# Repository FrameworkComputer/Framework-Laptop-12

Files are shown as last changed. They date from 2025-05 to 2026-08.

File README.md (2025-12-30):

# Framework Laptop 12
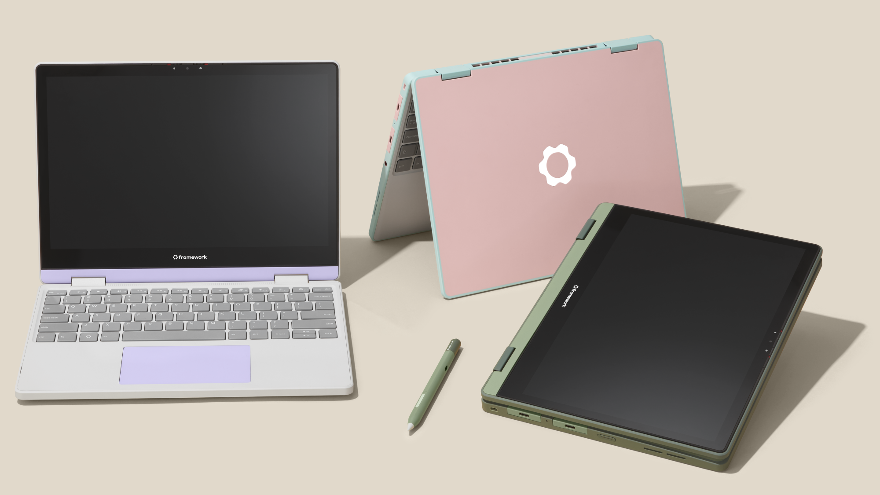
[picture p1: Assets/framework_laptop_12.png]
FrameworkLaptop12


Documentation around the Mainboard and other key parts of Framework Laptop 12 
(available at https://frame.work/marketplace/mainboards).

We designed Framework Laptop 12 to enable re-use of key modules like the Mainboard.
The Mainboard is operable as a standalone single board computer outside of the laptop,
with a smaller form factor relative to Framework Laptop 13.

## License

Framework Laptop 12 © 2024 by Framework Computer Inc is licensed under CC BY 4.0.
To view a copy of this license, visit http://creativecommons.org/licenses/by/4.0/

## 3D CAD (in the base directory)

External 3D CAD of the system and main modules to enable development of 3D-printed replacement parts,
skins, cases, and other accessories.  We're excited to see what you do with it!

## Mainboard
This folder contains interface and CAD documentation to enable Mainboard re-use.

## Input Cover

This folder contains interface documentation to enable Input Cover re-use.

## Display

Mechanical design files and pinout of the display.

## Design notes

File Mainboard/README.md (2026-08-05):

# Mainboard

## License

Framework Laptop 12 © 2024 by Framework Computer Inc is licensed under CC BY 4.0.
To view a copy of this license, visit http://creativecommons.org/licenses/by/4.0/

## Pinouts

### Webcam Interface

This is the interface to the webcam module.
This module has not only the webcam but also an accelerometer and a dual-output Hall Sensor.

| Pin | Signal | Notes |
|-----|--- |---|
| 1 | 3VL_EC | |
| 2 | TABLET_MODE# | Hall sensor tablet mode |
| 3 | LID_SW# | Hall sensor lid closed  |
| 4 | ACC_INT | G-Sensor interrupt |
| 5 | GND | |
| 6 | USB_DM | Camera USB |
| 7 | USB_DP | Camera USB |
| 8 | 3VS_CAM | Camera IC Power |
| 9 | CAM_SW | Camera privacy switch |
| 10  | DMIC_CLK | Digital Microphone |
| 11  | DMIC_DATA | Digital Microphone |
| 12  | MIC_SW | Mic privacy switch |
| 13  | ALS_INT# | Reserved |
| 14  | I2C_SCL | Accelerometer I2C |
| 15  | I2C_SDA | Accelerometer I2C |
| 16  | OS_DET_CAM | Reserved, pullup |
| 17  | GND | |
| 18  | NC | |
| 19  | NC | |
| 20  | NC | |

## Display Interface

IPEX 20879-030E connector used to interface to an eDP display.  Note that there are signals
defined for the I2C touchscreen. Note that pin 1 is on the left when looking at the receptacle on the Mainboard.

| Pin | Signal | Notes |
|-----|--- |---|
| 1 | PWR | Backlight power |
| 2 | PWR | |
| 3 | PWR | |
| 4 | NC | |
| 5 | GND | |
| 6 | GND | |
| 7 | EDP_AUXN | |
| 8 | EDP_AUXP | |
| 9 | GND | |
| 10  | EDP_TXP0 | |
| 11  | EDP_TXN0 | |
| 12  | GND | |
| 13  | EDP_TXN1 | |
| 14  | EDP_TXP1 | |
| 15  | GND | |
| 16  | EDP_HPD | Hotplug |
| 17  | BLK_PWM_LCD  | Backlight PWM |
| 18  | BKOFF# | Backlight enable |
| 19  | 3VS_EDP | |
| 20  | 3VS_EDP | |
| 21  | 3VS_EDP | |
| 22  | 3VS_TS | |
| 23  | 3VS_TS | |
| 24  | TS_EN | |
| 25  | TS_RST | |
| 26  | TS_INT# | |
| 27  | I2C_SDA | Touch I2C |
| 28  | I2C_SCL | Touch I2C |
| 29  | OS_DET_TS | Reserved, pullup |
| 30  | GND | |

## Audio Daughterboard Interface

Pin 1 is top left, counting zigzag left, right, left, right downwards.

| Pin | Signal |
|-----|---|
| 1 | SLEEVE |
| 2 | HPOUT_R |
| 3 | RING |
| 4 | A_GND |
| 5 | GND |
| 6 | HPOUT_L |
| 7 | JACK_PLUG |
| 8 | BOARD_ID  |
| 9 | SPK_L- |
| 10  | SPK_R- |
| 11  | SPK_L+ |
| 12  | SPK_R+ |

## Power Button Daughterboard Interface

Pin 1 is top left, counting zigzag left, right, left, right downwards.

| Pin | Signal | Notes |
|-----|---|---|
| 1 | USB_DP | USB2.0 Reserved |
| 2 | BOARD_ID | |
| 3 | USB_DM | USB2.0 Reserved |
| 4 | GND | |
| 5 | 3V_MCU | 3V Reserved |
| 6 | ON_OFF_BTN# | System Power Button |
| 7 | LED_PWM | Power Button LED |
| 8 | 5V_LED | Power Button LED |

## Battery 

Pin 1 is the left-most.

| Pin | Signal | Notes  |
|-----|---|---|
| 1 | BAT+ | 13.5V  |
| 2 | BAT+ | 13.5V  |
| 3 | VRTC | |
| 4 | DAT_SMB  | SMBus  |
| 5 | CLK_SMB  | SMBus  |
| 6 | SYS_PRES | |
| 7 | GND | |
| 8 | GND | |

The battery provides VRTC voltage to serve as RTC batteyr.

## Input Cover Interface

Connection is made through two sets of 10 pogo pins.
Pin count from left to right.

| Conn | Pin | Signal | Notes |
|---|-----|---|---|
| JTP1 | 1 | 5VS_TP | |
| JTP1 | 2 | KBL_P | |
| JTP1 | 3 | 3VS_TP | |
| JTP1 | 4 | TP_I2C_CLK | Touchpad I2C |
| JTP1 | 5 | TP_I2C_SDA | Touchpad I2C |
| JTP1 | 6 | TP_INT# | |
| JTP1 | 7 | BOARD_ID | |
| JTP1 | 8 | KB_I2C_SCL | Keyboard I2C |
| JTP1 | 9 | KB_I2C_SDA | Keyboard I2C |
| JTP1 | 10  | KB_INT | Keyboard I2C |
| JTP2 | 1 | KSI_03_IN  | Shorted to pin 2 |
| JTP2 | 2 | KSI_03_OUT | Shorted to pin 1 |
| JTP2 | 3 | KSI_02_IN  | Shorted to pin 4 |
| JTP2 | 4 | KSI_02_OUT | Shorted to pin 3 |
| JTP2 | 5 | KSI_00_IN  | Shorted to pin 6 |
| JTP2 | 6 | KSI_00_OUT | Shorted to pin 5 |
| JTP2 | 7 | GND | |
| JTP2 | 8 | GND | |
| JTP2 | 9 | GND | |
| JTP2 | 10  | GND | |

Keyboard scan and capslock LED control is going through the I2C keyboard controller.

## Fan Interface

Hefeng AWA02-S04FIA-HF connector for the Fan.  Note that there are many other footprint
compatible 4-pin connectors that are likely compatible. This kind of connector is also known
as "JST SH", and has a 1.0 mm pitch. The same connector is used for the Speakers.

Pin 1 is further away from the speaker assembly.

| Pin | Signal |
|-----|---|
| 1 | 5V |
| 2 | FAN_SPEED |
| 3 | FAN_PWM |
| 4 | GND |

## RTC Battery Interface

NOTE: The mainboard will charge this battery, so a rechargable ML1220 battery must be used.
CR2032 is not okay because it cannot be charged.

Settings are kept alive by the normal system battery. The only case where an
RTC battery is needed, is when the system is used in standalone mode (without a battery).

Cvilux CVILU_CI4402M1HRC-NH connector for the RTC Battery.

| Pin | Signal | Location |
|-----|---|---|
| 1 | +RTCBATT  | Left |
| 2 | GND | Right |

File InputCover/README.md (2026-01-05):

# Input Cover

## License

Framework Laptop 12 © 2025 by Framework Computer Inc is licensed under CC BY 4.0.
To view a copy of this license, visit http://creativecommons.org/licenses/by/4.0/

## Layout

The input cover includes the touchpad and keyboard.
There is one main PCB, which we will call the touchpad PCB.
It includes the Pixart PCT2642QC (PLP239 Family) touchpad IC and IT8801 keyboard controler.

The keyboard matrix connects to the touchpad PCB through an FPC connector.

## Touchpad Module Details

For details about the touchpad module, including silkscreen and firmware,
please refer to [Touchpad.md].

## Pinouts

### Touchpad PCB to Mainboard

Connection is made through an FPC daughterboard that has pads for two sets of 10 pogo pins.
See the pinout for that on the mainboard README.md

Pinout for FPC connector on the touchpad PCB to the pogo pin daughterboard.
The `5VS_TP` and `KBL_P` pins are duplicated on this FPC connector, but not on the pogo pins.

KSI0, KSI3, and KSO2 are routed to the mainboard and back out for the possibility of letting a future mainboard scan the F1 and F2 keys directly, bypasing the keyboard controller IC.
On current hardware IN OUT pins are just shorted together on the mainboard.

| Pin | Signal | Notes |
|-----|---|---|
| 1 | 5VS_TP | |
| 2 | 5VS_TP | |
| 3 | KBL_P | |
| 4 | KBL_P | |
| 5 | 3VS_TP | |
| 6 | TP_I2C_CLK | Touchpad I2C |
| 7 | TP_I2C_SDA | Touchpad I2C |
| 8 | TP_INT# | |
| 9 | BOARD_ID | |
| 10  | KB_I2C_SCL | Keyboard I2C |
| 11  | KB_I2C_SDA | Keyboard I2C |
| 12  | KB_INT | Keyboard I2C |
| 13  | KSI_03_IN  | |
| 14  | KSI_03_OUT | |
| 15  | KSI_02_IN  | |
| 16  | KSI_02_OUT | |
| 17  | KSI_00_IN  | |
| 18  | KSI_00_OUT | |
| 19  | GND | |
| 20  | GND | |
| 21  | GND | |
| 22  | GND | |

### Touchpad to Keyboard

| Pin | Signal |
|-----|---|
| 1 | KSI_00_IN  |
| 2 | KSI1 |
| 3 | KSI2 |
| 4 | KSI_03_IN  |
| 5 | KSI4 |
| 6 | KSI5 |
| 7 | KSI6 |
| 8 | KSI7 |
| 9 | KSO0 |
| 10  | KSO1 |
| 11  | KSO_02_IN  |
| 12  | KSO3 |
| 13  | KSO4 |
| 14  | KSO5 |
| 15  | KSO6 |
| 16  | KSO7 |
| 17  | KSO8 |
| 18  | KSO9 |
| 19  | KSO10 |
| 20  | KSO11 |
| 21  | KSO12 |
| 22  | KSO13 |
| 23  | KSO14 |
| 24  | KSO15 |
| 25  | KSO16 |
| 26  | KSO17 |
| 27  | CAPS_P |
| 28  | CAPS_N |

## Keyboard

### Keyboard Matrix

ANSI layout:

```
┌─────┬───┬───┬───┬───┬───┬───┬───┬───┬───┬───┬───┬───┬────┐
│ Esc │F1 │F2 │F3 │F4 │F5 │F6 │F7 │F8 │F9 │F10│F11│F12│ Del│
├───┬─┴─┬─┴─┬─┴─┬─┴─┬─┴─┬─┴─┬─┴─┬─┴─┬─┴─┬─┴─┬─┴─┬─┴─┬─┴────┤
│ ` │ 1 │ 2 │ 3 │ 4 │ 5 │ 6 │ 7 │ 8 │ 9 │ 0 │ - │ = │Backsp│
├───┴─┬─┴─┬─┴─┬─┴─┬─┴─┬─┴─┬─┴─┬─┴─┬─┴─┬─┴─┬─┴─┬─┴─┬─┴─┬────┤
│ Tab │ Q │ W │ E │ R │ T │ Y │ U │ I │ O │ P │ [ │ ] │ \  │
├─────┴┬──┴┬──┴┬──┴┬──┴┬──┴┬──┴┬──┴┬──┴┬──┴┬──┴┬──┴┬──┴────┤
│ Caps │ A │ S │ D │ F │ G │ H │ J │ K │ L │ ; │ ' │ Enter │
├──────┴─┬─┴─┬─┴─┬─┴─┬─┴─┬─┴─┬─┴─┬─┴─┬─┴─┬─┴─┬─┴─┬─┴───────┤
│ Shift  │ Z │ X │ C │ V │ B │ N │ M │ , │ . │ / │  Shift  │
├────┬───┼───┼───┼───┴───┴───┴───┴───┼───┼───┼───┴┬───┬────┤
│    │   │   │   │                   │   │   │    │ ↑ │    │
│Ctrl│FN │WIN│Alt│                   │Alt│Ctl│ ←  ├───┤  → │
│    │   │   │   │                   │   │   │    │ ↓ │    │
└────┴───┴───┴───┴───────────────────┴───┴───┴────┴───┴────┘
|     |Col 0|Col 1|Col 2|Col 3|Col 4|Col 5|Col 6|Col 7|Col 8|Col 9|Col10|Col11|Col12|Col13|Col14|Col15|Col16|Col17|
|Row 0|     | F11 | F1  | B   | F10 | N   |     |     | =   |     |RAlt |     |     |     |     |     | FN  |     |
|Row 1|     | ESC | F4  | G   | F7  | F12 | H   |     | '   | F9  |     | Bsp |     |     |LCtrl|     |     |     |
|Row 2|     | TAB | F3  | T   | F6  | ]   | Y   |     | [   | Del |     | F8  |     |     |     |     |     |     |
|Row 3| WIN | `   | F2  | 5   | S   |     | -   |     | 6   |     |     | \   |     |     |RCtrl|     |     |     |
|Row 4|     | A   | D   | F   | F5  | K   | J   |     | ;   | L   |     |Enter|     |     |     |     |     |     |
|Row 5|     | 1   | ,   | >   | /   | C   |Space|LShft| X   | V   |     | M   |     |     |     |     |     |     |
|Row 6|     | Z   | 3   | 4   | 2   | 8   | 0   |     | 7   | 9   |     | Down|Left |LAlt |     |CapsL|     |     |
|Row 7|     | U   | I   | O   | P   | Q   | W   |RShft| E   | R   |     | Up  |Right|     |     |     |     |     |
```

ISO Layout:

```
┌─────┬───┬───┬───┬───┬───┬───┬───┬───┬───┬───┬───┬───┬────┐
│ Esc │F1 │F2 │F3 │F4 │F5 │F6 │F7 │F8 │F9 │F10│F11│F12│ Del│
├───┬─┴─┬─┴─┬─┴─┬─┴─┬─┴─┬─┴─┬─┴─┬─┴─┬─┴─┬─┴─┬─┴─┬─┴─┬─┴────┤
│ ` │ 1 │ 2 │ 3 │ 4 │ 5 │ 6 │ 7 │ 8 │ 9 │ 0 │ - │ = │Backsp│
├───┴─┬─┴─┬─┴─┬─┴─┬─┴─┬─┴─┬─┴─┬─┴─┬─┴─┬─┴─┬─┴─┬─┴─┬─┴─┬────┤
│ Tab │ Q │ W │ E │ R │ T │ Y │ U │ I │ O │ P │ [ │ ] │Entr│
├─────┴┬──┴┬──┴┬──┴┬──┴┬──┴┬──┴┬──┴┬──┴┬──┴┬──┴┬──┴┬──┴┐   │
│ Caps │ A │ S │ D │ F │ G │ H │ J │ K │ L │ ; │ ' │ # │   │
├────┬─┴─┬─┴─┬─┴─┬─┴─┬─┴─┬─┴─┬─┴─┬─┴─┬─┴─┬─┴─┬─┴─┬─┴───┴───┤
│Shft│ \ │ Z │ X │ C │ V │ B │ N │ M │ , │ . │ / │  Shift  │
├────┼───┼───┼───┼───┴───┴───┴───┴───┼───┼───┼───┴┬───┬────┤
│    │   │   │   │                   │   │   │    │ ↑ │    │
│Ctrl│FN │WIN│Alt│                   │Alt│Ctl│ ←  ├───┤  → │
│    │   │   │   │                   │   │   │    │ ↓ │    │
└────┴───┴───┴───┴───────────────────┴───┴───┴────┴───┴────┘
|     |Col 0|Col 1|Col 2|Col 3|Col 4|Col 5|Col 6|Col 7|Col 8|Col 9|Col10|Col11|Col12|Col13|Col14|Col15|Col16|Col17|
|Row 0|     | F11 | F1  | B   | F10 | N   |     |     | =   |     |RAlt |     |     |     |     |     | FN  |     |
|Row 1|     | ESC | F4  | G   | F7  | F12 | H   |     | '   | F9  |     | Bsp |     |     |LCtrl|     |     |     |
|Row 2|     | TAB | F3  | T   | F6  | ]   | Y   |     | [   | Del |     | F8  |     |     |     |     |     |     |
|Row 3| WIN | `   | F2  | 5   | S   |     | -   |     | 6   |     |     |     |     |     |RCtrl|     |     |     |
|Row 4|     | A   | D   | F   | F5  | K   | J   |     | ;   | L   |     |Enter|     |     |     |     |     |     |
|Row 5|     | 1   | ,   | >   | /   | C   |Space|LShft| X   | V   |     | M   |     |     |     |     |     |     |
|Row 6|     | Z   | 3   | 4   | 2   | 8   | 0   |     | 7   | 9   |     | Down|Left |LAlt |     |CapsL|     | #   |
|Row 7|     | U   | I   | O   | P   | Q   | W   |RShft| E   | R   |     | Up  |Right|     |     |     |     | \   |
```

### Rollover

Like most laptop keyboards, the Framework Laptop 12 and Laptop 13 do not support full n-key rollover.
That means the system recognizes only a limited number of keys pressed at the same time.

The limitation is in hardware - the key switches would have to have diodes or other mechanisms to avoid ghosting.
See: https://en.wikipedia.org/wiki/Key_rollover#Key_jamming_and_ghosting

Framework Laptop 16 was with gaming in mind, where you need to press many keys at the same time.
It has resistors on each key and uses analog scanning to detect which keys are
pressed and achieves almost full n-key rollover.

Framework Laptop 12 and 13 do not have any special mechanism.
They do have a matrix that is optimized to avoid issues with the most common
key combinations when typing and using shortcuts.
So while at minimum two, in most cases many more keys, up to 12 keys can be registered at the same time.
Keys that are commonly used with others are not placed in the same row or column as each other.

See that the control, shift, alt keys, as well as fn, left/right, windows are
placed in their own column each and not in the same rows.

However, since n-key rollover is not supported and the matrix is a limited size, some combinations are not possible.
As explained in the linked Wikipedia article, this happens if three keys share the same two rows and same two columns.
The firmware is not able to determine if three or four keys are pressed - to avoid "ghost keys", it ignores both.

One example of those combinations is: Left/Right Shift + W + Space

```
|       |Col 6|Col 7|
| Row 5 |Space|LShft|
| Row 7 | W   |RShft|
```

Why we chose this matrix. The Framework Laptop 13 has a custom matrix. When we
made the Framework Laptop 13 ChromeOS Edition, we had to make a separate
version of the keyboard and input deck to meet the ChromeOS requirements.
ChromeOS didn't have a Windows/Linux compatible matrix at that time - now they
do, so with compatibility in mind, we picked their new standard
["Straus" Keyboard](https://chromium.googlesource.com/chromiumos/platform/ec/+/HEAD/common/keyboard_strauss.c).

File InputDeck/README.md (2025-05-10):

# Input Deck

## License

Framework Laptop 12 © 2025 by Framework Computer Inc is licensed under CC BY 4.0.
To view a copy of this license, visit http://creativecommons.org/licenses/by/4.0/

## Layout

The input deck includes the touchpad and keyboard.
There is one main PCB, which we will call the touchpad PCB.
It includes the Pixart 239 touchpad IC and IT8801 keyboard controler.

The keyboard matrix connects to the touchpad PCB through an FPC connector.

## Pinouts

### Touchpad PCB to Mainboard

Connection is made through an FPC daughterboard that has pads for two sets of 10 pogo pins.
See the pinout for that on the mainboard README.md

Pinout for touchpad PCB to the daughterboard:

| Pin | Signal | Notes |
|-----|---|---|
| 1 | 5VS_TP | |
| 2 | 5VS_TP | |
| 3 | KBL_P | |
| 4 | KBL_P | |
| 5 | 3VS_TP | |
| 6 | TP_I2C_CLK | Touchpad I2C |
| 7 | TP_I2C_SDA | Touchpad I2C |
| 8 | TP_INT# | |
| 9 | BOARD_ID | |
| 10  | KB_I2C_SCL | Keyboard I2C |
| 11  | KB_I2C_SDA | Keyboard I2C |
| 12  | KB_INT | Keyboard I2C |
| 13  | KSI_03_IN  | Shorted to pin 2 |
| 14  | KSI_03_OUT | Shorted to pin 1 |
| 15  | KSI_02_IN  | Shorted to pin 4 |
| 16  | KSI_02_OUT | Shorted to pin 3 |
| 17  | KSI_00_IN  | Shorted to pin 6 |
| 18  | KSI_00_OUT | Shorted to pin 5 |
| 19  | GND | |
| 20  | GND | |
| 21  | GND | |
| 22  | GND | |

### Touchpad to Keyboard

| Pin | Signal |
|-----|---|
| 1 | KSI_00_IN  |
| 2 | KSI1 |
| 3 | KSI2 |
| 4 | KSI_03_IN  |
| 5 | KSI4 |
| 6 | KSI5 |
| 7 | KSI6 |
| 8 | KSI7 |
| 9 | KSO0 |
| 10  | KSO1 |
| 11  | KSO_02_IN  |
| 12  | KSO3 |
| 13  | KSO4 |
| 14  | KSO5 |
| 15  | KSO6 |
| 16  | KSO7 |
| 17  | KSO8 |
| 18  | KSO9 |
| 19  | KSO10 |
| 20  | KSO11 |
| 21  | KSO12 |
| 22  | KSO13 |
| 23  | KSO14 |
| 24  | KSO15 |
| 25  | KSO16 |
| 26  | KSO17 |
| 27  | CAPS_P |
| 28  | CAPS_N |

## Keyboard

### Keyboard Matrix

ANSI layout:

```
|     |Col 0|Col 1|Col 2|Col 3|Col 4|Col 5|Col 6|Col 7|Col 8|Col 9|Col10|Col11|Col12|Col13|Col14|Col15|Col16|Col17|
|Row 0|     | F11 | F1  | B   | F10 | N   |     |     | =   |     |RAlt |     |     |     |     |     | FN  |     |
|Row 1|     | ESC | F4  | G   | F7  | F12 | H   |     | '   | F9  |     | Bsp |     |     |LCtrl|     |     |     |
|Row 2|     | TAB | F3  | T   | F6  | ]   | Y   |     | [   | Del |     | F8  |     |     |     |     |     |     |
|Row 3| WIN | `   | F2  | 5   | S   |     | -   |     | 6   |     |     | |   |     |     |RCtrl|     |     |     |
|Row 4|     | A   | D   | F   | F5  | K   | J   |     | ;   | L   |     |Enter|     |     |     |     |     |     |
|Row 5|     | 1   | ,   | >   | /   | C   |Space|LShft| X   | V   |     | M   |     |     |     |     |     |     |
|Row 6|     | Z   | 3   | 4   | 2   | 8   | 0   |     | 7   | 9   |     | Down|Left |LAlt |     |CapsL|     |     |
|Row 7|     | U   | I   | O   | P   | Q   | W   |RShft| E   | R   |     | Up  |Right|     |     |     |     |     |
```

Missing on ANSI: 14, 42, 45, 56, 63, 65, 80, 81, 85, 86

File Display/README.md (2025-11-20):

# Display

## Mechanical

A 2D drawing of the Display Module for use in creating screen protectors.
Note that the cutout for the webcam is needed, but the LED can shine through
most types of screen protector materials.

## Electrical

### Connectors

Display eDP

| Pin | Signal | Notes |
|-----|---|---|
| 1 | NC | |
| 2 | GND | |
| 3 | EDP_TXN1 | eDP Lane 1 |
| 4 | EDP_TXP1 | eDP Lane 1 |
| 5 | H_GND | |
| 61  | EDP_TXN0 | eDP Lane 0 |
| 70  | EDP_TXP0 | eDP Lane 0 |
| 7 | H_GND | |
| 9 | EDP_AUXP | eDP Auxiliary Channel |
| 10  | EDP_AUXN | eDP Auxiliary Channel |
| 11  | H_GND | |
| 12  | 3VS_EDP | 3VS |
| 13  | 3VS_EDP | 3VS |
| 14  | NC | |
| 15  | H_GND | |
| 16  | H_GND | |
| 17  | EDP_HPD | Hotplug |
| 18  | BL_GND | |
| 19  | BL_GND | |
| 10  | BL_GND | |
| 21  | BL_GND | |
| 22  | BKOFF# | Backlight enable |
| 23  | BLK_PWM_LCD  | Backlight PWM |
| 24  | NC | |
| 25  | NC | |
| 26  | BL_POWER | |
| 27  | BL_POWER | Touch I2C |
| 28  | BL_POWER | Touch I2C |
| 29  | BL_POWER | Reserved, pullup |
| 30  | NC | |

Touch

| Pin | Signal | Notes |
|-----|--- |---|
|  1  | 3VS_TS | |
|  2  | TS_EN | |
|  3  | TS_RST | |
|  4  | TS_INT# | |
|  5  | I2C_SDA | Touch I2C |
|  6  | I2C_SCL | Touch I2C |
|  7  | OS_DET_TS | Reserved, pullup |
|  8  | GND | |

### Silkscreen

| Label  | Type | Description |
|---|---|---|
| OS_DET | Testpoint | Reserved |
| SCL | Testpoint | I2C SCL |
| SDA | Testpoint | I2C SDA |
| INT | Testpoint | I2C Interrupt |
| RST | Testpoint | Touch IC Reset |
| TPEN | Testpoint | Touch Enable |
| VDD33  | Testpoint | 3.3V |
| GND | Testpoint | Ground |

## Touch IC Firmware

The touchscreen IC presents as an I2C HID device at address 0x41.

## Firmware Update

Firmware is updated through I2C HID.

Ilitek provides a proprietary windows update tool
For Linux/ChromeOS they originally provided a [custom update tool](https://github.com/ITS-Tool/ilitek_ld_tool),
which is now superceded by [fwupd](https://github.com/fwupd/fwupd/tree/main/plugins/ilitek-its) on Linux.

So far Framework has not shipped a public touchscreen firmware update.
The current and future firmware updates are avilable on [LVFS](https://fwupd.org/lvfs/devices/work.frame.Laptop12.RPL.touchscreen.firmware).

## HID Reports
Below the HID Report descriptor and details about some reports are documented.

In the BIOS settings the touchscreen can be changed between MPP and USI
reporting modes. The HID report descriptor changes to accomodate each protocol.

### USI HID Report Descriptor

```
# 0x05, 0x0d,                    // Usage Page (Digitizers)             0
# 0x09, 0x04,                    // Usage (Touch Screen)                2
# 0xa1, 0x01,                    // Collection (Application)            4
# 0x85, 0x04,                    //  Report ID (4)                      6
# 0x05, 0x0d,                    //  Usage Page (Digitizers)            8
# 0x09, 0x22,                    //  Usage (Finger)                     10
# 0xa1, 0x02,                    //  Collection (Logical)               12
# 0x05, 0x0d,                    //   Usage Page (Digitizers)           14
# 0x95, 0x01,                    //   Report Count (1)                  16
# 0x75, 0x06,                    //   Report Size (6)                   18
# 0x09, 0x51,                    //   Usage (Contact Id)                20
# 0x15, 0x00,                    //   Logical Minimum (0)               22
# 0x25, 0x3f,                    //   Logical Maximum (63)              24
# 0x81, 0x02,                    //   Input (Data,Var,Abs)              26
# 0x09, 0x42,                    //   Usage (Tip Switch)                28
# 0x25, 0x01,                    //   Logical Maximum (1)               30
# 0x75, 0x01,                    //   Report Size (1)                   32
# 0x95, 0x01,                    //   Report Count (1)                  34
# 0x81, 0x02,                    //   Input (Data,Var,Abs)              36
# 0x09, 0x47,                    //   Usage (Confidence)                38
# 0x75, 0x01,                    //   Report Size (1)                   40
# 0x81, 0x02,                    //   Input (Data,Var,Abs)              42
# 0x05, 0x01,                    //   Usage Page (Generic Desktop)      44
# 0x75, 0x10,                    //   Report Size (16)                  46
# 0x55, 0x0e,                    //   Unit Exponent (-2)                48
# 0x65, 0x11,                    //   Unit (SILinear: cm)               50
# 0x09, 0x30,                    //   Usage (X)                         52
# 0x26, 0x00, 0x40,              //   Logical Maximum (16384)           54
# 0x35, 0x00,                    //   Physical Minimum (0)              57
# 0x46, 0x43, 0x0a,              //   Physical Maximum (2627)           59
# 0x81, 0x42,                    //   Input (Data,Var,Abs,Null)         62
# 0x09, 0x31,                    //   Usage (Y)                         64
# 0x26, 0x80, 0x25,              //   Logical Maximum (9600)            66
# 0x46, 0x6a, 0x06,              //   Physical Maximum (1642)           69
# 0x81, 0x42,                    //   Input (Data,Var,Abs,Null)         72
# 0x95, 0x01,                    //   Report Count (1)                  74
# 0x75, 0x08,                    //   Report Size (8)                   76
# 0x81, 0x03,                    //   Input (Cnst,Var,Abs)              78
# 0x05, 0x0d,                    //   Usage Page (Digitizers)           80
# 0x26, 0xff, 0x7f,              //   Logical Maximum (32767)           82
# 0x09, 0x48,                    //   Usage (Width)                     85
# 0x75, 0x10,                    //   Report Size (16)                  87
# 0x95, 0x01,                    //   Report Count (1)                  89
# 0x81, 0x02,                    //   Input (Data,Var,Abs)              91
# 0x09, 0x49,                    //   Usage (Height)                    93
# 0x81, 0x02,                    //   Input (Data,Var,Abs)              95
# 0xc0,                          //  End Collection                     97
# 0x05, 0x0d,                    //  Usage Page (Digitizers)            98
# 0x09, 0x22,                    //  Usage (Finger)                     100
# 0xa1, 0x02,                    //  Collection (Logical)               102
# 0x05, 0x0d,                    //   Usage Page (Digitizers)           104
# 0x95, 0x01,                    //   Report Count (1)                  106
# 0x75, 0x06,                    //   Report Size (6)                   108
# 0x09, 0x51,                    //   Usage (Contact Id)                110
# 0x15, 0x00,                    //   Logical Minimum (0)               112
# 0x25, 0x3f,                    //   Logical Maximum (63)              114
# 0x81, 0x02,                    //   Input (Data,Var,Abs)              116
# 0x09, 0x42,                    //   Usage (Tip Switch)                118
# 0x25, 0x01,                    //   Logical Maximum (1)               120
# 0x75, 0x01,                    //   Report Size (1)                   122
# 0x95, 0x01,                    //   Report Count (1)                  124
# 0x81, 0x02,                    //   Input (Data,Var,Abs)              126
# 0x09, 0x47,                    //   Usage (Confidence)                128
# 0x75, 0x01,                    //   Report Size (1)                   130
# 0x81, 0x02,                    //   Input (Data,Var,Abs)              132
# 0x05, 0x01,                    //   Usage Page (Generic Desktop)      134
# 0x75, 0x10,                    //   Report Size (16)                  136
# 0x55, 0x0e,                    //   Unit Exponent (-2)                138
# 0x65, 0x11,                    //   Unit (SILinear: cm)               140
# 0x09, 0x30,                    //   Usage (X)                         142
# 0x26, 0x00, 0x40,              //   Logical Maximum (16384)           144
# 0x35, 0x00,                    //   Physical Minimum (0)              147
# 0x46, 0x43, 0x0a,              //   Physical Maximum (2627)           149
# 0x81, 0x42,                    //   Input (Data,Var,Abs,Null)         152
# 0x09, 0x31,                    //   Usage (Y)                         154
# 0x26, 0x80, 0x25,              //   Logical Maximum (9600)            156
# 0x46, 0x6a, 0x06,              //   Physical Maximum (1642)           159
# 0x81, 0x42,                    //   Input (Data,Var,Abs,Null)         162
# 0x95, 0x01,                    //   Report Count (1)                  164
# 0x75, 0x08,                    //   Report Size (8)                   166
# 0x81, 0x03,                    //   Input (Cnst,Var,Abs)              168
# 0x05, 0x0d,                    //   Usage Page (Digitizers)           170
# 0x26, 0xff, 0x7f,              //   Logical Maximum (32767)           172
# 0x09, 0x48,                    //   Usage (Width)                     175
# 0x75, 0x10,                    //   Report Size (16)                  177
# 0x95, 0x01,                    //   Report Count (1)                  179
# 0x81, 0x02,                    //   Input (Data,Var,Abs)              181
# 0x09, 0x49,                    //   Usage (Height)                    183
# 0x81, 0x02,                    //   Input (Data,Var,Abs)              185
# 0xc0,                          //  End Collection                     187
# 0x05, 0x0d,                    //  Usage Page (Digitizers)            188
# 0x09, 0x22,                    //  Usage (Finger)                     190
# 0xa1, 0x02,                    //  Collection (Logical)               192
# 0x05, 0x0d,                    //   Usage Page (Digitizers)           194
# 0x95, 0x01,                    //   Report Count (1)                  196
# 0x75, 0x06,                    //   Report Size (6)                   198
# 0x09, 0x51,                    //   Usage (Contact Id)                200
# 0x15, 0x00,                    //   Logical Minimum (0)               202
# 0x25, 0x3f,                    //   Logical Maximum (63)              204
# 0x81, 0x02,                    //   Input (Data,Var,Abs)              206
# 0x09, 0x42,                    //   Usage (Tip Switch)                208
# 0x25, 0x01,                    //   Logical Maximum (1)               210
# 0x75, 0x01,                    //   Report Size (1)                   212
# 0x95, 0x01,                    //   Report Count (1)                  214
# 0x81, 0x02,                    //   Input (Data,Var,Abs)              216
# 0x09, 0x47,                    //   Usage (Confidence)                218
# 0x75, 0x01,                    //   Report Size (1)                   220
# 0x81, 0x02,                    //   Input (Data,Var,Abs)              222
# 0x05, 0x01,                    //   Usage Page (Generic Desktop)      224
# 0x75, 0x10,                    //   Report Size (16)                  226
# 0x55, 0x0e,                    //   Unit Exponent (-2)                228
# 0x65, 0x11,                    //   Unit (SILinear: cm)               230
# 0x09, 0x30,                    //   Usage (X)                         232
# 0x26, 0x00, 0x40,              //   Logical Maximum (16384)           234
# 0x35, 0x00,                    //   Physical Minimum (0)              237
# 0x46, 0x43, 0x0a,              //   Physical Maximum (2627)           239
# 0x81, 0x42,                    //   Input (Data,Var,Abs,Null)         242
# 0x09, 0x31,                    //   Usage (Y)                         244
# 0x26, 0x80, 0x25,              //   Logical Maximum (9600)            246
# 0x46, 0x6a, 0x06,              //   Physical Maximum (1642)           249
# 0x81, 0x42,                    //   Input (Data,Var,Abs,Null)         252
# 0x95, 0x01,                    //   Report Count (1)                  254
# 0x75, 0x08,                    //   Report Size (8)                   256
# 0x81, 0x03,                    //   Input (Cnst,Var,Abs)              258
# 0x05, 0x0d,                    //   Usage Page (Digitizers)           260
# 0x26, 0xff, 0x7f,              //   Logical Maximum (32767)           262
# 0x09, 0x48,                    //   Usage (Width)                     265
# 0x75, 0x10,                    //   Report Size (16)                  267
# 0x95, 0x01,                    //   Report Count (1)                  269
# 0x81, 0x02,                    //   Input (Data,Var,Abs)              271
# 0x09, 0x49,                    //   Usage (Height)                    273
# 0x81, 0x02,                    //   Input (Data,Var,Abs)              275
# 0xc0,                          //  End Collection                     277
# 0x05, 0x0d,                    //  Usage Page (Digitizers)            278
# 0x09, 0x22,                    //  Usage (Finger)                     280
# 0xa1, 0x02,                    //  Collection (Logical)               282
# 0x05, 0x0d,                    //   Usage Page (Digitizers)           284
# 0x95, 0x01,                    //   Report Count (1)                  286
# 0x75, 0x06,                    //   Report Size (6)                   288
# 0x09, 0x51,                    //   Usage (Contact Id)                290
# 0x15, 0x00,                    //   Logical Minimum (0)               292
# 0x25, 0x3f,                    //   Logical Maximum (63)              294
# 0x81, 0x02,                    //   Input (Data,Var,Abs)              296
# 0x09, 0x42,                    //   Usage (Tip Switch)                298
# 0x25, 0x01,                    //   Logical Maximum (1)               300
# 0x75, 0x01,                    //   Report Size (1)                   302
# 0x95, 0x01,                    //   Report Count (1)                  304
# 0x81, 0x02,                    //   Input (Data,Var,Abs)              306
# 0x09, 0x47,                    //   Usage (Confidence)                308
# 0x75, 0x01,                    //   Report Size (1)                   310
# 0x81, 0x02,                    //   Input (Data,Var,Abs)              312
# 0x05, 0x01,                    //   Usage Page (Generic Desktop)      314
# 0x75, 0x10,                    //   Report Size (16)                  316
# 0x55, 0x0e,                    //   Unit Exponent (-2)                318
# 0x65, 0x11,                    //   Unit (SILinear: cm)               320
# 0x09, 0x30,                    //   Usage (X)                         322
# 0x26, 0x00, 0x40,              //   Logical Maximum (16384)           324
# 0x35, 0x00,                    //   Physical Minimum (0)              327
# 0x46, 0x43, 0x0a,              //   Physical Maximum (2627)           329
# 0x81, 0x42,                    //   Input (Data,Var,Abs,Null)         332
# 0x09, 0x31,                    //   Usage (Y)                         334
# 0x26, 0x80, 0x25,              //   Logical Maximum (9600)            336
# 0x46, 0x6a, 0x06,              //   Physical Maximum (1642)           339
# 0x81, 0x42,                    //   Input (Data,Var,Abs,Null)         342
# 0x95, 0x01,                    //   Report Count (1)                  344
# 0x75, 0x08,                    //   Report Size (8)                   346
# 0x81, 0x03,                    //   Input (Cnst,Var,Abs)              348
# 0x05, 0x0d,                    //   Usage Page (Digitizers)           350
# 0x26, 0xff, 0x7f,              //   Logical Maximum (32767)           352
# 0x09, 0x48,                    //   Usage (Width)                     355
# 0x75, 0x10,                    //   Report Size (16)                  357
# 0x95, 0x01,                    //   Report Count (1)                  359
# 0x81, 0x02,                    //   Input (Data,Var,Abs)              361
# 0x09, 0x49,                    //   Usage (Height)                    363
# 0x81, 0x02,                    //   Input (Data,Var,Abs)              365
# 0xc0,                          //  End Collection                     367
# 0x05, 0x0d,                    //  Usage Page (Digitizers)            368
# 0x09, 0x22,                    //  Usage (Finger)                     370
# 0xa1, 0x02,                    //  Collection (Logical)               372
# 0x05, 0x0d,                    //   Usage Page (Digitizers)           374
# 0x95, 0x01,                    //   Report Count (1)                  376
# 0x75, 0x06,                    //   Report Size (6)                   378
# 0x09, 0x51,                    //   Usage (Contact Id)                380
# 0x15, 0x00,                    //   Logical Minimum (0)               382
# 0x25, 0x3f,                    //   Logical Maximum (63)              384
# 0x81, 0x02,                    //   Input (Data,Var,Abs)              386
# 0x09, 0x42,                    //   Usage (Tip Switch)                388
# 0x25, 0x01,                    //   Logical Maximum (1)               390
# 0x75, 0x01,                    //   Report Size (1)                   392
# 0x95, 0x01,                    //   Report Count (1)                  394
# 0x81, 0x02,                    //   Input (Data,Var,Abs)              396
# 0x09, 0x47,                    //   Usage (Confidence)                398
# 0x75, 0x01,                    //   Report Size (1)                   400
# 0x81, 0x02,                    //   Input (Data,Var,Abs)              402
# 0x05, 0x01,                    //   Usage Page (Generic Desktop)      404
# 0x75, 0x10,                    //   Report Size (16)                  406
# 0x55, 0x0e,                    //   Unit Exponent (-2)                408
# 0x65, 0x11,                    //   Unit (SILinear: cm)               410
# 0x09, 0x30,                    //   Usage (X)                         412
# 0x26, 0x00, 0x40,              //   Logical Maximum (16384)           414
# 0x35, 0x00,                    //   Physical Minimum (0)              417
# 0x46, 0x43, 0x0a,              //   Physical Maximum (2627)           419
# 0x81, 0x42,                    //   Input (Data,Var,Abs,Null)         422
# 0x09, 0x31,                    //   Usage (Y)                         424
# 0x26, 0x80, 0x25,              //   Logical Maximum (9600)            426
# 0x46, 0x6a, 0x06,              //   Physical Maximum (1642)           429
# 0x81, 0x42,                    //   Input (Data,Var,Abs,Null)         432
# 0x95, 0x01,                    //   Report Count (1)                  434
# 0x75, 0x08,                    //   Report Size (8)                   436
# 0x81, 0x03,                    //   Input (Cnst,Var,Abs)              438
# 0x05, 0x0d,                    //   Usage Page (Digitizers)           440
# 0x26, 0xff, 0x7f,              //   Logical Maximum (32767)           442
# 0x09, 0x48,                    //   Usage (Width)                     445
# 0x75, 0x10,                    //   Report Size (16)                  447
# 0x95, 0x01,                    //   Report Count (1)                  449
# 0x81, 0x02,                    //   Input (Data,Var,Abs)              451
# 0x09, 0x49,                    //   Usage (Height)                    453
# 0x81, 0x02,                    //   Input (Data,Var,Abs)              455
# 0xc0,                          //  End Collection                     457
# 0x55, 0x0c,                    //  Unit Exponent (-4)                 458
# 0x66, 0x01, 0x10,              //  Unit (SILinear: s)                 460
# 0x35, 0x00,                    //  Physical Minimum (0)               463
# 0x47, 0xff, 0xff, 0x00, 0x00,  //  Physical Maximum (65535)           465
# 0x15, 0x00,                    //  Logical Minimum (0)                470
# 0x27, 0xff, 0xff, 0x00, 0x00,  //  Logical Maximum (65535)            472
# 0x75, 0x10,                    //  Report Size (16)                   477
# 0x95, 0x01,                    //  Report Count (1)                   479
# 0x05, 0x0d,                    //  Usage Page (Digitizers)            481
# 0x09, 0x56,                    //  Usage (Scan Time)                  483
# 0x81, 0x02,                    //  Input (Data,Var,Abs)               485
# 0x95, 0x08,                    //  Report Count (8)                   487
# 0x75, 0x08,                    //  Report Size (8)                    489
# 0x81, 0x03,                    //  Input (Cnst,Var,Abs)               491
# 0x05, 0x0d,                    //  Usage Page (Digitizers)            493
# 0x09, 0x54,                    //  Usage (Contact Count)              495
# 0x25, 0x7f,                    //  Logical Maximum (127)              497
# 0x95, 0x01,                    //  Report Count (1)                   499
# 0x75, 0x08,                    //  Report Size (8)                    501
# 0x81, 0x02,                    //  Input (Data,Var,Abs)               503
# 0x95, 0x02,                    //  Report Count (2)                   505
# 0x75, 0x08,                    //  Report Size (8)                    507
# 0x81, 0x03,                    //  Input (Cnst,Var,Abs)               509
# 0x85, 0x02,                    //  Report ID (2)                      511
# 0x09, 0x55,                    //  Usage (Contact Max)                513
# 0x25, 0x0a,                    //  Logical Maximum (10)               515
# 0x75, 0x08,                    //  Report Size (8)                    517
# 0x95, 0x01,                    //  Report Count (1)                   519
# 0xb1, 0x02,                    //  Feature (Data,Var,Abs)             521
# 0x06, 0x00, 0xff,              //  Usage Page (Vendor Defined Page 1) 523
# 0x09, 0xc5,                    //  Usage (Vendor Usage 0xc5)          526
# 0x85, 0x06,                    //  Report ID (6)                      528
# 0x15, 0x00,                    //  Logical Minimum (0)                530
# 0x26, 0xff, 0x00,              //  Logical Maximum (255)              532
# 0x75, 0x08,                    //  Report Size (8)                    535
# 0x96, 0x00, 0x01,              //  Report Count (256)                 537
# 0xb1, 0x02,                    //  Feature (Data,Var,Abs)             540
# 0xc0,                          // End Collection                      542
# 0x05, 0x0d,                    // Usage Page (Digitizers)             543
# 0x09, 0x02,                    // Usage (Pen)                         545
# 0xa1, 0x01,                    // Collection (Application)            547
# 0x85, 0x0d,                    //  Report ID (13)                     549
# 0x09, 0x20,                    //  Usage (Stylus)                     551
# 0xa1, 0x00,                    //  Collection (Physical)              553
# 0x09, 0x42,                    //   Usage (Tip Switch)                555
# 0x09, 0x44,                    //   Usage (Barrel Switch)             557
# 0x09, 0x45,                    //   Usage (Eraser)                    559
# 0x09, 0x3c,                    //   Usage (Invert)                    561
# 0x09, 0x32,                    //   Usage (In Range)                  563
# 0x09, 0x5a,                    //   Usage (Secondary Barrel Switch)   565
# 0x15, 0x00,                    //   Logical Minimum (0)               567
# 0x25, 0x01,                    //   Logical Maximum (1)               569
# 0x75, 0x01,                    //   Report Size (1)                   571
# 0x95, 0x06,                    //   Report Count (6)                  573
# 0x81, 0x02,                    //   Input (Data,Var,Abs)              575
# 0x95, 0x02,                    //   Report Count (2)                  577
# 0x81, 0x03,                    //   Input (Cnst,Var,Abs)              579
# 0x05, 0x01,                    //   Usage Page (Generic Desktop)      581
# 0x09, 0x30,                    //   Usage (X)                         583
# 0x75, 0x10,                    //   Report Size (16)                  585
# 0x95, 0x01,                    //   Report Count (1)                  587
# 0xa4,                          //   Push                              589
# 0x55, 0x0e,                    //   Unit Exponent (-2)                590
# 0x65, 0x11,                    //   Unit (SILinear: cm)               592
# 0x35, 0x00,                    //   Physical Minimum (0)              594
# 0x46, 0x43, 0x0a,              //   Physical Maximum (2627)           596
# 0x26, 0x00, 0x40,              //   Logical Maximum (16384)           599
# 0x81, 0x02,                    //   Input (Data,Var,Abs)              602
# 0x09, 0x31,                    //   Usage (Y)                         604
# 0x35, 0x00,                    //   Physical Minimum (0)              606
# 0x46, 0x6a, 0x06,              //   Physical Maximum (1642)           608
# 0x26, 0x80, 0x25,              //   Logical Maximum (9600)            611
# 0x81, 0x02,                    //   Input (Data,Var,Abs)              614
# 0xb4,                          //   Pop                               616
# 0x05, 0x0d,                    //   Usage Page (Digitizers)           617
# 0x09, 0x30,                    //   Usage (Tip Pressure)              619
# 0x26, 0xff, 0x0f,              //   Logical Maximum (4095)            621
# 0x75, 0x10,                    //   Report Size (16)                  624
# 0x95, 0x01,                    //   Report Count (1)                  626
# 0x81, 0x02,                    //   Input (Data,Var,Abs)              628
# 0x09, 0x3d,                    //   Usage (X Tilt)                    630
# 0x55, 0x0e,                    //   Unit Exponent (-2)                632
# 0x65, 0x14,                    //   Unit (EnglishRotation: deg)       634
# 0x36, 0xd8, 0xdc,              //   Physical Minimum (-9000)          636
# 0x46, 0x28, 0x23,              //   Physical Maximum (9000)           639
# 0x16, 0xd8, 0xdc,              //   Logical Minimum (-9000)           642
# 0x26, 0x28, 0x23,              //   Logical Maximum (9000)            645
# 0x81, 0x02,                    //   Input (Data,Var,Abs)              648
# 0x09, 0x3e,                    //   Usage (Y Tilt)                    650
# 0x81, 0x02,                    //   Input (Data,Var,Abs)              652
# 0x09, 0x3b,                    //   Usage (Battery Strength)          654
# 0x75, 0x08,                    //   Report Size (8)                   656
# 0x95, 0x01,                    //   Report Count (1)                  658
# 0x15, 0x00,                    //   Logical Minimum (0)               660
# 0x25, 0x64,                    //   Logical Maximum (100)             662
# 0x81, 0x02,                    //   Input (Data,Var,Abs)              664
# 0x09, 0x31,                    //   Usage (Barrel Pressure)           666
# 0x75, 0x10,                    //   Report Size (16)                  668
# 0x95, 0x01,                    //   Report Count (1)                  670
# 0x26, 0xff, 0x0f,              //   Logical Maximum (4095)            672
# 0x81, 0x02,                    //   Input (Data,Var,Abs)              675
# 0x09, 0x38,                    //   Usage (Transducer Index)          677
# 0x95, 0x01,                    //   Report Count (1)                  679
# 0x75, 0x08,                    //   Report Size (8)                   681
# 0x15, 0x00,                    //   Logical Minimum (0)               683
# 0x25, 0x02,                    //   Logical Maximum (2)               685
# 0x81, 0x02,                    //   Input (Data,Var,Abs)              687
# 0x05, 0x0d,                    //   Usage Page (Digitizers)           689
# 0x09, 0x5c,                    //   Usage (Preferred Inking Color)    691
# 0x26, 0xff, 0x00,              //   Logical Maximum (255)             693
# 0x75, 0x08,                    //   Report Size (8)                   696
# 0x81, 0x02,                    //   Input (Data,Var,Abs)              698
# 0x09, 0x5c,                    //   Usage (Preferred Inking Color)    700
# 0x27, 0xff, 0xff, 0xff, 0x00,  //   Logical Maximum (16777215)        702
# 0x75, 0x18,                    //   Report Size (24)                  707
# 0x81, 0x02,                    //   Input (Data,Var,Abs)              709
# 0x09, 0x5e,                    //   Usage (Preferred Line Width)      711
# 0x26, 0xff, 0x00,              //   Logical Maximum (255)             713
# 0x75, 0x08,                    //   Report Size (8)                   716
# 0x95, 0x01,                    //   Report Count (1)                  718
# 0x81, 0x02,                    //   Input (Data,Var,Abs)              720
# 0x09, 0x70,                    //   Usage (Preferred Line Style)      722
# 0xa1, 0x02,                    //   Collection (Logical)              724
# 0x15, 0x01,                    //    Logical Minimum (1)              726
# 0x25, 0x06,                    //    Logical Maximum (6)              728
# 0x09, 0x72,                    //    Usage (Ink)                      730
# 0x09, 0x73,                    //    Usage (Pencil)                   732
# 0x09, 0x74,                    //    Usage (Highlighter)              734
# 0x09, 0x75,                    //    Usage (Chisel Marker)            736
# 0x09, 0x76,                    //    Usage (Brush)                    738
# 0x09, 0x77,                    //    Usage (No preference)            740
# 0x81, 0x20,                    //    Input (Data,Arr,Abs,NoPref)      742
# 0xc0,                          //   End Collection                    744
# 0x09, 0x5b,                    //   Usage (Transducer Serial Number)  745
# 0x25, 0xff,                    //   Logical Maximum (255)             747
# 0x75, 0x40,                    //   Report Size (64)                  749
# 0x81, 0x02,                    //   Input (Data,Var,Abs)              751
# 0x09, 0x6e,                    //   Usage (Vendor Usage 0x6e)         753
# 0x17, 0x00, 0x00, 0x00, 0x80,  //   Logical Minimum (-2147483648)     755
# 0x27, 0xff, 0xff, 0xff, 0x7f,  //   Logical Maximum (2147483647)      760
# 0x95, 0x01,                    //   Report Count (1)                  765
# 0x75, 0x20,                    //   Report Size (32)                  767
# 0x81, 0x02,                    //   Input (Data,Var,Abs)              769
# 0x55, 0x0c,                    //   Unit Exponent (-4)                771
# 0x66, 0x01, 0x10,              //   Unit (SILinear: s)                773
# 0x35, 0x00,                    //   Physical Minimum (0)              776
# 0x47, 0xff, 0xff, 0x00, 0x00,  //   Physical Maximum (65535)          778
# 0x15, 0x00,                    //   Logical Minimum (0)               783
# 0x27, 0xff, 0xff, 0x00, 0x00,  //   Logical Maximum (65535)           785
# 0x75, 0x10,                    //   Report Size (16)                  790
# 0x95, 0x01,                    //   Report Count (1)                  792
# 0x05, 0x0d,                    //   Usage Page (Digitizers)           794
# 0x09, 0x56,                    //   Usage (Scan Time)                 796
# 0x81, 0x02,                    //   Input (Data,Var,Abs)              798
# 0x05, 0x0d,                    //   Usage Page (Digitizers)           800
# 0x85, 0x20,                    //   Report ID (32)                    802
# 0x09, 0x38,                    //   Usage (Transducer Index)          804
# 0x75, 0x08,                    //   Report Size (8)                   806
# 0x95, 0x01,                    //   Report Count (1)                  808
# 0x15, 0x00,                    //   Logical Minimum (0)               810
# 0x25, 0x02,                    //   Logical Maximum (2)               812
# 0x81, 0x02,                    //   Input (Data,Var,Abs)              814
# 0x15, 0x01,                    //   Logical Minimum (1)               816
# 0x25, 0x04,                    //   Logical Maximum (4)               818
# 0x09, 0x81,                    //   Usage (Digitizer Error)           820
# 0xa1, 0x02,                    //   Collection (Logical)              822
# 0x09, 0x82,                    //    Usage (Err Normal Status)        824
# 0x09, 0x83,                    //    Usage (Err Transducers Exceeded) 826
# 0x09, 0x84,                    //    Usage (Err Full Trans Features Unavail) 828
# 0x09, 0x85,                    //    Usage (Err Charge Low)           830
# 0x81, 0x20,                    //    Input (Data,Arr,Abs,NoPref)      832
# 0xc0,                          //   End Collection                    834
# 0x09, 0x5c,                    //   Usage (Preferred Inking Color)    835
# 0x85, 0x21,                    //   Report ID (33)                    837
# 0xa1, 0x02,                    //   Collection (Logical)              839
# 0x15, 0x00,                    //    Logical Minimum (0)              841
# 0x25, 0x02,                    //    Logical Maximum (2)              843
# 0x75, 0x08,                    //    Report Size (8)                  845
# 0x95, 0x01,                    //    Report Count (1)                 847
# 0x09, 0x38,                    //    Usage (Transducer Index)         849
# 0xb1, 0x02,                    //    Feature (Data,Var,Abs)           851
# 0x09, 0x5c,                    //    Usage (Preferred Inking Color)   853
# 0x26, 0xff, 0x00,              //    Logical Maximum (255)            855
# 0xb1, 0x02,                    //    Feature (Data,Var,Abs)           858
# 0x09, 0x5d,                    //    Usage (Preferred Color is Locked) 860
# 0x75, 0x01,                    //    Report Size (1)                  862
# 0x95, 0x01,                    //    Report Count (1)                 864
# 0x25, 0x01,                    //    Logical Maximum (1)              866
# 0xb1, 0x02,                    //    Feature (Data,Var,Abs)           868
# 0x95, 0x07,                    //    Report Count (7)                 870
# 0xb1, 0x03,                    //    Feature (Cnst,Var,Abs)           872
# 0xc0,                          //   End Collection                    874
# 0x09, 0x5c,                    //   Usage (Preferred Inking Color)    875
# 0x85, 0x22,                    //   Report ID (34)                    877
# 0xa1, 0x02,                    //   Collection (Logical)              879
# 0x15, 0x00,                    //    Logical Minimum (0)              881
# 0x25, 0x02,                    //    Logical Maximum (2)              883
# 0x75, 0x08,                    //    Report Size (8)                  885
# 0x95, 0x01,                    //    Report Count (1)                 887
# 0x09, 0x38,                    //    Usage (Transducer Index)         889
# 0xb1, 0x02,                    //    Feature (Data,Var,Abs)           891
# 0x75, 0x18,                    //    Report Size (24)                 893
# 0x09, 0x5c,                    //    Usage (Preferred Inking Color)   895
# 0x27, 0xff, 0xff, 0xff, 0x00,  //    Logical Maximum (16777215)       897
# 0xb1, 0x02,                    //    Feature (Data,Var,Abs)           902
# 0x09, 0x6f,                    //    Usage (Vendor Usage 0x6f)        904
# 0x75, 0x01,                    //    Report Size (1)                  906
# 0x95, 0x01,                    //    Report Count (1)                 908
# 0x25, 0x01,                    //    Logical Maximum (1)              910
# 0xb1, 0x02,                    //    Feature (Data,Var,Abs)           912
# 0x09, 0x5d,                    //    Usage (Preferred Color is Locked) 914
# 0x75, 0x01,                    //    Report Size (1)                  916
# 0x95, 0x01,                    //    Report Count (1)                 918
# 0x25, 0x01,                    //    Logical Maximum (1)              920
# 0xb1, 0x02,                    //    Feature (Data,Var,Abs)           922
# 0x95, 0x06,                    //    Report Count (6)                 924
# 0xb1, 0x03,                    //    Feature (Cnst,Var,Abs)           926
# 0xc0,                          //   End Collection                    928
# 0x09, 0x5e,                    //   Usage (Preferred Line Width)      929
# 0x85, 0x23,                    //   Report ID (35)                    931
# 0xa1, 0x02,                    //   Collection (Logical)              933
# 0x09, 0x38,                    //    Usage (Transducer Index)         935
# 0x15, 0x00,                    //    Logical Minimum (0)              937
# 0x25, 0x02,                    //    Logical Maximum (2)              939
# 0x75, 0x08,                    //    Report Size (8)                  941
# 0x95, 0x01,                    //    Report Count (1)                 943
# 0xb1, 0x02,                    //    Feature (Data,Var,Abs)           945
# 0x09, 0x5e,                    //    Usage (Preferred Line Width)     947
# 0x26, 0xff, 0x00,              //    Logical Maximum (255)            949
# 0xb1, 0x02,                    //    Feature (Data,Var,Abs)           952
# 0x09, 0x5f,                    //    Usage (Preferred Line Width is Locked) 954
# 0x75, 0x01,                    //    Report Size (1)                  956
# 0x25, 0x01,                    //    Logical Maximum (1)              958
# 0xb1, 0x02,                    //    Feature (Data,Var,Abs)           960
# 0x75, 0x07,                    //    Report Size (7)                  962
# 0xb1, 0x03,                    //    Feature (Cnst,Var,Abs)           964
# 0xc0,                          //   End Collection                    966
# 0x09, 0x70,                    //   Usage (Preferred Line Style)      967
# 0x85, 0x24,                    //   Report ID (36)                    969
# 0xa1, 0x02,                    //   Collection (Logical)              971
# 0x75, 0x08,                    //    Report Size (8)                  973
# 0x95, 0x01,                    //    Report Count (1)                 975
# 0x15, 0x00,                    //    Logical Minimum (0)              977
# 0x25, 0x02,                    //    Logical Maximum (2)              979
# 0x09, 0x38,                    //    Usage (Transducer Index)         981
# 0xb1, 0x02,                    //    Feature (Data,Var,Abs)           983
# 0x09, 0x70,                    //    Usage (Preferred Line Style)     985
# 0xa1, 0x02,                    //    Collection (Logical)             987
# 0x25, 0x06,                    //     Logical Maximum (6)             989
# 0x09, 0x72,                    //     Usage (Ink)                     991
# 0x09, 0x73,                    //     Usage (Pencil)                  993
# 0x09, 0x74,                    //     Usage (Highlighter)             995
# 0x09, 0x75,                    //     Usage (Chisel Marker)           997
# 0x09, 0x76,                    //     Usage (Brush)                   999
# 0x09, 0x77,                    //     Usage (No preference)           1001
# 0xb1, 0x20,                    //     Feature (Data,Arr,Abs,NoPref)   1003
# 0xc0,                          //    End Collection                   1005
# 0x09, 0x71,                    //    Usage (Preferred Line Style is Locked) 1006
# 0x75, 0x01,                    //    Report Size (1)                  1008
# 0x25, 0x01,                    //    Logical Maximum (1)              1010
# 0xb1, 0x02,                    //    Feature (Data,Var,Abs)           1012
# 0x75, 0x07,                    //    Report Size (7)                  1014
# 0xb1, 0x03,                    //    Feature (Cnst,Var,Abs)           1016
# 0xc0,                          //   End Collection                    1018
# 0x09, 0x80,                    //   Usage (Digitizer Diagnostic)      1019
# 0x85, 0x25,                    //   Report ID (37)                    1021
# 0x15, 0x00,                    //   Logical Minimum (0)               1023
# 0x25, 0xff,                    //   Logical Maximum (255)             1025
# 0x75, 0x40,                    //   Report Size (64)                  1027
# 0x95, 0x01,                    //   Report Count (1)                  1029
# 0xb1, 0x02,                    //   Feature (Data,Var,Abs)            1031
# 0x09, 0x44,                    //   Usage (Barrel Switch)             1033
# 0x85, 0x26,                    //   Report ID (38)                    1035
# 0xa1, 0x02,                    //   Collection (Logical)              1037
# 0x09, 0x38,                    //    Usage (Transducer Index)         1039
# 0x75, 0x08,                    //    Report Size (8)                  1041
# 0x95, 0x01,                    //    Report Count (1)                 1043
# 0x15, 0x00,                    //    Logical Minimum (0)              1045
# 0x25, 0x02,                    //    Logical Maximum (2)              1047
# 0xb1, 0x02,                    //    Feature (Data,Var,Abs)           1049
# 0x15, 0x01,                    //    Logical Minimum (1)              1051
# 0x25, 0x03,                    //    Logical Maximum (3)              1053
# 0x09, 0x44,                    //    Usage (Barrel Switch)            1055
# 0xa1, 0x02,                    //    Collection (Logical)             1057
# 0x09, 0xa4,                    //     Usage (Switch Unimplemented)    1059
# 0x09, 0x44,                    //     Usage (Barrel Switch)           1061
# 0x09, 0x5a,                    //     Usage (Secondary Barrel Switch) 1063
# 0x09, 0x45,                    //     Usage (Eraser)                  1065
# 0x09, 0xa3,                    //     Usage (Switch Disabled)         1067
# 0xb1, 0x20,                    //     Feature (Data,Arr,Abs,NoPref)   1069
# 0xc0,                          //    End Collection                   1071
# 0x09, 0x5a,                    //    Usage (Secondary Barrel Switch)  1072
# 0xa1, 0x02,                    //    Collection (Logical)             1074
# 0x09, 0xa4,                    //     Usage (Switch Unimplemented)    1076
# 0x09, 0x44,                    //     Usage (Barrel Switch)           1078
# 0x09, 0x5a,                    //     Usage (Secondary Barrel Switch) 1080
# 0x09, 0x45,                    //     Usage (Eraser)                  1082
# 0x09, 0xa3,                    //     Usage (Switch Disabled)         1084
# 0xb1, 0x20,                    //     Feature (Data,Arr,Abs,NoPref)   1086
# 0xc0,                          //    End Collection                   1088
# 0x09, 0x45,                    //    Usage (Eraser)                   1089
# 0xa1, 0x02,                    //    Collection (Logical)             1091
# 0x09, 0xa4,                    //     Usage (Switch Unimplemented)    1093
# 0x09, 0x44,                    //     Usage (Barrel Switch)           1095
# 0x09, 0x5a,                    //     Usage (Secondary Barrel Switch) 1097
# 0x09, 0x45,                    //     Usage (Eraser)                  1099
# 0x09, 0xa3,                    //     Usage (Switch Disabled)         1101
# 0xb1, 0x20,                    //     Feature (Data,Arr,Abs,NoPref)   1103
# 0xc0,                          //    End Collection                   1105
# 0xc0,                          //   End Collection                    1106
# 0x05, 0x0d,                    //   Usage Page (Digitizers)           1107
# 0x85, 0x27,                    //   Report ID (39)                    1109
# 0x75, 0x08,                    //   Report Size (8)                   1111
# 0x95, 0x01,                    //   Report Count (1)                  1113
# 0x09, 0x90,                    //   Usage (Transducer Software Info.) 1115
# 0xa1, 0x02,                    //   Collection (Logical)              1117
# 0x09, 0x38,                    //    Usage (Transducer Index)         1119
# 0x15, 0x00,                    //    Logical Minimum (0)              1121
# 0x25, 0x02,                    //    Logical Maximum (2)              1123
# 0xb1, 0x02,                    //    Feature (Data,Var,Abs)           1125
# 0x09, 0x5b,                    //    Usage (Transducer Serial Number) 1127
# 0x17, 0x00, 0x00, 0x00, 0x80,  //    Logical Minimum (-2147483648)    1129
# 0x27, 0xff, 0xff, 0xff, 0x7f,  //    Logical Maximum (2147483647)     1134
# 0x75, 0x40,                    //    Report Size (64)                 1139
# 0xb1, 0x02,                    //    Feature (Data,Var,Abs)           1141
# 0x09, 0x6e,                    //    Usage (Vendor Usage 0x6e)        1143
# 0x75, 0x20,                    //    Report Size (32)                 1145
# 0xb1, 0x02,                    //    Feature (Data,Var,Abs)           1147
# 0x09, 0x91,                    //    Usage (Transducer Vendor ID)     1149
# 0x75, 0x10,                    //    Report Size (16)                 1151
# 0x26, 0xff, 0x0f,              //    Logical Maximum (4095)           1153
# 0xb1, 0x02,                    //    Feature (Data,Var,Abs)           1156
# 0x09, 0x92,                    //    Usage (Transducer Product ID)    1158
# 0x75, 0x40,                    //    Report Size (64)                 1160
# 0x25, 0xff,                    //    Logical Maximum (255)            1162
# 0xb1, 0x02,                    //    Feature (Data,Var,Abs)           1164
# 0x05, 0x06,                    //    Usage Page (Generic Device Controls) 1166
# 0x09, 0x2a,                    //    Usage (Software Version)         1168
# 0x75, 0x08,                    //    Report Size (8)                  1170
# 0x26, 0xff, 0x00,              //    Logical Maximum (255)            1172
# 0xa1, 0x02,                    //    Collection (Logical)             1175
# 0x09, 0x2d,                    //     Usage (Major)                   1177
# 0xb1, 0x02,                    //     Feature (Data,Var,Abs)          1179
# 0x09, 0x2e,                    //     Usage (Minor)                   1181
# 0xb1, 0x02,                    //     Feature (Data,Var,Abs)          1183
# 0xc0,                          //    End Collection                   1185
# 0xc0,                          //   End Collection                    1186
# 0x05, 0x06,                    //   Usage Page (Generic Device Controls) 1187
# 0x85, 0x28,                    //   Report ID (40)                    1189
# 0x09, 0x2b,                    //   Usage (Protocol Version)          1191
# 0xa1, 0x02,                    //   Collection (Logical)              1193
# 0x05, 0x0d,                    //    Usage Page (Digitizers)          1195
# 0x15, 0x00,                    //    Logical Minimum (0)              1197
# 0x25, 0x02,                    //    Logical Maximum (2)              1199
# 0x09, 0x38,                    //    Usage (Transducer Index)         1201
# 0xb1, 0x02,                    //    Feature (Data,Var,Abs)           1203
# 0x05, 0x06,                    //    Usage Page (Generic Device Controls) 1205
# 0x09, 0x2b,                    //    Usage (Protocol Version)         1207
# 0xa1, 0x02,                    //    Collection (Logical)             1209
# 0x09, 0x2d,                    //     Usage (Major)                   1211
# 0x26, 0xff, 0x00,              //     Logical Maximum (255)           1213
# 0xb1, 0x02,                    //     Feature (Data,Var,Abs)          1216
# 0x09, 0x2e,                    //     Usage (Minor)                   1218
# 0xb1, 0x02,                    //     Feature (Data,Var,Abs)          1220
# 0xc0,                          //    End Collection                   1222
# 0xc0,                          //   End Collection                    1223
# 0x06, 0x00, 0xff,              //   Usage Page (Vendor Defined Page 1) 1224
# 0x85, 0x29,                    //   Report ID (41)                    1227
# 0x09, 0x01,                    //   Usage (Vendor Usage 1)            1229
# 0xa1, 0x02,                    //   Collection (Logical)              1231
# 0x05, 0x0d,                    //    Usage Page (Digitizers)          1233
# 0x09, 0x38,                    //    Usage (Transducer Index)         1235
# 0x75, 0x08,                    //    Report Size (8)                  1237
# 0x95, 0x01,                    //    Report Count (1)                 1239
# 0x15, 0x00,                    //    Logical Minimum (0)              1241
# 0x25, 0x02,                    //    Logical Maximum (2)              1243
# 0xb1, 0x02,                    //    Feature (Data,Var,Abs)           1245
# 0x06, 0x00, 0xff,              //    Usage Page (Vendor Defined Page 1) 1247
# 0x09, 0x01,                    //    Usage (Vendor Usage 1)           1250
# 0x75, 0x10,                    //    Report Size (16)                 1252
# 0x27, 0xff, 0xff, 0x00, 0x00,  //    Logical Maximum (65535)          1254
# 0xb1, 0x02,                    //    Feature (Data,Var,Abs)           1259
# 0xc0,                          //   End Collection                    1261
# 0x05, 0x0d,                    //   Usage Page (Digitizers)           1262
# 0x85, 0x2a,                    //   Report ID (42)                    1264
# 0x09, 0x38,                    //   Usage (Transducer Index)          1266
# 0x75, 0x08,                    //   Report Size (8)                   1268
# 0x95, 0x01,                    //   Report Count (1)                  1270
# 0x15, 0x00,                    //   Logical Minimum (0)               1272
# 0x25, 0x02,                    //   Logical Maximum (2)               1274
# 0xb1, 0x02,                    //   Feature (Data,Var,Abs)            1276
# 0xc0,                          //  End Collection                     1278
# 0xc0,                          // End Collection                      1279
# 0x06, 0x00, 0xff,              // Usage Page (Vendor Defined Page 1)  1280
# 0x09, 0x01,                    // Usage (Vendor Usage 1)              1283
# 0xa1, 0x01,                    // Collection (Application)            1285
# 0x09, 0x01,                    //  Usage (Vendor Usage 1)             1287
# 0x85, 0x03,                    //  Report ID (3)                      1289
# 0x15, 0x00,                    //  Logical Minimum (0)                1291
# 0x26, 0xff, 0x00,              //  Logical Maximum (255)              1293
# 0x75, 0x08,                    //  Report Size (8)                    1296
# 0x95, 0x3f,                    //  Report Count (63)                  1298
# 0x81, 0x02,                    //  Input (Data,Var,Abs)               1300
# 0x06, 0x00, 0xff,              //  Usage Page (Vendor Defined Page 1) 1302
# 0x09, 0x01,                    //  Usage (Vendor Usage 1)             1305
# 0x15, 0x00,                    //  Logical Minimum (0)                1307
# 0x26, 0xff, 0x00,              //  Logical Maximum (255)              1309
# 0x75, 0x08,                    //  Report Size (8)                    1312
# 0x95, 0x3f,                    //  Report Count (63)                  1314
# 0x91, 0x02,                    //  Output (Data,Var,Abs)              1316
# 0x85, 0x0c,                    //  Report ID (12)                     1318
# 0x09, 0x01,                    //  Usage (Vendor Usage 1)             1320
# 0x81, 0x02,                    //  Input (Data,Var,Abs)               1322
# 0x85, 0x07,                    //  Report ID (7)                      1324
# 0x96, 0x06, 0x01,              //  Report Count (262)                 1326
# 0x09, 0x01,                    //  Usage (Vendor Usage 1)             1329
# 0xb1, 0x02,                    //  Feature (Data,Var,Abs)             1331
# 0x85, 0x08,                    //  Report ID (8)                      1333
# 0x96, 0x06, 0x04,              //  Report Count (1030)                1335
# 0x09, 0x01,                    //  Usage (Vendor Usage 1)             1338
# 0xb1, 0x02,                    //  Feature (Data,Var,Abs)             1340
# 0x85, 0x09,                    //  Report ID (9)                      1342
# 0x96, 0x06, 0x08,              //  Report Count (2054)                1344
# 0x09, 0x01,                    //  Usage (Vendor Usage 1)             1347
# 0xb1, 0x02,                    //  Feature (Data,Var,Abs)             1349
# 0xc0,                          // End Collection                      1351
# 0x05, 0x01,                    // Usage Page (Generic Desktop)        1352
# 0x09, 0x02,                    // Usage (Mouse)                       1354
# 0xa1, 0x01,                    // Collection (Application)            1356
# 0x85, 0x05,                    //  Report ID (5)                      1358
# 0x09, 0x01,                    //  Usage (Pointer)                    1360
# 0xa1, 0x00,                    //  Collection (Physical)              1362
# 0x05, 0x09,                    //   Usage Page (Button)               1364
# 0x19, 0x01,                    //   Usage Minimum (1)                 1366
# 0x29, 0x05,                    //   Usage Maximum (5)                 1368
# 0x15, 0x00,                    //   Logical Minimum (0)               1370
# 0x25, 0x01,                    //   Logical Maximum (1)               1372
# 0x95, 0x05,                    //   Report Count (5)                  1374
# 0x75, 0x01,                    //   Report Size (1)                   1376
# 0x81, 0x02,                    //   Input (Data,Var,Abs)              1378
# 0x95, 0x01,                    //   Report Count (1)                  1380
# 0x75, 0x03,                    //   Report Size (3)                   1382
# 0x81, 0x01,                    //   Input (Cnst,Arr,Abs)              1384
# 0x05, 0x01,                    //   Usage Page (Generic Desktop)      1386
# 0x75, 0x10,                    //   Report Size (16)                  1388
# 0x95, 0x01,                    //   Report Count (1)                  1390
# 0x55, 0x0e,                    //   Unit Exponent (-2)                1392
# 0x65, 0x11,                    //   Unit (SILinear: cm)               1394
# 0x09, 0x30,                    //   Usage (X)                         1396
# 0x26, 0x00, 0x40,              //   Logical Maximum (16384)           1398
# 0x35, 0x00,                    //   Physical Minimum (0)              1401
# 0x46, 0x43, 0x0a,              //   Physical Maximum (2627)           1403
# 0x81, 0x42,                    //   Input (Data,Var,Abs,Null)         1406
# 0x09, 0x31,                    //   Usage (Y)                         1408
# 0x26, 0x80, 0x25,              //   Logical Maximum (9600)            1410
# 0x46, 0x6a, 0x06,              //   Physical Maximum (1642)           1413
# 0x81, 0x42,                    //   Input (Data,Var,Abs,Null)         1416
# 0xc0,                          //  End Collection                     1418
# 0xc0,                          // End Collection                      1419
```

### MPP HID Report Descriptor

```
# 0x05, 0x0d,                    // Usage Page (Digitizers)             0
# 0x09, 0x04,                    // Usage (Touch Screen)                2
# 0xa1, 0x01,                    // Collection (Application)            4
# 0x85, 0x04,                    //  Report ID (4)                      6
# 0x05, 0x0d,                    //  Usage Page (Digitizers)            8
# 0x09, 0x22,                    //  Usage (Finger)                     10
# 0xa1, 0x02,                    //  Collection (Logical)               12
# 0x05, 0x0d,                    //   Usage Page (Digitizers)           14
# 0x95, 0x01,                    //   Report Count (1)                  16
# 0x75, 0x06,                    //   Report Size (6)                   18
# 0x09, 0x51,                    //   Usage (Contact Id)                20
# 0x15, 0x00,                    //   Logical Minimum (0)               22
# 0x25, 0x3f,                    //   Logical Maximum (63)              24
# 0x81, 0x02,                    //   Input (Data,Var,Abs)              26
# 0x09, 0x42,                    //   Usage (Tip Switch)                28
# 0x25, 0x01,                    //   Logical Maximum (1)               30
# 0x75, 0x01,                    //   Report Size (1)                   32
# 0x95, 0x01,                    //   Report Count (1)                  34
# 0x81, 0x02,                    //   Input (Data,Var,Abs)              36
# 0x09, 0x47,                    //   Usage (Confidence)                38
# 0x75, 0x01,                    //   Report Size (1)                   40
# 0x81, 0x02,                    //   Input (Data,Var,Abs)              42
# 0x05, 0x01,                    //   Usage Page (Generic Desktop)      44
# 0x75, 0x10,                    //   Report Size (16)                  46
# 0x55, 0x0e,                    //   Unit Exponent (-2)                48
# 0x65, 0x11,                    //   Unit (SILinear: cm)               50
# 0x09, 0x30,                    //   Usage (X)                         52
# 0x26, 0x00, 0x40,              //   Logical Maximum (16384)           54
# 0x35, 0x00,                    //   Physical Minimum (0)              57
# 0x46, 0x43, 0x0a,              //   Physical Maximum (2627)           59
# 0x81, 0x42,                    //   Input (Data,Var,Abs,Null)         62
# 0x09, 0x31,                    //   Usage (Y)                         64
# 0x26, 0x80, 0x25,              //   Logical Maximum (9600)            66
# 0x46, 0x6a, 0x06,              //   Physical Maximum (1642)           69
# 0x81, 0x42,                    //   Input (Data,Var,Abs,Null)         72
# 0x95, 0x01,                    //   Report Count (1)                  74
# 0x75, 0x08,                    //   Report Size (8)                   76
# 0x81, 0x03,                    //   Input (Cnst,Var,Abs)              78
# 0x05, 0x0d,                    //   Usage Page (Digitizers)           80
# 0x26, 0xff, 0x7f,              //   Logical Maximum (32767)           82
# 0x09, 0x48,                    //   Usage (Width)                     85
# 0x75, 0x10,                    //   Report Size (16)                  87
# 0x95, 0x01,                    //   Report Count (1)                  89
# 0x81, 0x02,                    //   Input (Data,Var,Abs)              91
# 0x09, 0x49,                    //   Usage (Height)                    93
# 0x81, 0x02,                    //   Input (Data,Var,Abs)              95
# 0xc0,                          //  End Collection                     97
# 0x05, 0x0d,                    //  Usage Page (Digitizers)            98
# 0x09, 0x22,                    //  Usage (Finger)                     100
# 0xa1, 0x02,                    //  Collection (Logical)               102
# 0x05, 0x0d,                    //   Usage Page (Digitizers)           104
# 0x95, 0x01,                    //   Report Count (1)                  106
# 0x75, 0x06,                    //   Report Size (6)                   108
# 0x09, 0x51,                    //   Usage (Contact Id)                110
# 0x15, 0x00,                    //   Logical Minimum (0)               112
# 0x25, 0x3f,                    //   Logical Maximum (63)              114
# 0x81, 0x02,                    //   Input (Data,Var,Abs)              116
# 0x09, 0x42,                    //   Usage (Tip Switch)                118
# 0x25, 0x01,                    //   Logical Maximum (1)               120
# 0x75, 0x01,                    //   Report Size (1)                   122
# 0x95, 0x01,                    //   Report Count (1)                  124
# 0x81, 0x02,                    //   Input (Data,Var,Abs)              126
# 0x09, 0x47,                    //   Usage (Confidence)                128
# 0x75, 0x01,                    //   Report Size (1)                   130
# 0x81, 0x02,                    //   Input (Data,Var,Abs)              132
# 0x05, 0x01,                    //   Usage Page (Generic Desktop)      134
# 0x75, 0x10,                    //   Report Size (16)                  136
# 0x55, 0x0e,                    //   Unit Exponent (-2)                138
# 0x65, 0x11,                    //   Unit (SILinear: cm)               140
# 0x09, 0x30,                    //   Usage (X)                         142
# 0x26, 0x00, 0x40,              //   Logical Maximum (16384)           144
# 0x35, 0x00,                    //   Physical Minimum (0)              147
# 0x46, 0x43, 0x0a,              //   Physical Maximum (2627)           149
# 0x81, 0x42,                    //   Input (Data,Var,Abs,Null)         152
# 0x09, 0x31,                    //   Usage (Y)                         154
# 0x26, 0x80, 0x25,              //   Logical Maximum (9600)            156
# 0x46, 0x6a, 0x06,              //   Physical Maximum (1642)           159
# 0x81, 0x42,                    //   Input (Data,Var,Abs,Null)         162
# 0x95, 0x01,                    //   Report Count (1)                  164
# 0x75, 0x08,                    //   Report Size (8)                   166
# 0x81, 0x03,                    //   Input (Cnst,Var,Abs)              168
# 0x05, 0x0d,                    //   Usage Page (Digitizers)           170
# 0x26, 0xff, 0x7f,              //   Logical Maximum (32767)           172
# 0x09, 0x48,                    //   Usage (Width)                     175
# 0x75, 0x10,                    //   Report Size (16)                  177
# 0x95, 0x01,                    //   Report Count (1)                  179
# 0x81, 0x02,                    //   Input (Data,Var,Abs)              181
# 0x09, 0x49,                    //   Usage (Height)                    183
# 0x81, 0x02,                    //   Input (Data,Var,Abs)              185
# 0xc0,                          //  End Collection                     187
# 0x05, 0x0d,                    //  Usage Page (Digitizers)            188
# 0x09, 0x22,                    //  Usage (Finger)                     190
# 0xa1, 0x02,                    //  Collection (Logical)               192
# 0x05, 0x0d,                    //   Usage Page (Digitizers)           194
# 0x95, 0x01,                    //   Report Count (1)                  196
# 0x75, 0x06,                    //   Report Size (6)                   198
# 0x09, 0x51,                    //   Usage (Contact Id)                200
# 0x15, 0x00,                    //   Logical Minimum (0)               202
# 0x25, 0x3f,                    //   Logical Maximum (63)              204
# 0x81, 0x02,                    //   Input (Data,Var,Abs)              206
# 0x09, 0x42,                    //   Usage (Tip Switch)                208
# 0x25, 0x01,                    //   Logical Maximum (1)               210
# 0x75, 0x01,                    //   Report Size (1)                   212
# 0x95, 0x01,                    //   Report Count (1)                  214
# 0x81, 0x02,                    //   Input (Data,Var,Abs)              216
# 0x09, 0x47,                    //   Usage (Confidence)                218
# 0x75, 0x01,                    //   Report Size (1)                   220
# 0x81, 0x02,                    //   Input (Data,Var,Abs)              222
# 0x05, 0x01,                    //   Usage Page (Generic Desktop)      224
# 0x75, 0x10,                    //   Report Size (16)                  226
# 0x55, 0x0e,                    //   Unit Exponent (-2)                228
# 0x65, 0x11,                    //   Unit (SILinear: cm)               230
# 0x09, 0x30,                    //   Usage (X)                         232
# 0x26, 0x00, 0x40,              //   Logical Maximum (16384)           234
# 0x35, 0x00,                    //   Physical Minimum (0)              237
# 0x46, 0x43, 0x0a,              //   Physical Maximum (2627)           239
# 0x81, 0x42,                    //   Input (Data,Var,Abs,Null)         242
# 0x09, 0x31,                    //   Usage (Y)                         244
# 0x26, 0x80, 0x25,              //   Logical Maximum (9600)            246
# 0x46, 0x6a, 0x06,              //   Physical Maximum (1642)           249
# 0x81, 0x42,                    //   Input (Data,Var,Abs,Null)         252
# 0x95, 0x01,                    //   Report Count (1)                  254
# 0x75, 0x08,                    //   Report Size (8)                   256
# 0x81, 0x03,                    //   Input (Cnst,Var,Abs)              258
# 0x05, 0x0d,                    //   Usage Page (Digitizers)           260
# 0x26, 0xff, 0x7f,              //   Logical Maximum (32767)           262
# 0x09, 0x48,                    //   Usage (Width)                     265
# 0x75, 0x10,                    //   Report Size (16)                  267
# 0x95, 0x01,                    //   Report Count (1)                  269
# 0x81, 0x02,                    //   Input (Data,Var,Abs)              271
# 0x09, 0x49,                    //   Usage (Height)                    273
# 0x81, 0x02,                    //   Input (Data,Var,Abs)              275
# 0xc0,                          //  End Collection                     277
# 0x05, 0x0d,                    //  Usage Page (Digitizers)            278
# 0x09, 0x22,                    //  Usage (Finger)                     280
# 0xa1, 0x02,                    //  Collection (Logical)               282
# 0x05, 0x0d,                    //   Usage Page (Digitizers)           284
# 0x95, 0x01,                    //   Report Count (1)                  286
# 0x75, 0x06,                    //   Report Size (6)                   288
# 0x09, 0x51,                    //   Usage (Contact Id)                290
# 0x15, 0x00,                    //   Logical Minimum (0)               292
# 0x25, 0x3f,                    //   Logical Maximum (63)              294
# 0x81, 0x02,                    //   Input (Data,Var,Abs)              296
# 0x09, 0x42,                    //   Usage (Tip Switch)                298
# 0x25, 0x01,                    //   Logical Maximum (1)               300
# 0x75, 0x01,                    //   Report Size (1)                   302
# 0x95, 0x01,                    //   Report Count (1)                  304
# 0x81, 0x02,                    //   Input (Data,Var,Abs)              306
# 0x09, 0x47,                    //   Usage (Confidence)                308
# 0x75, 0x01,                    //   Report Size (1)                   310
# 0x81, 0x02,                    //   Input (Data,Var,Abs)              312
# 0x05, 0x01,                    //   Usage Page (Generic Desktop)      314
# 0x75, 0x10,                    //   Report Size (16)                  316
# 0x55, 0x0e,                    //   Unit Exponent (-2)                318
# 0x65, 0x11,                    //   Unit (SILinear: cm)               320
# 0x09, 0x30,                    //   Usage (X)                         322
# 0x26, 0x00, 0x40,              //   Logical Maximum (16384)           324
# 0x35, 0x00,                    //   Physical Minimum (0)              327
# 0x46, 0x43, 0x0a,              //   Physical Maximum (2627)           329
# 0x81, 0x42,                    //   Input (Data,Var,Abs,Null)         332
# 0x09, 0x31,                    //   Usage (Y)                         334
# 0x26, 0x80, 0x25,              //   Logical Maximum (9600)            336
# 0x46, 0x6a, 0x06,              //   Physical Maximum (1642)           339
# 0x81, 0x42,                    //   Input (Data,Var,Abs,Null)         342
# 0x95, 0x01,                    //   Report Count (1)                  344
# 0x75, 0x08,                    //   Report Size (8)                   346
# 0x81, 0x03,                    //   Input (Cnst,Var,Abs)              348
# 0x05, 0x0d,                    //   Usage Page (Digitizers)           350
# 0x26, 0xff, 0x7f,              //   Logical Maximum (32767)           352
# 0x09, 0x48,                    //   Usage (Width)                     355
# 0x75, 0x10,                    //   Report Size (16)                  357
# 0x95, 0x01,                    //   Report Count (1)                  359
# 0x81, 0x02,                    //   Input (Data,Var,Abs)              361
# 0x09, 0x49,                    //   Usage (Height)                    363
# 0x81, 0x02,                    //   Input (Data,Var,Abs)              365
# 0xc0,                          //  End Collection                     367
# 0x05, 0x0d,                    //  Usage Page (Digitizers)            368
# 0x09, 0x22,                    //  Usage (Finger)                     370
# 0xa1, 0x02,                    //  Collection (Logical)               372
# 0x05, 0x0d,                    //   Usage Page (Digitizers)           374
# 0x95, 0x01,                    //   Report Count (1)                  376
# 0x75, 0x06,                    //   Report Size (6)                   378
# 0x09, 0x51,                    //   Usage (Contact Id)                380
# 0x15, 0x00,                    //   Logical Minimum (0)               382
# 0x25, 0x3f,                    //   Logical Maximum (63)              384
# 0x81, 0x02,                    //   Input (Data,Var,Abs)              386
# 0x09, 0x42,                    //   Usage (Tip Switch)                388
# 0x25, 0x01,                    //   Logical Maximum (1)               390
# 0x75, 0x01,                    //   Report Size (1)                   392
# 0x95, 0x01,                    //   Report Count (1)                  394
# 0x81, 0x02,                    //   Input (Data,Var,Abs)              396
# 0x09, 0x47,                    //   Usage (Confidence)                398
# 0x75, 0x01,                    //   Report Size (1)                   400
# 0x81, 0x02,                    //   Input (Data,Var,Abs)              402
# 0x05, 0x01,                    //   Usage Page (Generic Desktop)      404
# 0x75, 0x10,                    //   Report Size (16)                  406
# 0x55, 0x0e,                    //   Unit Exponent (-2)                408
# 0x65, 0x11,                    //   Unit (SILinear: cm)               410
# 0x09, 0x30,                    //   Usage (X)                         412
# 0x26, 0x00, 0x40,              //   Logical Maximum (16384)           414
# 0x35, 0x00,                    //   Physical Minimum (0)              417
# 0x46, 0x43, 0x0a,              //   Physical Maximum (2627)           419
# 0x81, 0x42,                    //   Input (Data,Var,Abs,Null)         422
# 0x09, 0x31,                    //   Usage (Y)                         424
# 0x26, 0x80, 0x25,              //   Logical Maximum (9600)            426
# 0x46, 0x6a, 0x06,              //   Physical Maximum (1642)           429
# 0x81, 0x42,                    //   Input (Data,Var,Abs,Null)         432
# 0x95, 0x01,                    //   Report Count (1)                  434
# 0x75, 0x08,                    //   Report Size (8)                   436
# 0x81, 0x03,                    //   Input (Cnst,Var,Abs)              438
# 0x05, 0x0d,                    //   Usage Page (Digitizers)           440
# 0x26, 0xff, 0x7f,              //   Logical Maximum (32767)           442
# 0x09, 0x48,                    //   Usage (Width)                     445
# 0x75, 0x10,                    //   Report Size (16)                  447
# 0x95, 0x01,                    //   Report Count (1)                  449
# 0x81, 0x02,                    //   Input (Data,Var,Abs)              451
# 0x09, 0x49,                    //   Usage (Height)                    453
# 0x81, 0x02,                    //   Input (Data,Var,Abs)              455
# 0xc0,                          //  End Collection                     457
# 0x55, 0x0c,                    //  Unit Exponent (-4)                 458
# 0x66, 0x01, 0x10,              //  Unit (SILinear: s)                 460
# 0x35, 0x00,                    //  Physical Minimum (0)               463
# 0x47, 0xff, 0xff, 0x00, 0x00,  //  Physical Maximum (65535)           465
# 0x15, 0x00,                    //  Logical Minimum (0)                470
# 0x27, 0xff, 0xff, 0x00, 0x00,  //  Logical Maximum (65535)            472
# 0x75, 0x10,                    //  Report Size (16)                   477
# 0x95, 0x01,                    //  Report Count (1)                   479
# 0x05, 0x0d,                    //  Usage Page (Digitizers)            481
# 0x09, 0x56,                    //  Usage (Scan Time)                  483
# 0x81, 0x02,                    //  Input (Data,Var,Abs)               485
# 0x95, 0x08,                    //  Report Count (8)                   487
# 0x75, 0x08,                    //  Report Size (8)                    489
# 0x81, 0x03,                    //  Input (Cnst,Var,Abs)               491
# 0x05, 0x0d,                    //  Usage Page (Digitizers)            493
# 0x09, 0x54,                    //  Usage (Contact Count)              495
# 0x25, 0x7f,                    //  Logical Maximum (127)              497
# 0x95, 0x01,                    //  Report Count (1)                   499
# 0x75, 0x08,                    //  Report Size (8)                    501
# 0x81, 0x02,                    //  Input (Data,Var,Abs)               503
# 0x95, 0x02,                    //  Report Count (2)                   505
# 0x75, 0x08,                    //  Report Size (8)                    507
# 0x81, 0x03,                    //  Input (Cnst,Var,Abs)               509
# 0x85, 0x02,                    //  Report ID (2)                      511
# 0x09, 0x55,                    //  Usage (Contact Max)                513
# 0x25, 0x0a,                    //  Logical Maximum (10)               515
# 0x75, 0x08,                    //  Report Size (8)                    517
# 0x95, 0x01,                    //  Report Count (1)                   519
# 0xb1, 0x02,                    //  Feature (Data,Var,Abs)             521
# 0x06, 0x00, 0xff,              //  Usage Page (Vendor Defined Page 1) 523
# 0x09, 0xc5,                    //  Usage (Vendor Usage 0xc5)          526
# 0x85, 0x06,                    //  Report ID (6)                      528
# 0x15, 0x00,                    //  Logical Minimum (0)                530
# 0x26, 0xff, 0x00,              //  Logical Maximum (255)              532
# 0x75, 0x08,                    //  Report Size (8)                    535
# 0x96, 0x00, 0x01,              //  Report Count (256)                 537
# 0xb1, 0x02,                    //  Feature (Data,Var,Abs)             540
# 0xc0,                          // End Collection                      542
# 0x05, 0x0d,                    // Usage Page (Digitizers)             543
# 0x09, 0x02,                    // Usage (Pen)                         545
# 0xa1, 0x01,                    // Collection (Application)            547
# 0x85, 0x0d,                    //  Report ID (13)                     549
# 0x09, 0x20,                    //  Usage (Stylus)                     551
# 0xa1, 0x00,                    //  Collection (Physical)              553
# 0x09, 0x42,                    //   Usage (Tip Switch)                555
# 0x09, 0x44,                    //   Usage (Barrel Switch)             557
# 0x09, 0x45,                    //   Usage (Eraser)                    559
# 0x09, 0x3c,                    //   Usage (Invert)                    561
# 0x09, 0x32,                    //   Usage (In Range)                  563
# 0x09, 0x5a,                    //   Usage (Secondary Barrel Switch)   565
# 0x15, 0x00,                    //   Logical Minimum (0)               567
# 0x25, 0x01,                    //   Logical Maximum (1)               569
# 0x75, 0x01,                    //   Report Size (1)                   571
# 0x95, 0x06,                    //   Report Count (6)                  573
# 0x81, 0x02,                    //   Input (Data,Var,Abs)              575
# 0x95, 0x02,                    //   Report Count (2)                  577
# 0x81, 0x03,                    //   Input (Cnst,Var,Abs)              579
# 0x05, 0x01,                    //   Usage Page (Generic Desktop)      581
# 0x09, 0x30,                    //   Usage (X)                         583
# 0x75, 0x10,                    //   Report Size (16)                  585
# 0x95, 0x01,                    //   Report Count (1)                  587
# 0xa4,                          //   Push                              589
# 0x55, 0x0e,                    //   Unit Exponent (-2)                590
# 0x65, 0x11,                    //   Unit (SILinear: cm)               592
# 0x35, 0x00,                    //   Physical Minimum (0)              594
# 0x46, 0x43, 0x0a,              //   Physical Maximum (2627)           596
# 0x26, 0x00, 0x40,              //   Logical Maximum (16384)           599
# 0x81, 0x02,                    //   Input (Data,Var,Abs)              602
# 0x09, 0x31,                    //   Usage (Y)                         604
# 0x35, 0x00,                    //   Physical Minimum (0)              606
# 0x46, 0x6a, 0x06,              //   Physical Maximum (1642)           608
# 0x26, 0x80, 0x25,              //   Logical Maximum (9600)            611
# 0x81, 0x02,                    //   Input (Data,Var,Abs)              614
# 0xb4,                          //   Pop                               616
# 0x05, 0x0d,                    //   Usage Page (Digitizers)           617
# 0x09, 0x30,                    //   Usage (Tip Pressure)              619
# 0x26, 0xff, 0x0f,              //   Logical Maximum (4095)            621
# 0x75, 0x10,                    //   Report Size (16)                  624
# 0x95, 0x01,                    //   Report Count (1)                  626
# 0x81, 0x02,                    //   Input (Data,Var,Abs)              628
# 0x09, 0x3d,                    //   Usage (X Tilt)                    630
# 0x55, 0x0e,                    //   Unit Exponent (-2)                632
# 0x65, 0x14,                    //   Unit (EnglishRotation: deg)       634
# 0x36, 0xd8, 0xdc,              //   Physical Minimum (-9000)          636
# 0x46, 0x28, 0x23,              //   Physical Maximum (9000)           639
# 0x16, 0xd8, 0xdc,              //   Logical Minimum (-9000)           642
# 0x26, 0x28, 0x23,              //   Logical Maximum (9000)            645
# 0x81, 0x02,                    //   Input (Data,Var,Abs)              648
# 0x09, 0x3e,                    //   Usage (Y Tilt)                    650
# 0x81, 0x02,                    //   Input (Data,Var,Abs)              652
# 0x09, 0x3b,                    //   Usage (Battery Strength)          654
# 0x75, 0x08,                    //   Report Size (8)                   656
# 0x95, 0x01,                    //   Report Count (1)                  658
# 0x15, 0x00,                    //   Logical Minimum (0)               660
# 0x25, 0x64,                    //   Logical Maximum (100)             662
# 0x81, 0x02,                    //   Input (Data,Var,Abs)              664
# 0x55, 0x0c,                    //   Unit Exponent (-4)                666
# 0x66, 0x01, 0x10,              //   Unit (SILinear: s)                668
# 0x35, 0x00,                    //   Physical Minimum (0)              671
# 0x47, 0xff, 0xff, 0x00, 0x00,  //   Physical Maximum (65535)          673
# 0x15, 0x00,                    //   Logical Minimum (0)               678
# 0x27, 0xff, 0xff, 0x00, 0x00,  //   Logical Maximum (65535)           680
# 0x75, 0x10,                    //   Report Size (16)                  685
# 0x95, 0x01,                    //   Report Count (1)                  687
# 0x05, 0x0d,                    //   Usage Page (Digitizers)           689
# 0x09, 0x56,                    //   Usage (Scan Time)                 691
# 0x81, 0x02,                    //   Input (Data,Var,Abs)              693
# 0xc0,                          //  End Collection                     695
# 0xc0,                          // End Collection                      696
# 0x06, 0x00, 0xff,              // Usage Page (Vendor Defined Page 1)  697
# 0x09, 0x01,                    // Usage (Vendor Usage 1)              700
# 0xa1, 0x01,                    // Collection (Application)            702
# 0x09, 0x01,                    //  Usage (Vendor Usage 1)             704
# 0x85, 0x03,                    //  Report ID (3)                      706
# 0x15, 0x00,                    //  Logical Minimum (0)                708
# 0x26, 0xff, 0x00,              //  Logical Maximum (255)              710
# 0x75, 0x08,                    //  Report Size (8)                    713
# 0x95, 0x3f,                    //  Report Count (63)                  715
# 0x81, 0x02,                    //  Input (Data,Var,Abs)               717
# 0x06, 0x00, 0xff,              //  Usage Page (Vendor Defined Page 1) 719
# 0x09, 0x01,                    //  Usage (Vendor Usage 1)             722
# 0x15, 0x00,                    //  Logical Minimum (0)                724
# 0x26, 0xff, 0x00,              //  Logical Maximum (255)              726
# 0x75, 0x08,                    //  Report Size (8)                    729
# 0x95, 0x3f,                    //  Report Count (63)                  731
# 0x91, 0x02,                    //  Output (Data,Var,Abs)              733
# 0x85, 0x0c,                    //  Report ID (12)                     735
# 0x09, 0x01,                    //  Usage (Vendor Usage 1)             737
# 0x81, 0x02,                    //  Input (Data,Var,Abs)               739
# 0x85, 0x07,                    //  Report ID (7)                      741
# 0x96, 0x06, 0x01,              //  Report Count (262)                 743
# 0x09, 0x01,                    //  Usage (Vendor Usage 1)             746
# 0xb1, 0x02,                    //  Feature (Data,Var,Abs)             748
# 0x85, 0x08,                    //  Report ID (8)                      750
# 0x96, 0x06, 0x04,              //  Report Count (1030)                752
# 0x09, 0x01,                    //  Usage (Vendor Usage 1)             755
# 0xb1, 0x02,                    //  Feature (Data,Var,Abs)             757
# 0x85, 0x09,                    //  Report ID (9)                      759
# 0x96, 0x06, 0x08,              //  Report Count (2054)                761
# 0x09, 0x01,                    //  Usage (Vendor Usage 1)             764
# 0xb1, 0x02,                    //  Feature (Data,Var,Abs)             766
# 0xc0,                          // End Collection                      768
# 0x05, 0x01,                    // Usage Page (Generic Desktop)        769
# 0x09, 0x02,                    // Usage (Mouse)                       771
# 0xa1, 0x01,                    // Collection (Application)            773
# 0x85, 0x05,                    //  Report ID (5)                      775
# 0x09, 0x01,                    //  Usage (Pointer)                    777
# 0xa1, 0x00,                    //  Collection (Physical)              779
# 0x05, 0x09,                    //   Usage Page (Button)               781
# 0x19, 0x01,                    //   Usage Minimum (1)                 783
# 0x29, 0x05,                    //   Usage Maximum (5)                 785
# 0x15, 0x00,                    //   Logical Minimum (0)               787
# 0x25, 0x01,                    //   Logical Maximum (1)               789
# 0x95, 0x05,                    //   Report Count (5)                  791
# 0x75, 0x01,                    //   Report Size (1)                   793
# 0x81, 0x02,                    //   Input (Data,Var,Abs)              795
# 0x95, 0x01,                    //   Report Count (1)                  797
# 0x75, 0x03,                    //   Report Size (3)                   799
# 0x81, 0x01,                    //   Input (Cnst,Arr,Abs)              801
# 0x05, 0x01,                    //   Usage Page (Generic Desktop)      803
# 0x75, 0x10,                    //   Report Size (16)                  805
# 0x95, 0x01,                    //   Report Count (1)                  807
# 0x55, 0x0e,                    //   Unit Exponent (-2)                809
# 0x65, 0x11,                    //   Unit (SILinear: cm)               811
# 0x09, 0x30,                    //   Usage (X)                         813
# 0x26, 0x00, 0x40,              //   Logical Maximum (16384)           815
# 0x35, 0x00,                    //   Physical Minimum (0)              818
# 0x46, 0x43, 0x0a,              //   Physical Maximum (2627)           820
# 0x81, 0x42,                    //   Input (Data,Var,Abs,Null)         823
# 0x09, 0x31,                    //   Usage (Y)                         825
# 0x26, 0x80, 0x25,              //   Logical Maximum (9600)            827
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

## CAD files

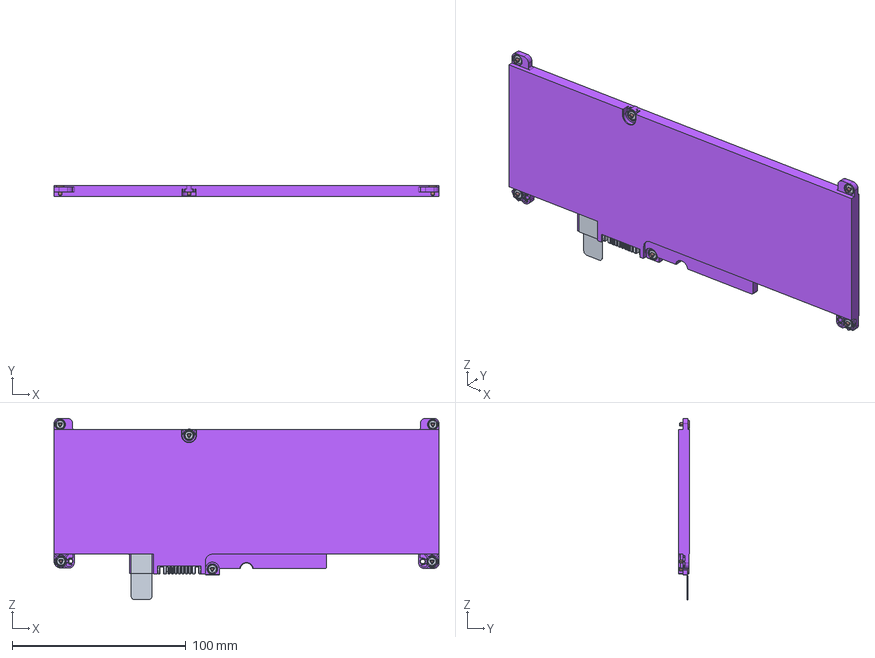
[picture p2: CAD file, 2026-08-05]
Battery/Framework_Laptop_12_50_Battery.stp
221.8 x 6.20 x 104.5 mm
LFR20_BATTERY_CONN
LFR20_BATTERY_BOX_50W_6_2
LFR20_SCREW_M2X4_8 x 6
LFR20_M2_T05_O_RING x 6
LFR20_BATT_PULL_TAPE

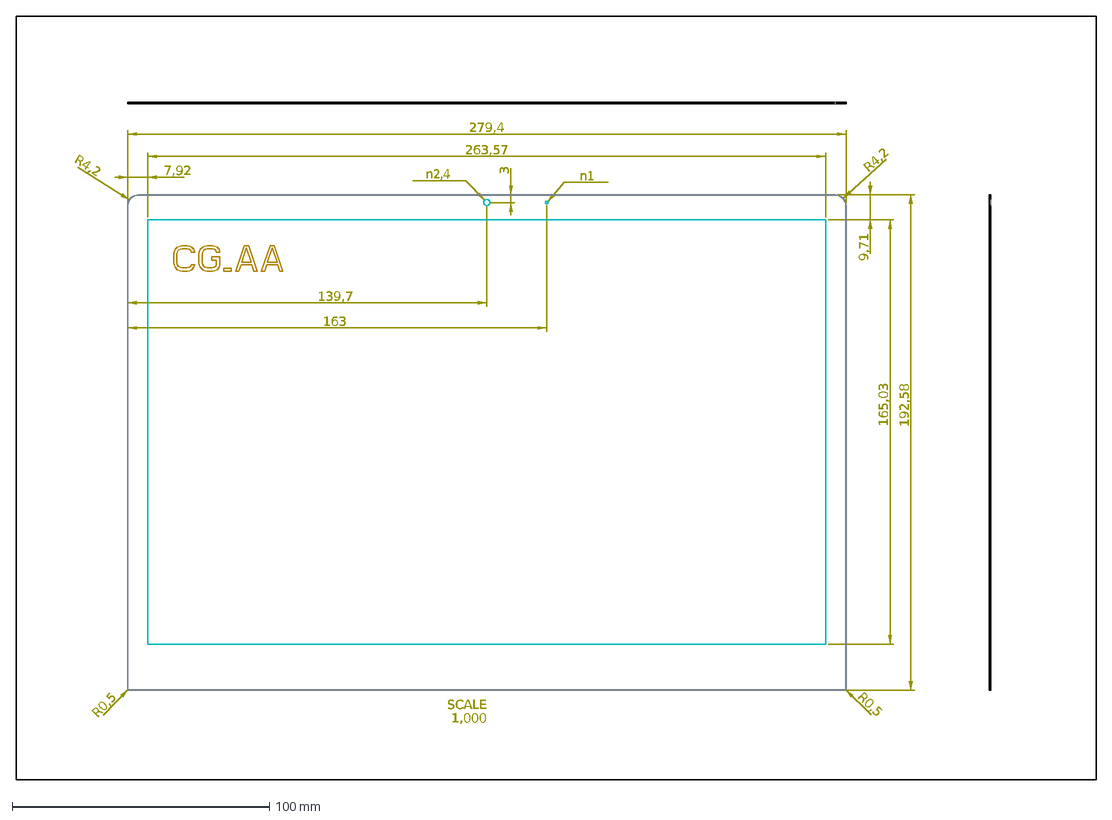
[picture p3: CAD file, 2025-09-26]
Display/framework_laptop_12_glass.dxf
279,4
7,92
263,57
192,58
9,71
165,03
R4,2
3
139,7
163
R0,5
SCALE 1,000

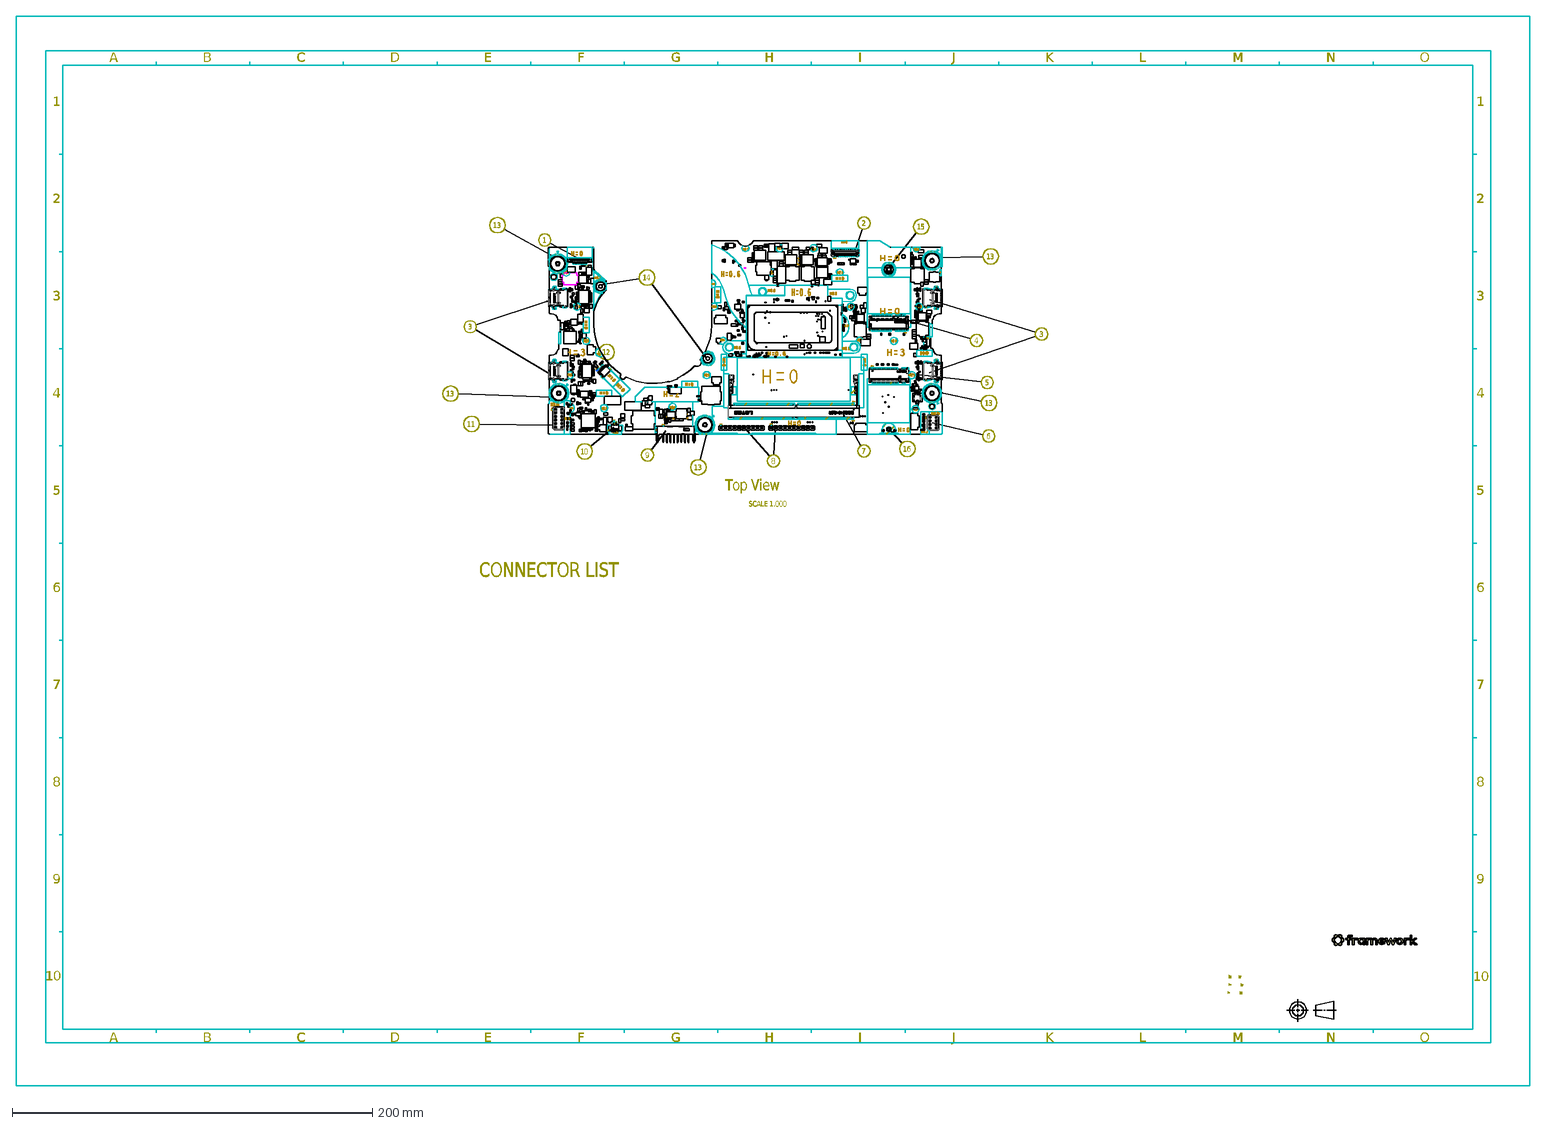
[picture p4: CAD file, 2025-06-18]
Mainboard/2D/Framework_Laptop_12_MB_Generic_P1.dxf
A
10
B
C
9
8
D
E
F
G
6
7
5
4
3
2
1
H
I
J
K
L
M
N
O
Top View
CONNECTOR LIST
SCALE 1.000
13
14
15
11
12
16

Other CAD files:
Mainboard/2D/Framework_Laptop_12_MB_Generic_P5.dxf
Mainboard/2D/Framework_Laptop_12_MB_Generic_P2.dxf
Mainboard/2D/Framework_Laptop_12_MB_Generic_P4.dxf
Mainboard/2D/Framework_Laptop_12_MB_Generic_P6.dxf
Mainboard/2D/Framework_Laptop_12_MB_Generic_P3.dxf

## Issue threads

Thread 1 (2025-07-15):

Pinout mismatch for Mainboard and Input Cover

SBCV-apegram, 2025-07-15:
See [Input Cover](https://github.com/FrameworkComputer/Framework-Laptop-12/tree/main/InputCover#touchpad-pcb-to-mainboard) with 22 pins and [Mainboard](https://github.com/FrameworkComputer/Framework-Laptop-12/tree/main/Mainboard#input-cover-interface) with 20 pins. I believe the first two pins are duplicated on the Input Cover page.

jayasafunctionofe, 2025-08-22:
the 22 pins for "[InputCover#Touchpad-pcb-to-mainboard](https://github.com/FrameworkComputer/Framework-Laptop-12/tree/main/InputCover#touchpad-pcb-to-mainboard)" is for the flex connector, not the pogo pins. The touchpad flex is actually 22 pins.

jayasafunctionofe, 2025-08-22:
(disclaimer, i don't work for framework)

I see what you're saying. We'll have to wait and see if the framework team adds a note about this.

FWIW, when i'm reverse engineering hardware i find it helpful to create a pin to pin mapping table, especially when going between differently numbered interfaces like this.

| Pogo Pin | Signal     | Notes               | Touchpad Pin |
|----------|------------|---------------------| ------------ |
| 1        | 5VS_TP     |                     | 1            |
| 2        | 5VS_TP     |                     | 1            |
| 3        | KBL_P      |                     | 2            |
| 4        | KBL_P      |                     | 2            |
| 5        | 3VS_TP     |                     | 3            |
| 6        | TP_I2C_CLK | Touchpad I2C        | 4            |
| 7        | TP_I2C_SDA | Touchpad I2C        | 5            |
| 8        | TP_INT#    |                     | 6            |
| 9        | BOARD_ID   |                     | 7            |
| 10       | KB_I2C_SCL | Keyboard I2C        | 8            |
| 11       | KB_I2C_SDA | Keyboard I2C        | 9            |
| 12       | KB_INT     | Keyboard I2C        | 10           |
| 13       | KSI_03_IN  | Shorted to pin 2    | 1            |
| 14       | KSI_03_OUT | Shorted to pin 1    | 2            |
| 15       | KSI_02_IN  | Shorted to pin 4    | 3            |
| 16       | KSI_02_OUT | Shorted to pin 3    | 4            |
| 17       | KSI_00_IN  | Shorted to pin 6    | 5            |
| 18       | KSI_00_OUT | Shorted to pin 5    | 6            |
| 19       | GND        |                     | 7            |
| 20       | GND        |                     | 8            |
| 21       | GND        |                     | 9            |
| 22       | GND        |                     | 10           |

i don't have a FW12 in hand to test, but based on the photos online, the existing tables, and prior experience working with flex interfaces,  pins 1+2 and 3+4 are 'duplicated' because they're not really signals, they're power. the traces on the flex for these two "pins" look to be wider, likely to prevent them from burning out with 5v being pushed across the traces.

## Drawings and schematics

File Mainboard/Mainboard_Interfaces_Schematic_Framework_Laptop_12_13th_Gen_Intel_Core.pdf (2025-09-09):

# Block Diagram

## SODIMM A

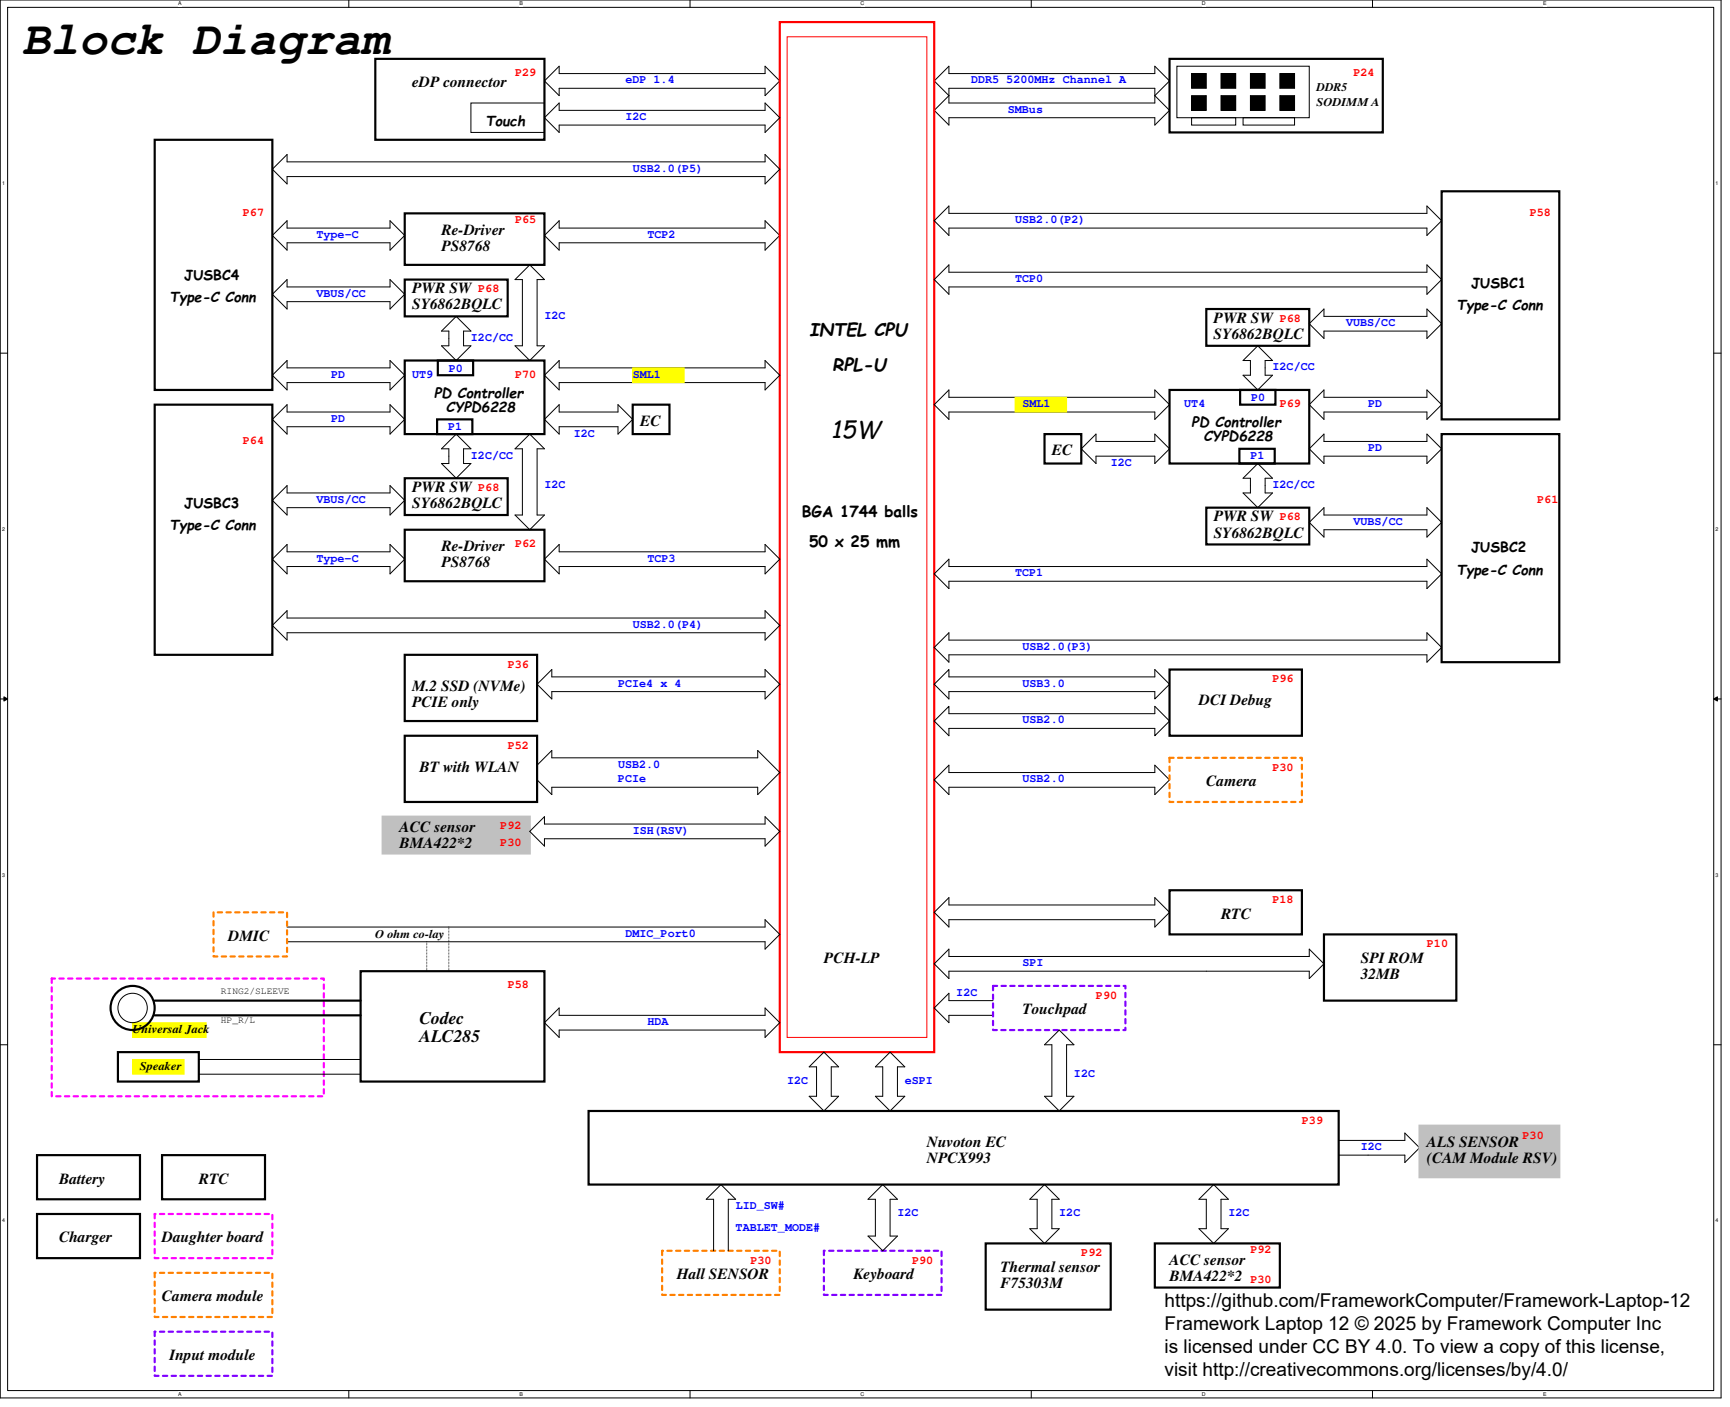
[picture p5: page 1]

ACC sensor
BMA422*2
https://github.com/FrameworkComputer/Framework-Laptop-12
Framework Laptop 12 © 2025 by Framework Computer Inc
is licensed under CC BY 4.0. To view a copy of this license,
visit http://creativecommons.org/licenses/by/4.0/

## 5V_3V_EN

## 5V_3V_EN

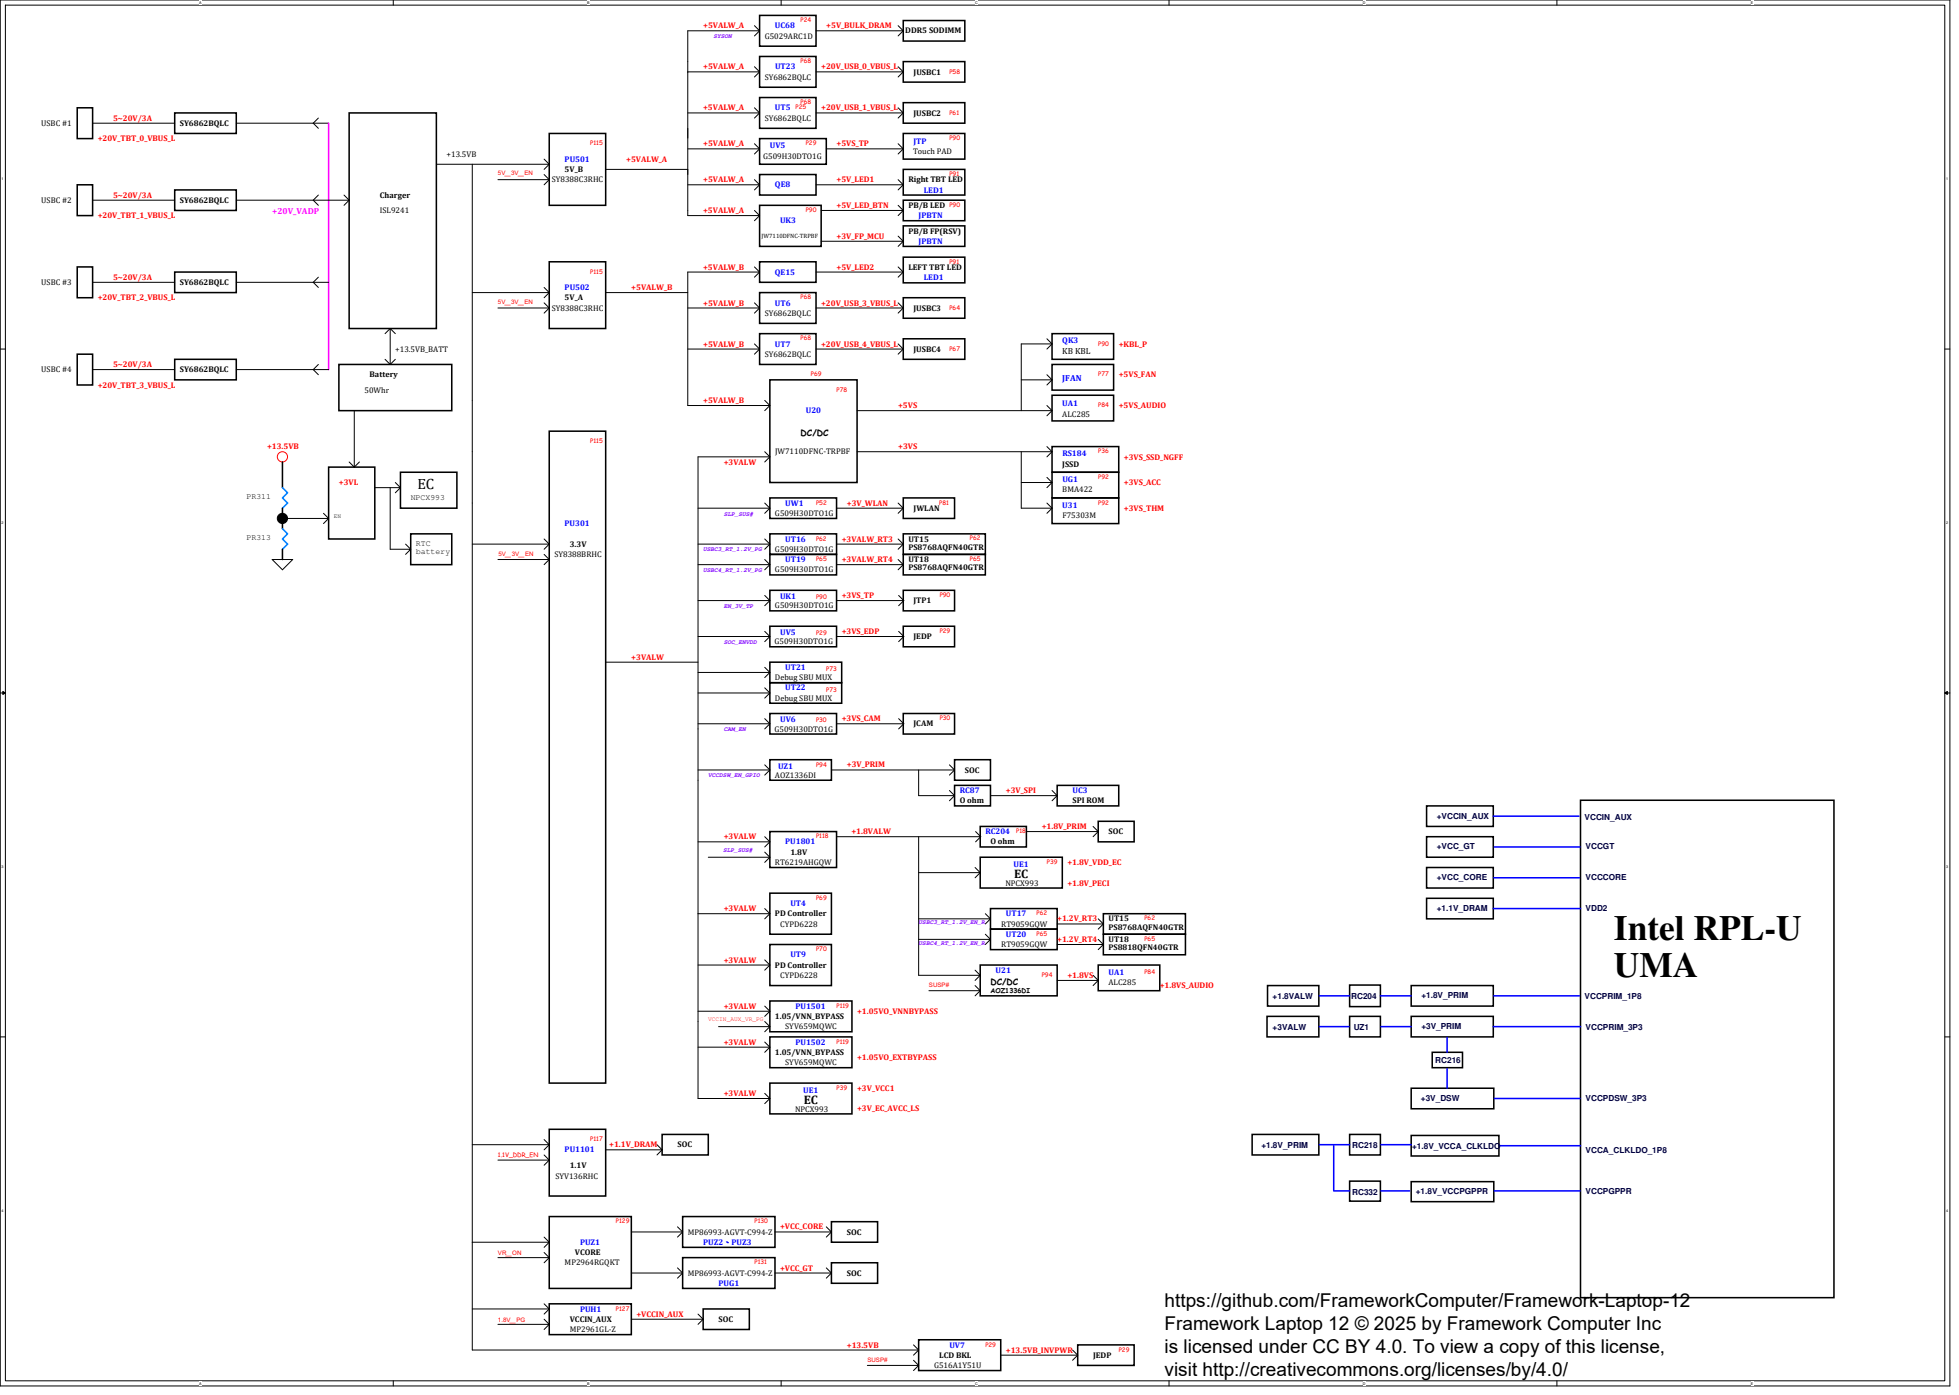
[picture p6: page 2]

eDP Conn.

# eDP

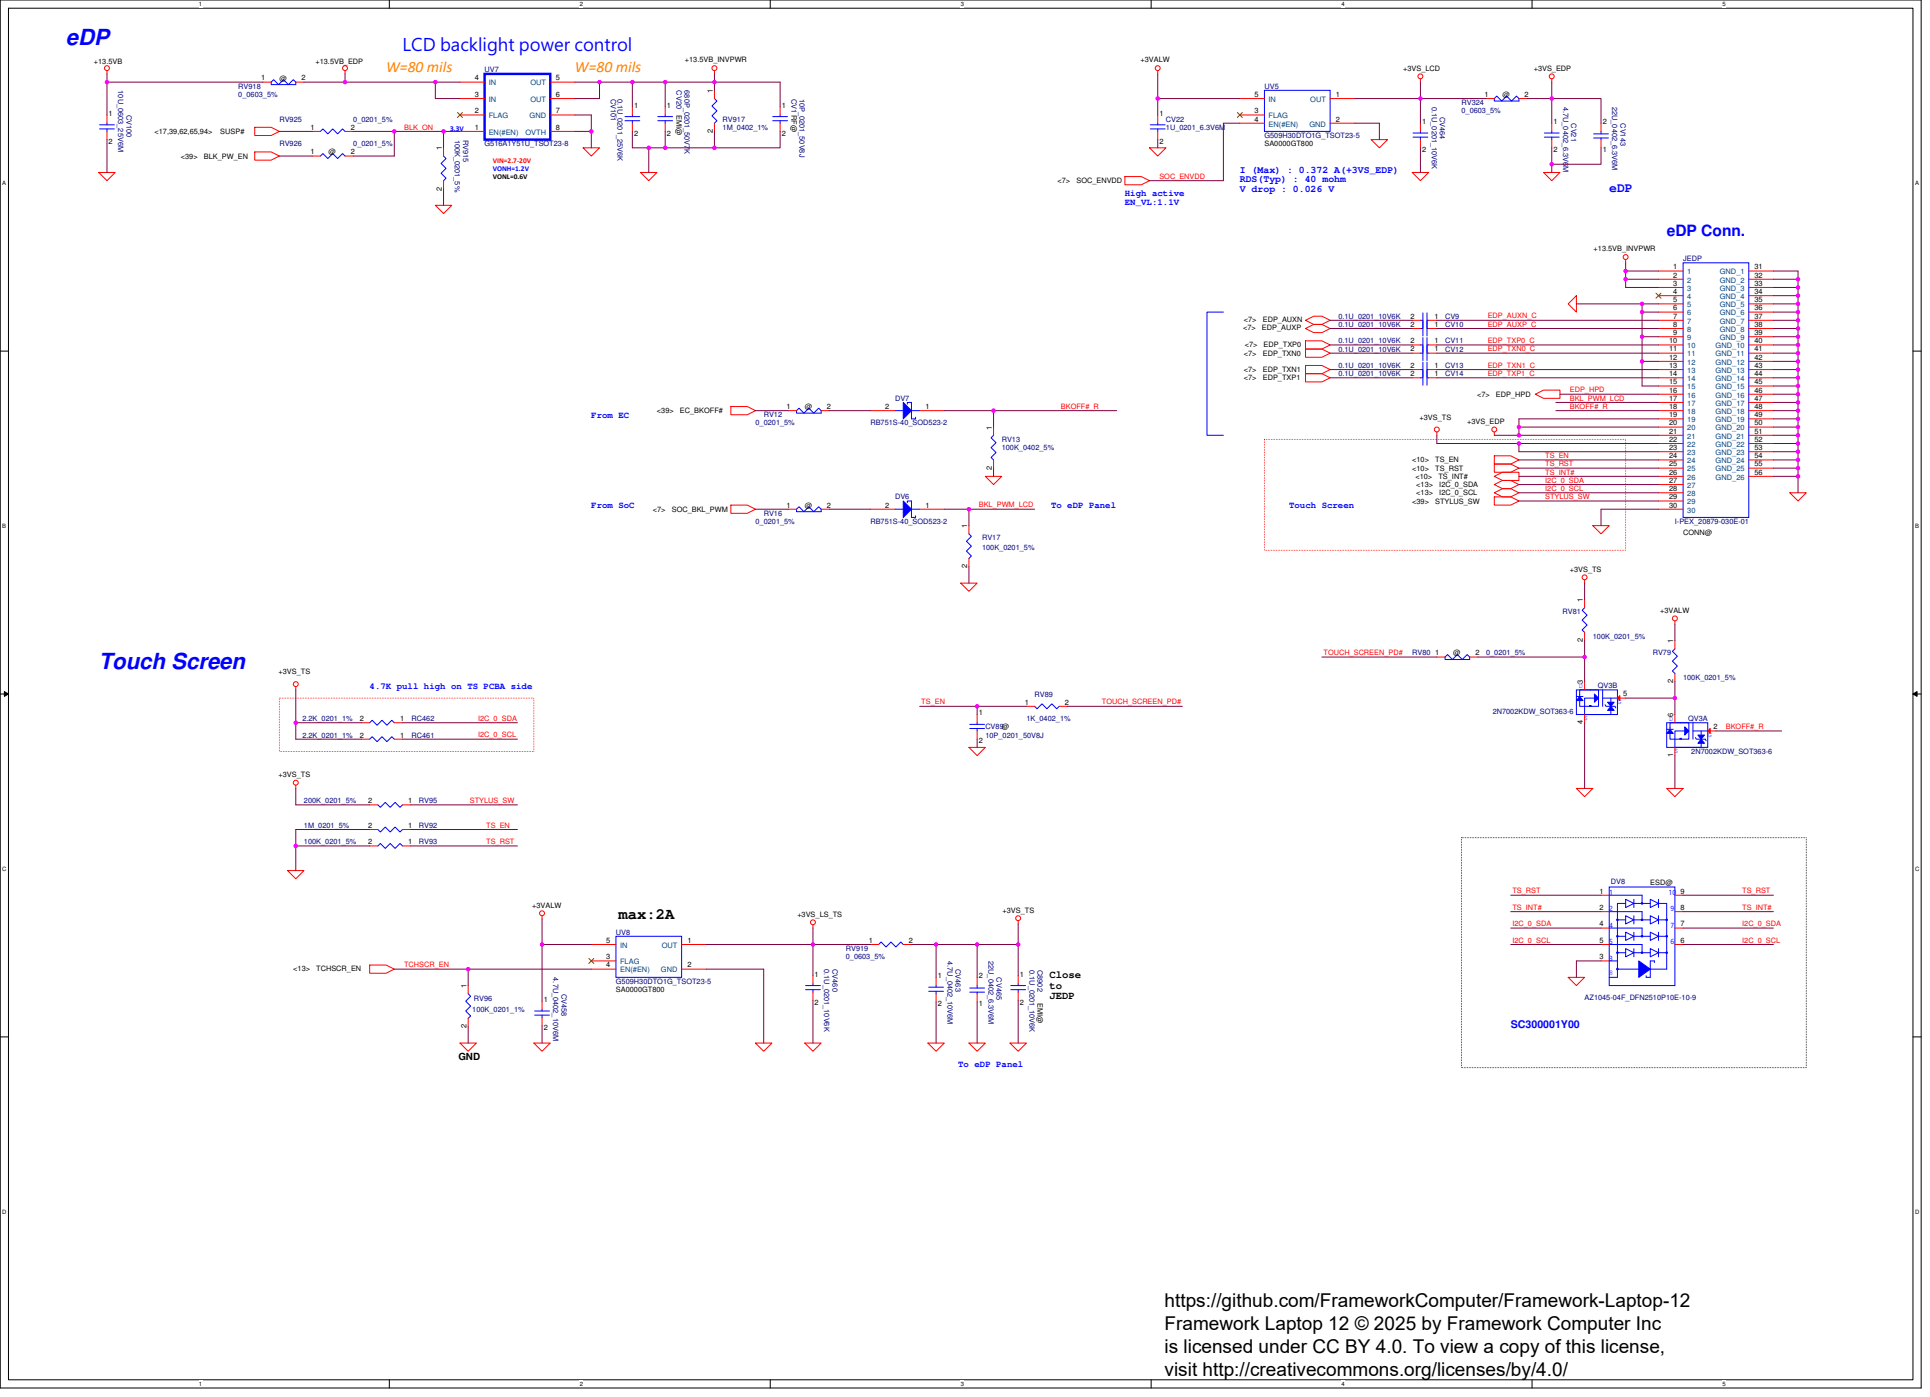
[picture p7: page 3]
From SoC; To eDP Panel; From EC; Touch Screen; VIN=2.7-20V VONH=1.2V VONL=0.6V; W=80 mils; eDP; max:2A; Close to JEDP; <7> SOC_BKL_PWM; <7> SOC_ENVDD; <17,39,62,65,94> SUSP#; <39> EC_BKOFF#; <13> TCHSCR_EN; <7> EDP_AUXN <7> EDP_AUXP; <7> EDP_TXP0 <7> EDP_TXN0; <7> EDP_TXN1 <7> EDP_TXP1; <7> EDP_HPD; <13> I2C_0_SDA <13> I2C_0_SCL; <10> TS_RST <10> TS_INT#; <39> BLK_PW_EN; <39> STYLUS_SW; +13.5VB_INVPWR; +3VALW; +3VS_LCD; +3VS_EDP +13.5VB_EDP; +3VS_EDP; GND; RB751S-40_SOD523-2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

LCD backlight power control

I (Max) : 0.372 A(+3VS_EDP)
RDS(Typ) : 40 mohm

V drop : 0.026 V High active

4.7K pull high on TS PCBA side

To eDP Panel

# DMIC / CAM

## I (Max) : 0.372 A(+3VS_EDP)

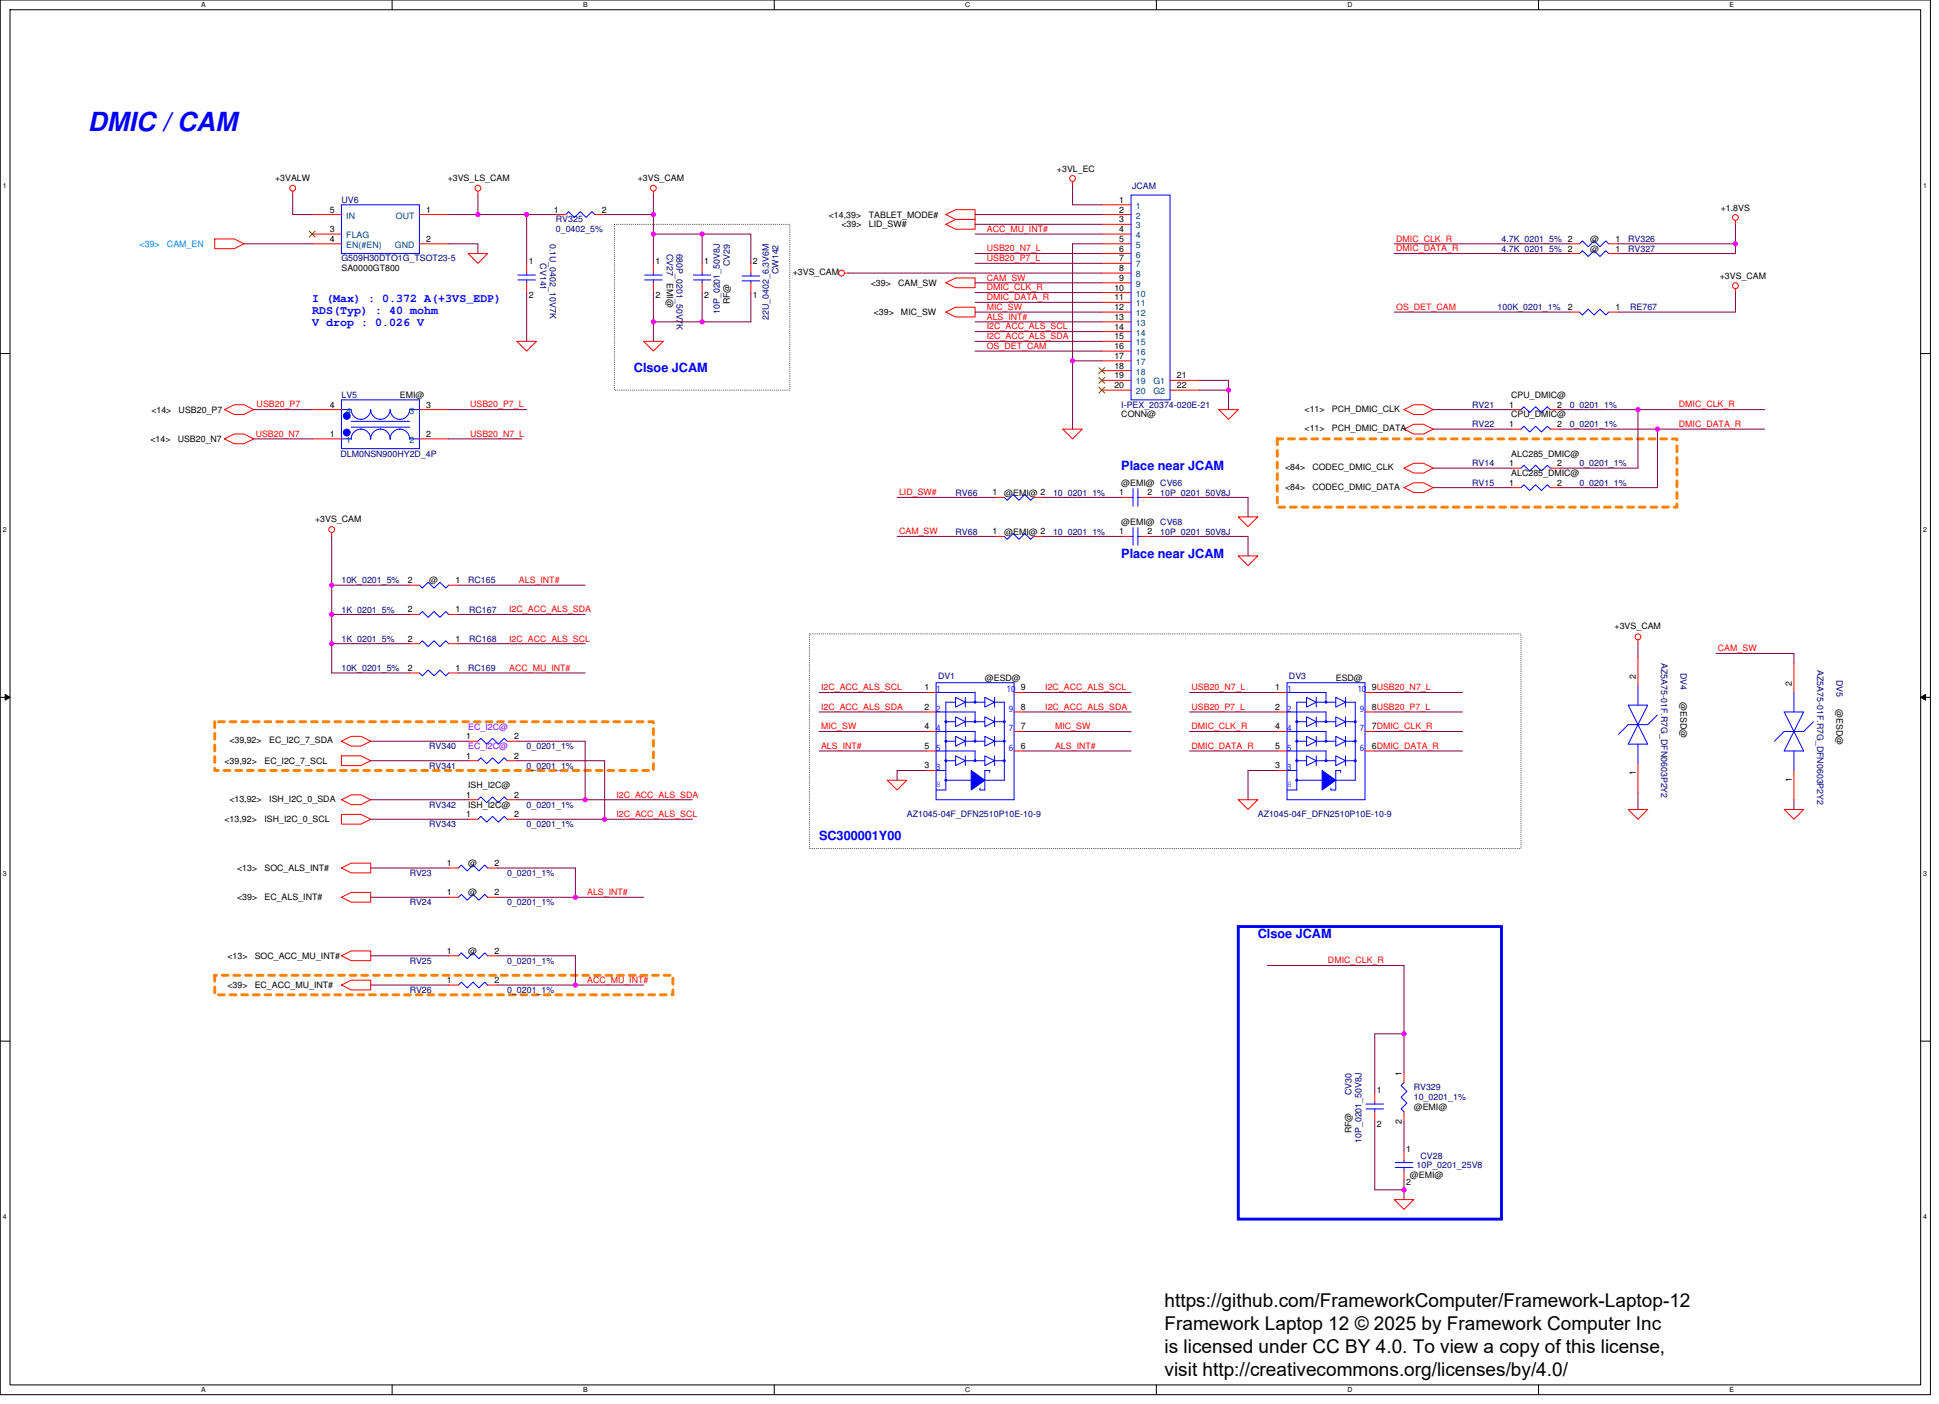
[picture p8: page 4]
Clsoe JCAM; Place near JCAM; <39> CAM_EN; <14> USB20_P7; <14> USB20_N7; <11> PCH_DMIC_CLK; <11> PCH_DMIC_DATA; <84> CODEC_DMIC_CLK; <84> CODEC_DMIC_DATA; <39,92> EC_I2C_7_SDA; <13,92> ISH_I2C_0_SDA; <13> SOC_ALS_INT#; <39> EC_ALS_INT#; <39,92> EC_I2C_7_SCL; <13,92> ISH_I2C_0_SCL; <14,39> TABLET_MODE# <39> LID_SW#; <39> CAM_SW; <39> MIC_SW; <13> SOC_ACC_MU_INT#; <39> EC_ACC_MU_INT#; +3VALW; +3VS_LS_CAM; +3VS_CAM; ALC285_DMIC@ 1 2; ISH_I2C@ 1 2; @EMI@ 1 2; RV329 10_0201_1% @EMI@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

RDS(Typ) : 40 mohm
V drop : 0.026 V

Place near JCAM

# NGFF SSD (KEY M)

# PCIE Gen4

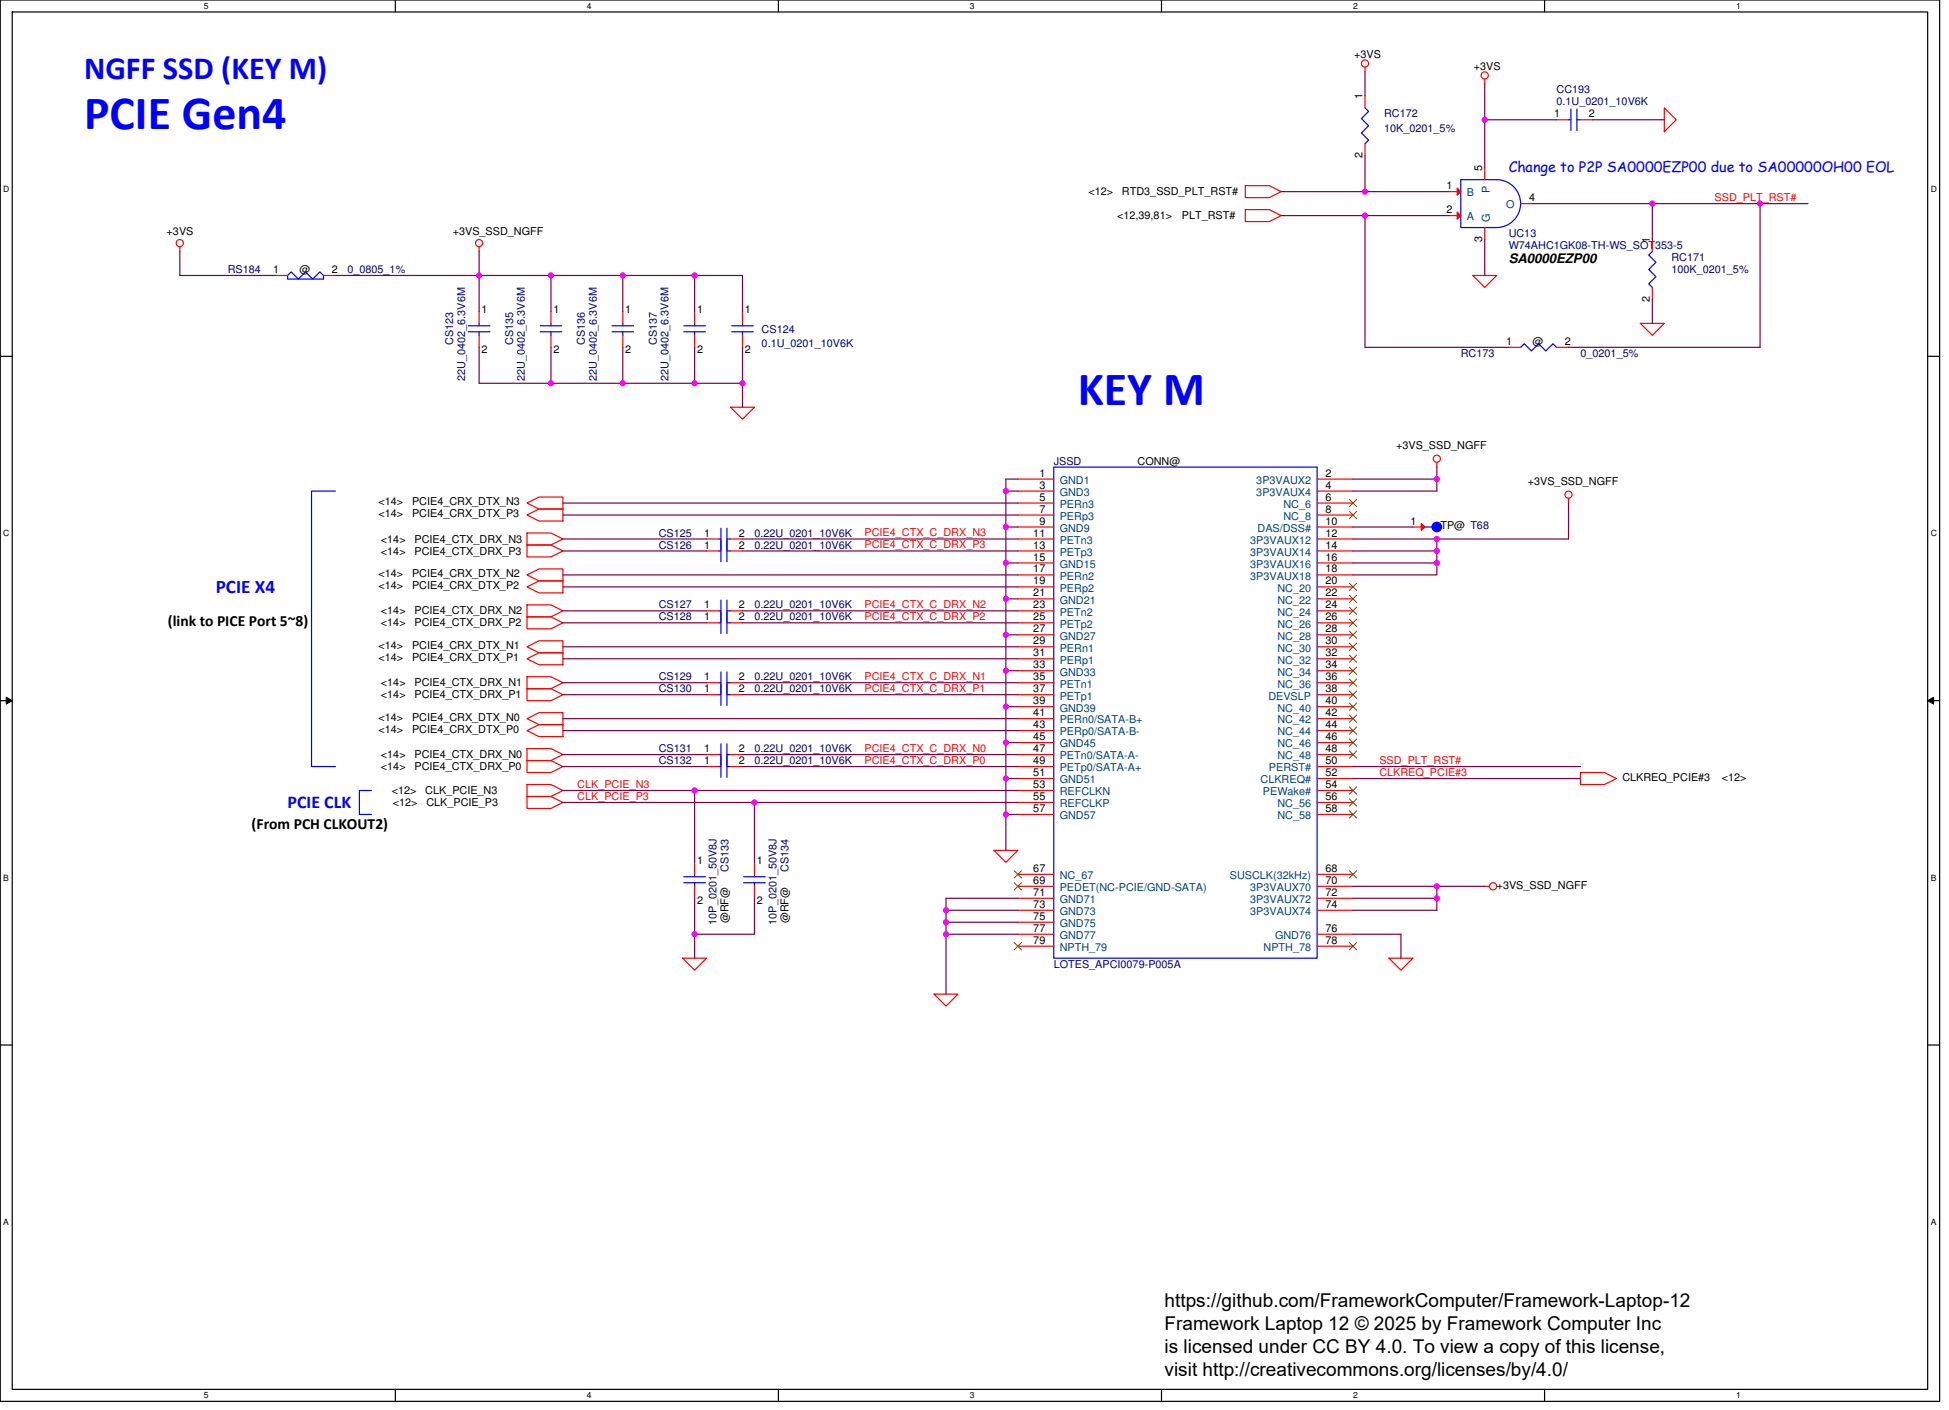
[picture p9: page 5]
PCIE CLK; (From PCH CLKOUT2); PCIE X4; KEY M; CLKREQ_PCIE#3 <12>; <12> CLK_PCIE_P3; <12> CLK_PCIE_N3; <14> PCIE4_CTX_DRX_N3 <14> PCIE4_CTX_DRX_P3; <14> PCIE4_CRX_DTX_N3 <14> PCIE4_CRX_DTX_P3; <14> PCIE4_CTX_DRX_N2 <14> PCIE4_CTX_DRX_P2; <14> PCIE4_CTX_DRX_N1 <14> PCIE4_CTX_DRX_P1; <14> PCIE4_CTX_DRX_N0 <14> PCIE4_CTX_DRX_P0; <14> PCIE4_CRX_DTX_N2 <14> PCIE4_CRX_DTX_P2; <14> PCIE4_CRX_DTX_N1 <14> PCIE4_CRX_DTX_P1; <14> PCIE4_CRX_DTX_N0 <14> PCIE4_CRX_DTX_P0; <12> RTD3_SSD_PLT_RST#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

Change to P2P SA0000EZP00 due to SA00000OH00 EOL

(link to PICE Port 5~8)

# [PCIE+USB/CNVi]

# Main Func = NGFF WLAN / BT (Key E)

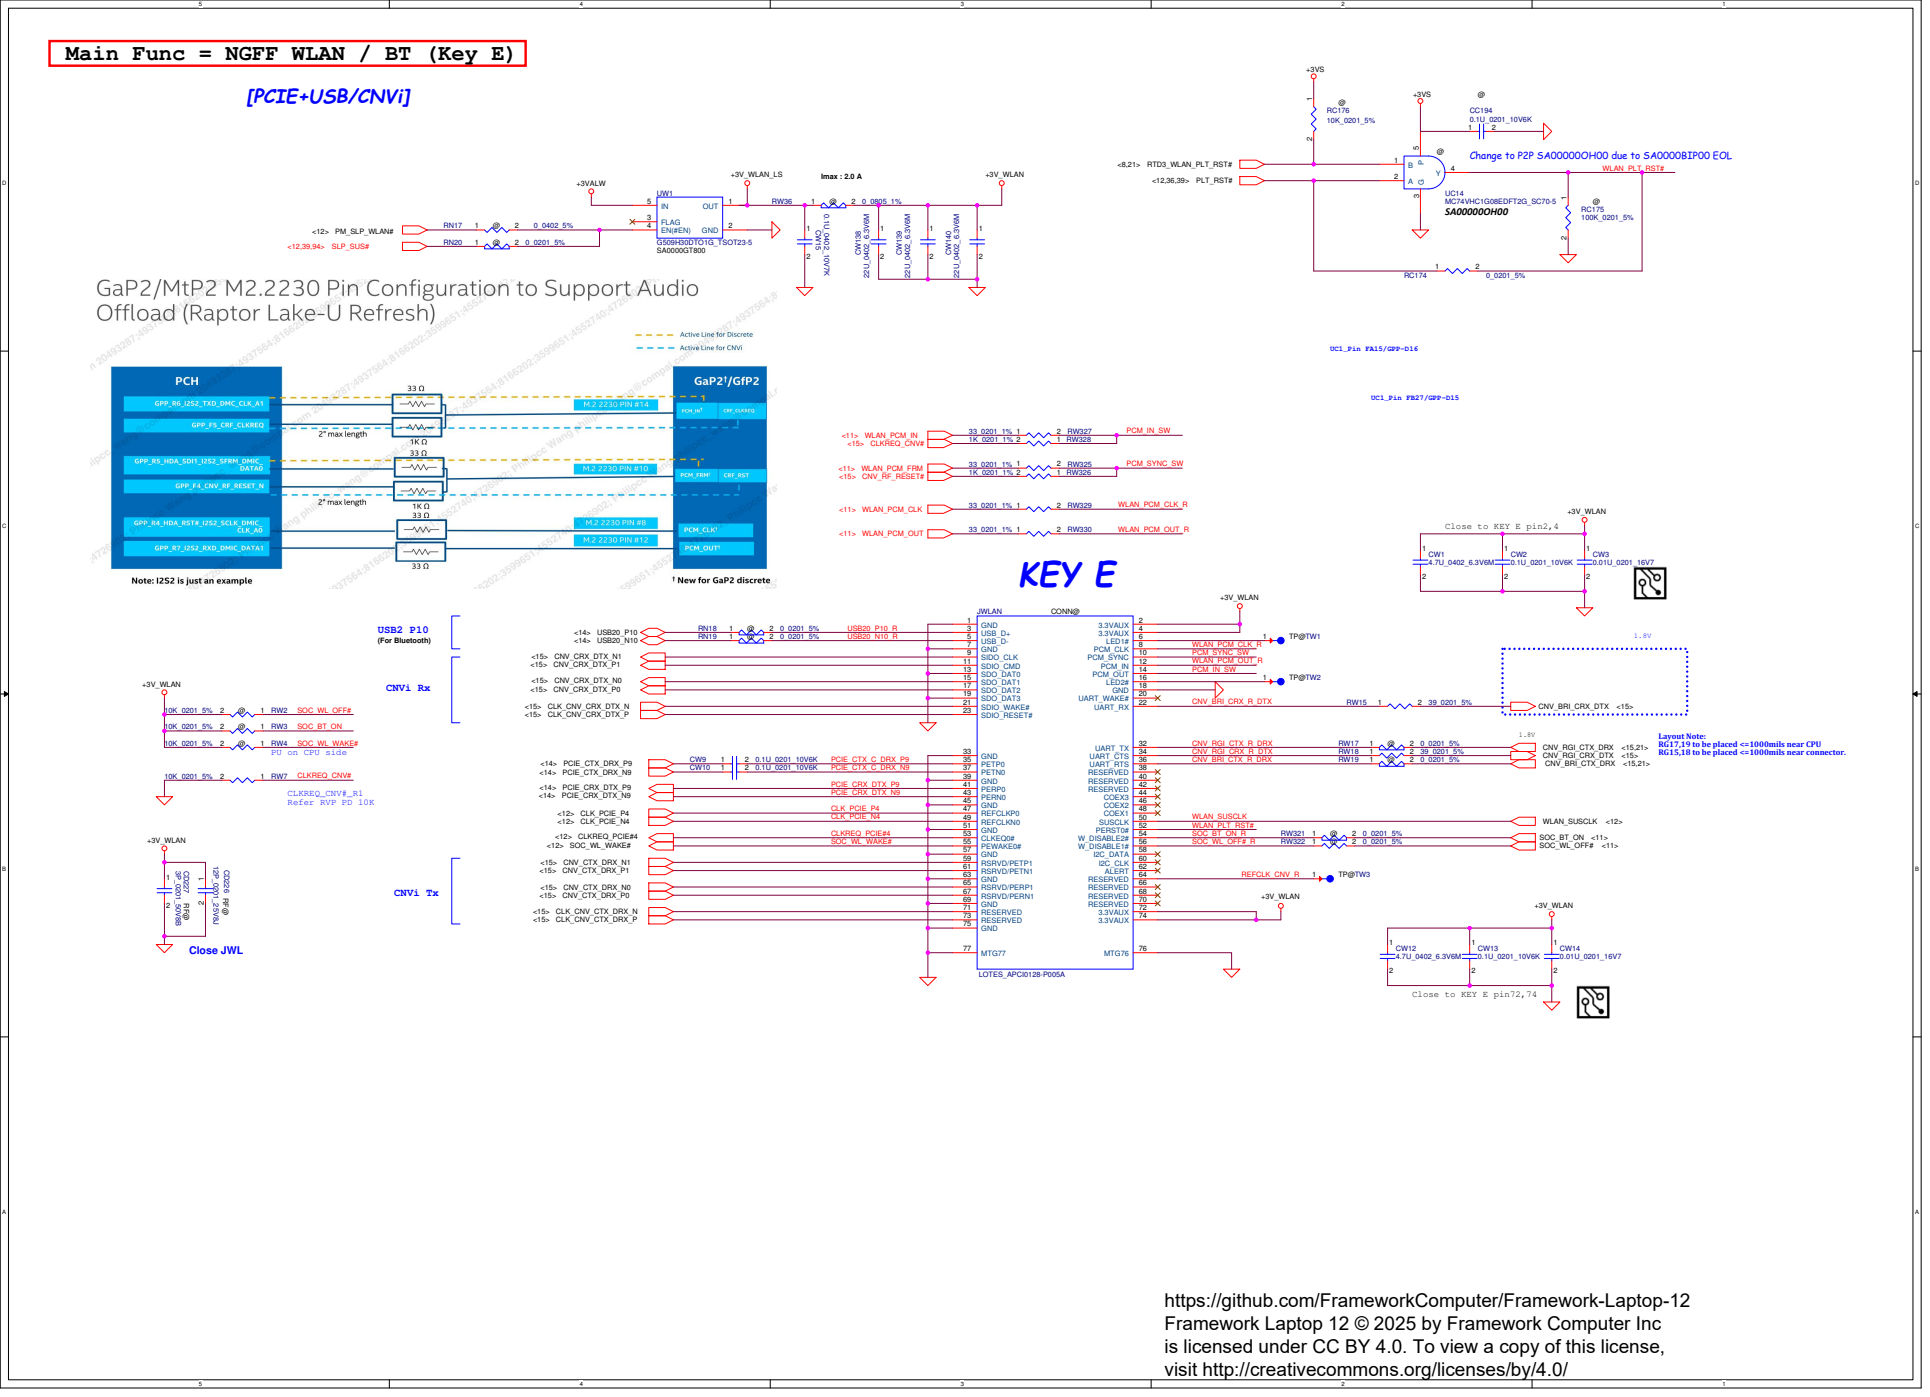
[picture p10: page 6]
CNVi Rx; USB2 P10; (For Bluetooth); CNVi Tx; KEY E; Close JWL; Imax : 2.0 A; UC1_Pin FB27/GPP-D15; UC1_Pin FA15/GPP-D16; SOC_WL_OFF# <11>; SOC_BT_ON <11>; WLAN_SUSCLK <12>; <14> USB20_P10 <14> USB20_N10; <15> CNV_CRX_DTX_N1 <15> CNV_CRX_DTX_P1; <15> CNV_CRX_DTX_N0 <15> CNV_CRX_DTX_P0; <15> CLK_CNV_CRX_DTX_N <15> CLK_CNV_CRX_DTX_P; <14> PCIE_CTX_DRX_P9 <14> PCIE_CTX_DRX_N9; <14> PCIE_CRX_DTX_P9 <14> PCIE_CRX_DTX_N9; <12> CLK_PCIE_P4 <12> CLK_PCIE_N4; <12> CLKREQ_PCIE#4 <12> SOC_WL_WAKE#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

Change to P2P SA00000OH00 due to SA0000BIP00 EOL

Close to KEY E pin2,4

PU on CPU side

Layout Note:
RG17,19 to be placed <=1000mils near CPU
RG15,18 to be placed <=1000mils near connector.

CLKREQ_CNV#_R1
Refer RVP PD 10K

Close to KEY E pin72,74

Touch Pad | EC
KB MCU | EC

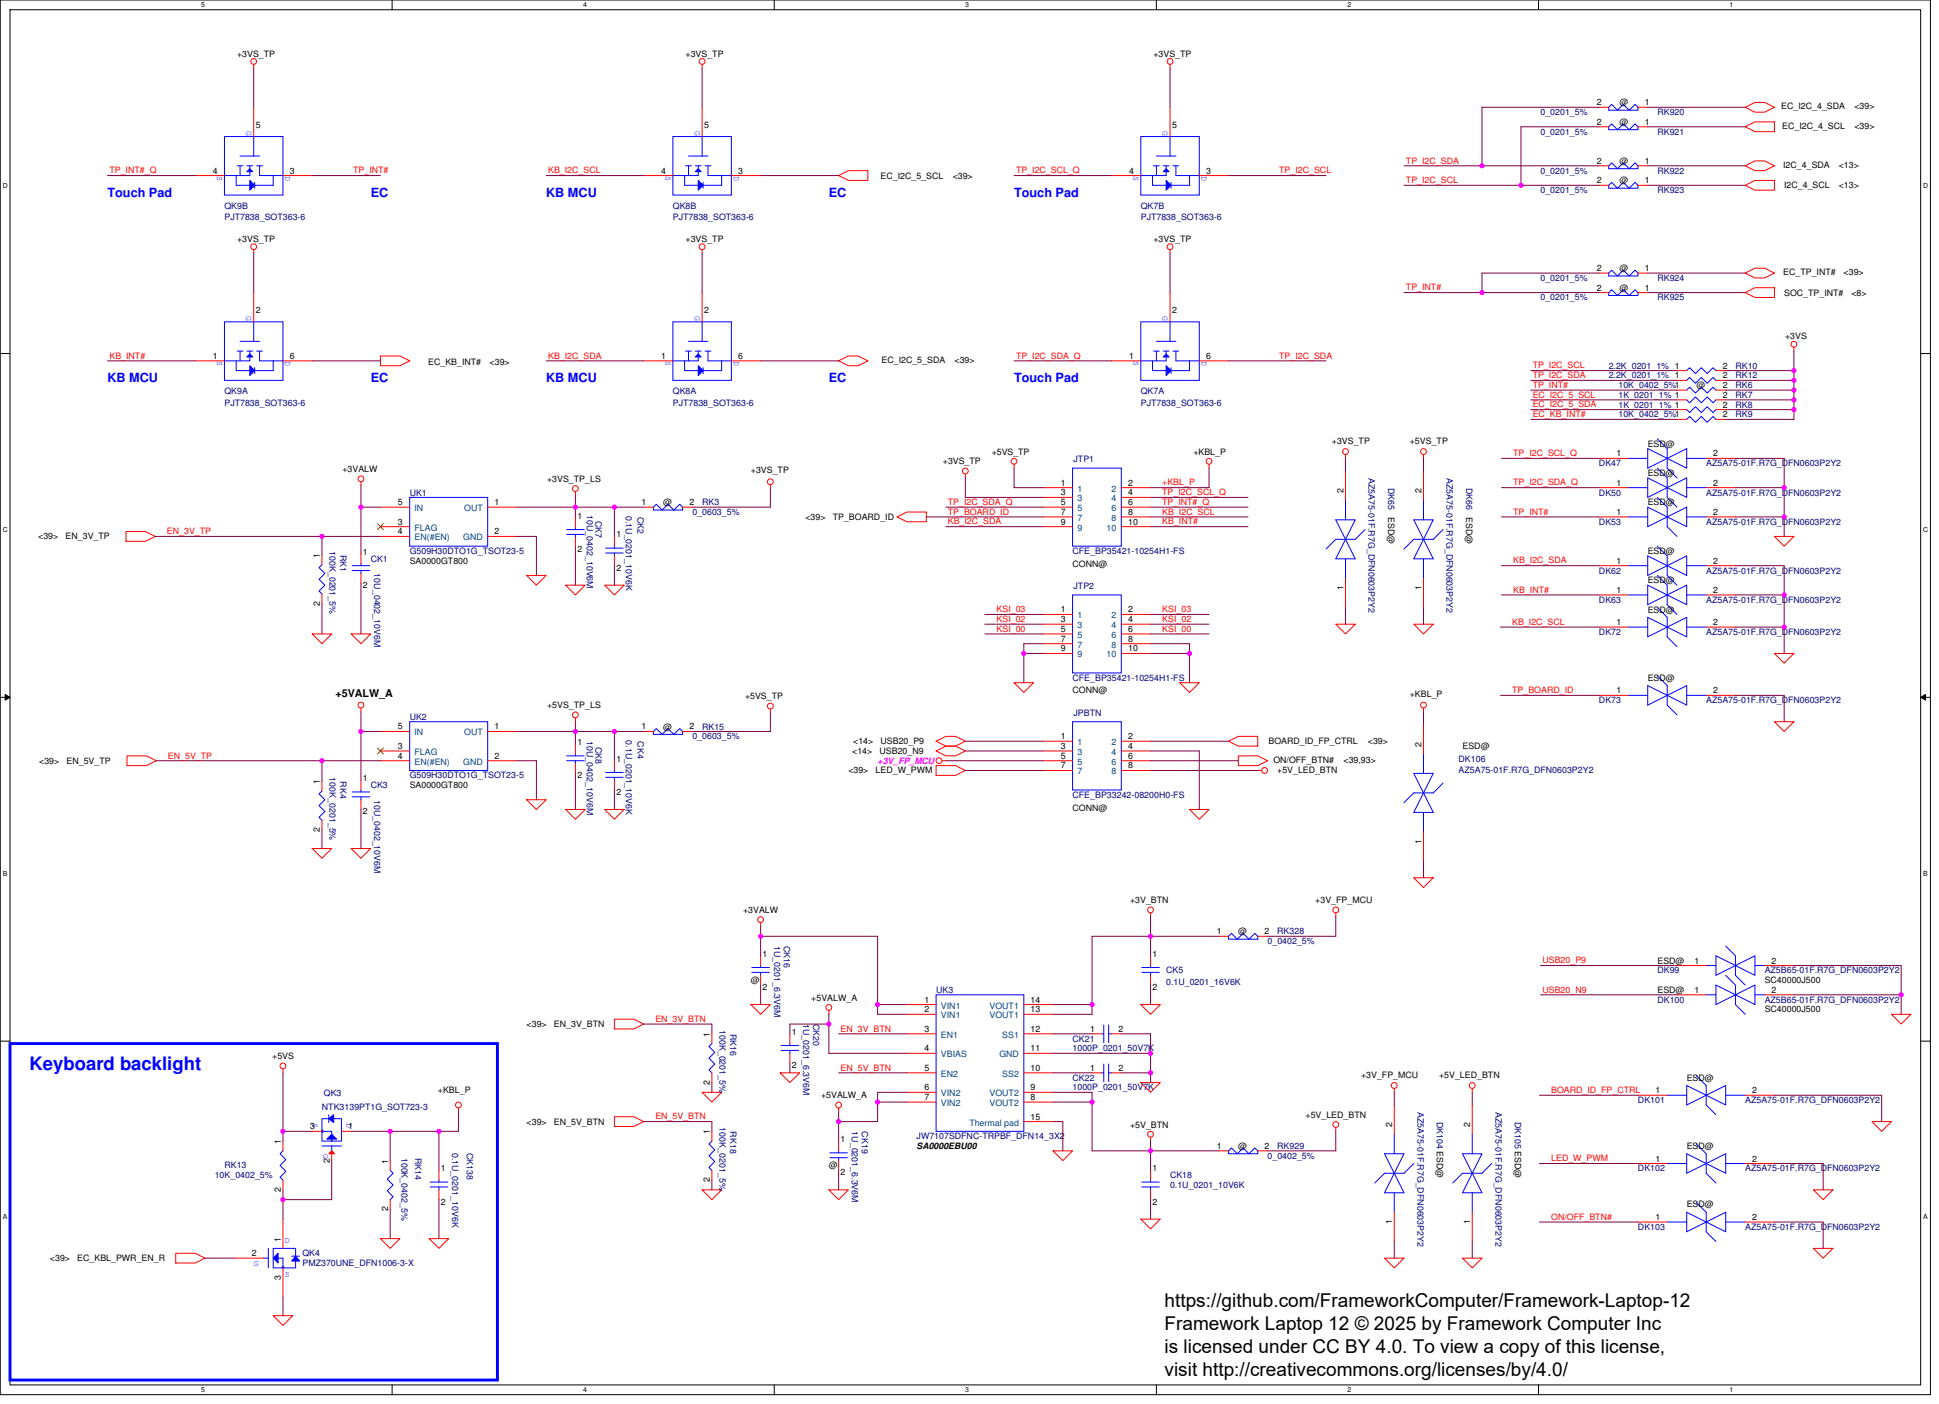
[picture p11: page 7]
Keyboard backlight; KB MCU; Touch Pad; EC_I2C_4_SDA <39>; EC_I2C_4_SCL <39>; I2C_4_SDA <13>; I2C_4_SCL <13>; EC_TP_INT# <39>; SOC_TP_INT# <8>; <39> EC_KBL_PWR_EN_R; <39> TP_BOARD_ID; EC_KB_INT# <39>; EC_I2C_5_SCL <39>; EC_I2C_5_SDA <39>; <14> USB20_P9; BOARD_ID_FP_CTRL; <14> USB20_N9; ON/OFF_BTN# <39,93>; <39> LED_W_PWM; <39> EN_3V_BTN; <39> EN_5V_BTN; +3VALW; +5VALW_A; +KBL_P; +3V_FP_MCU; +5V_LED_BTN; +3V_BTN; +5V_BTN; AZ5A75-01F.R7G_DFN0603P2Y2; ESD@; ESD@ 1 2; G509H30DTO1G_TSOT23-5; GND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

# Main Func = LED

W=20mil | W=20mil

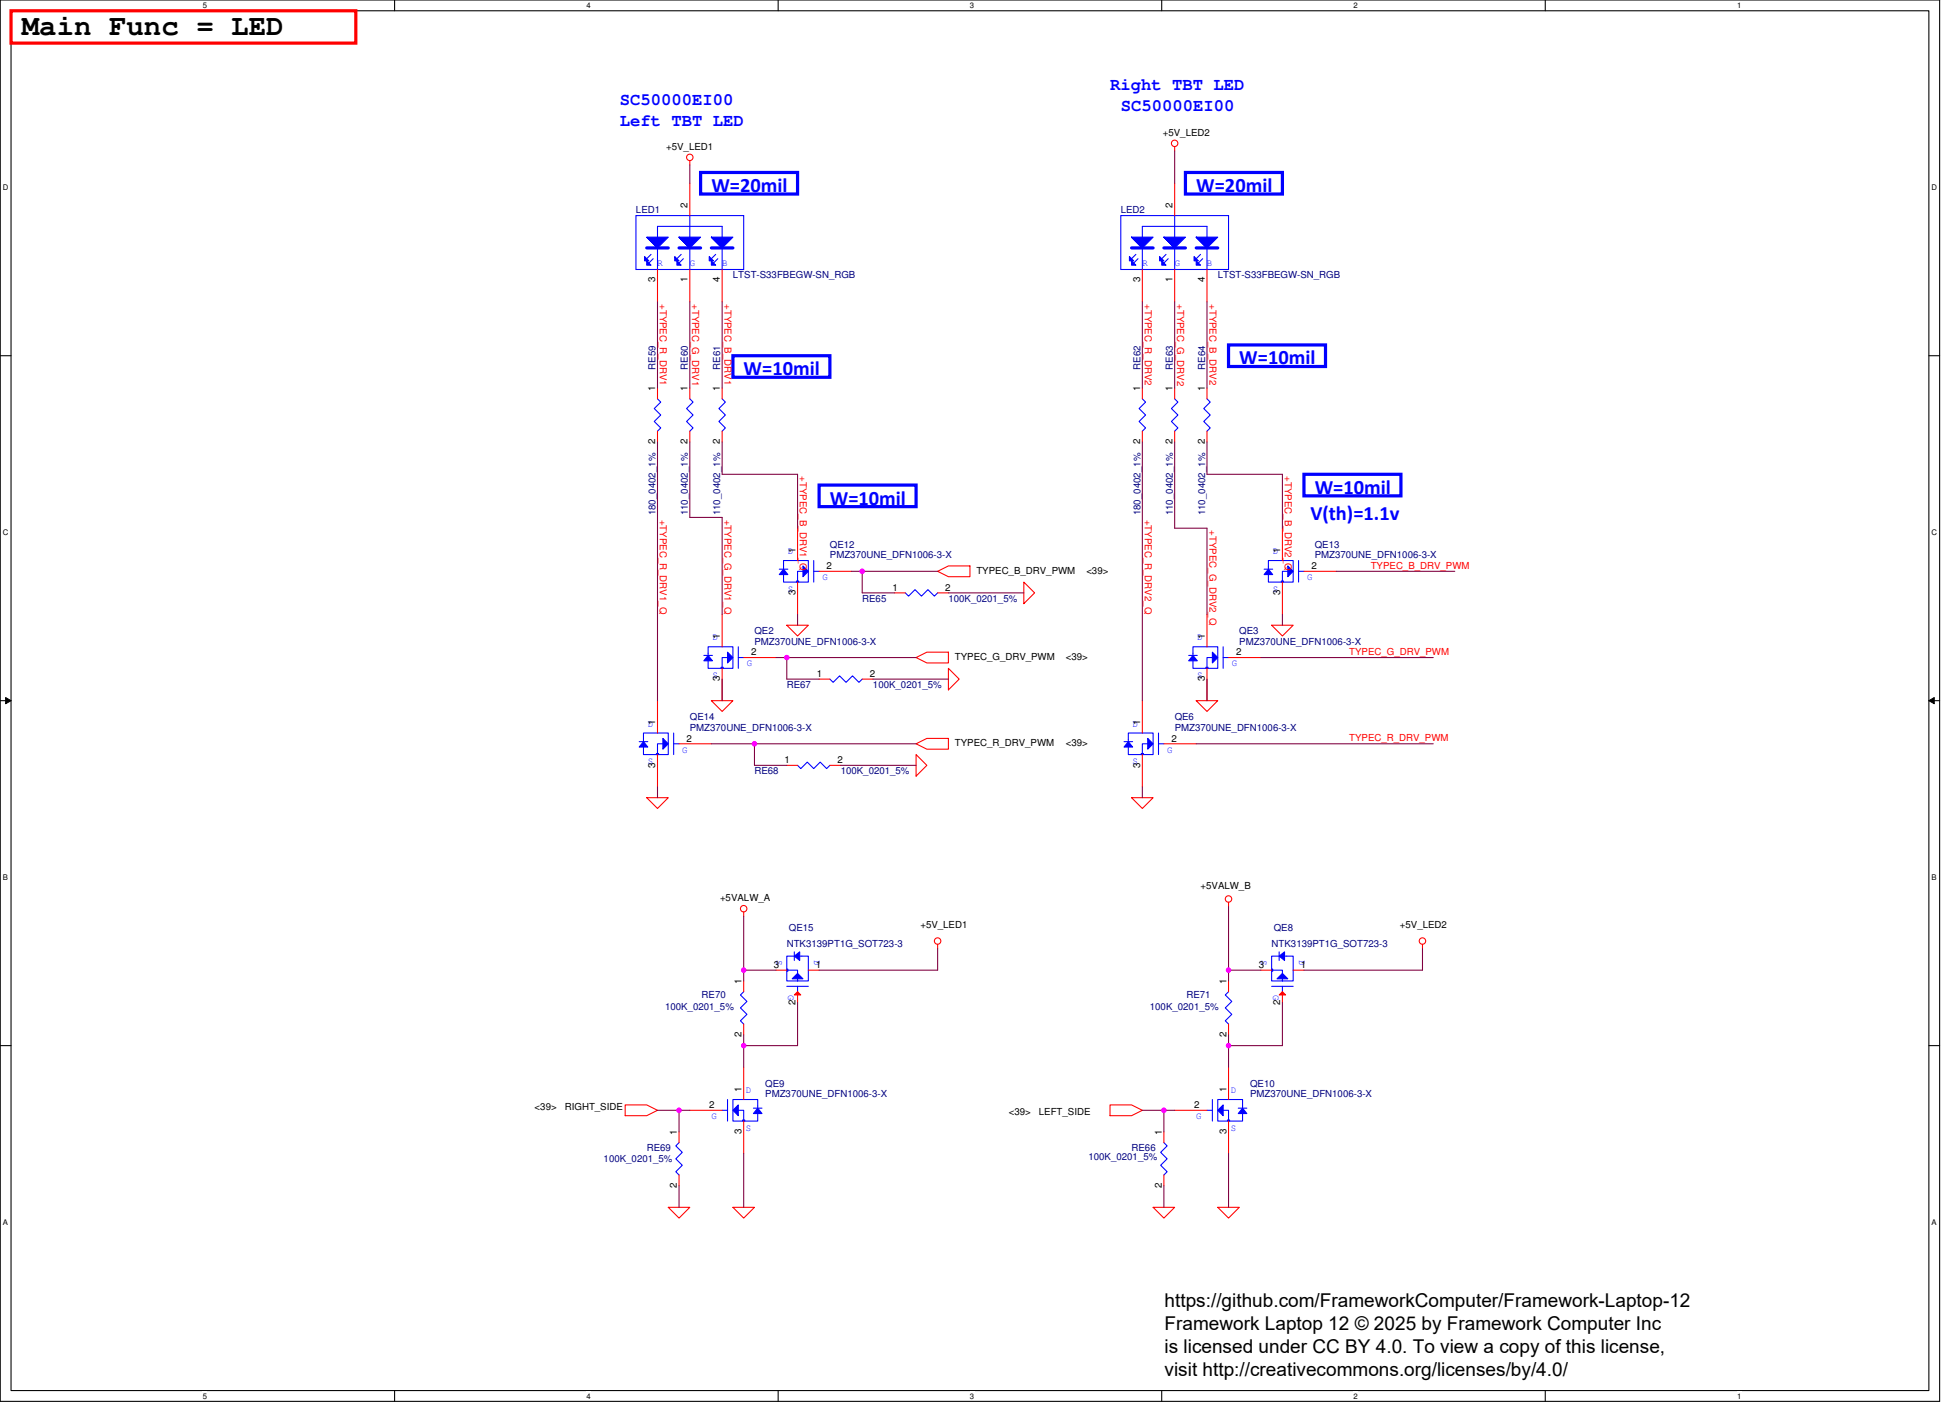
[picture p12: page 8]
W=10mil; W=10mil V(th)=1.1v; TYPEC_B_DRV_PWM <39>; TYPEC_R_DRV_PWM; <39> RIGHT_SIDE; <39> LEFT_SIDE; TYPEC_G_DRV_PWM <39>; +5V_LED1; +5V_LED2; +5VALW_B; +5VALW_A; QE10 PMZ370UNE_DFN1006-3-X; NTK3139PT1G_SOT723-3; QE3 PMZ370UNE_DFN1006-3-X 2; QE9 PMZ370UNE_DFN1006-3-X; QE13 PMZ370UNE_DFN1006-3-X 2; QE2 PMZ370UNE_DFN1006-3-X 2; QE6 PMZ370UNE_DFN1006-3-X 2; LED2; LTST-S33FBEGW-SN_RGB; QE14 PMZ370UNE_DFN1006-3-X 2; QE12 PMZ370UNE_DFN1006-3-X 2; LED1; +TYPEC_R_DRV1; +TYPEC_G_DRV1; +TYPEC_B_DRV1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

Right TBT LED

Left TBT LED

# Main Func = Sensor_TPM_LED

## +3VS_ACC

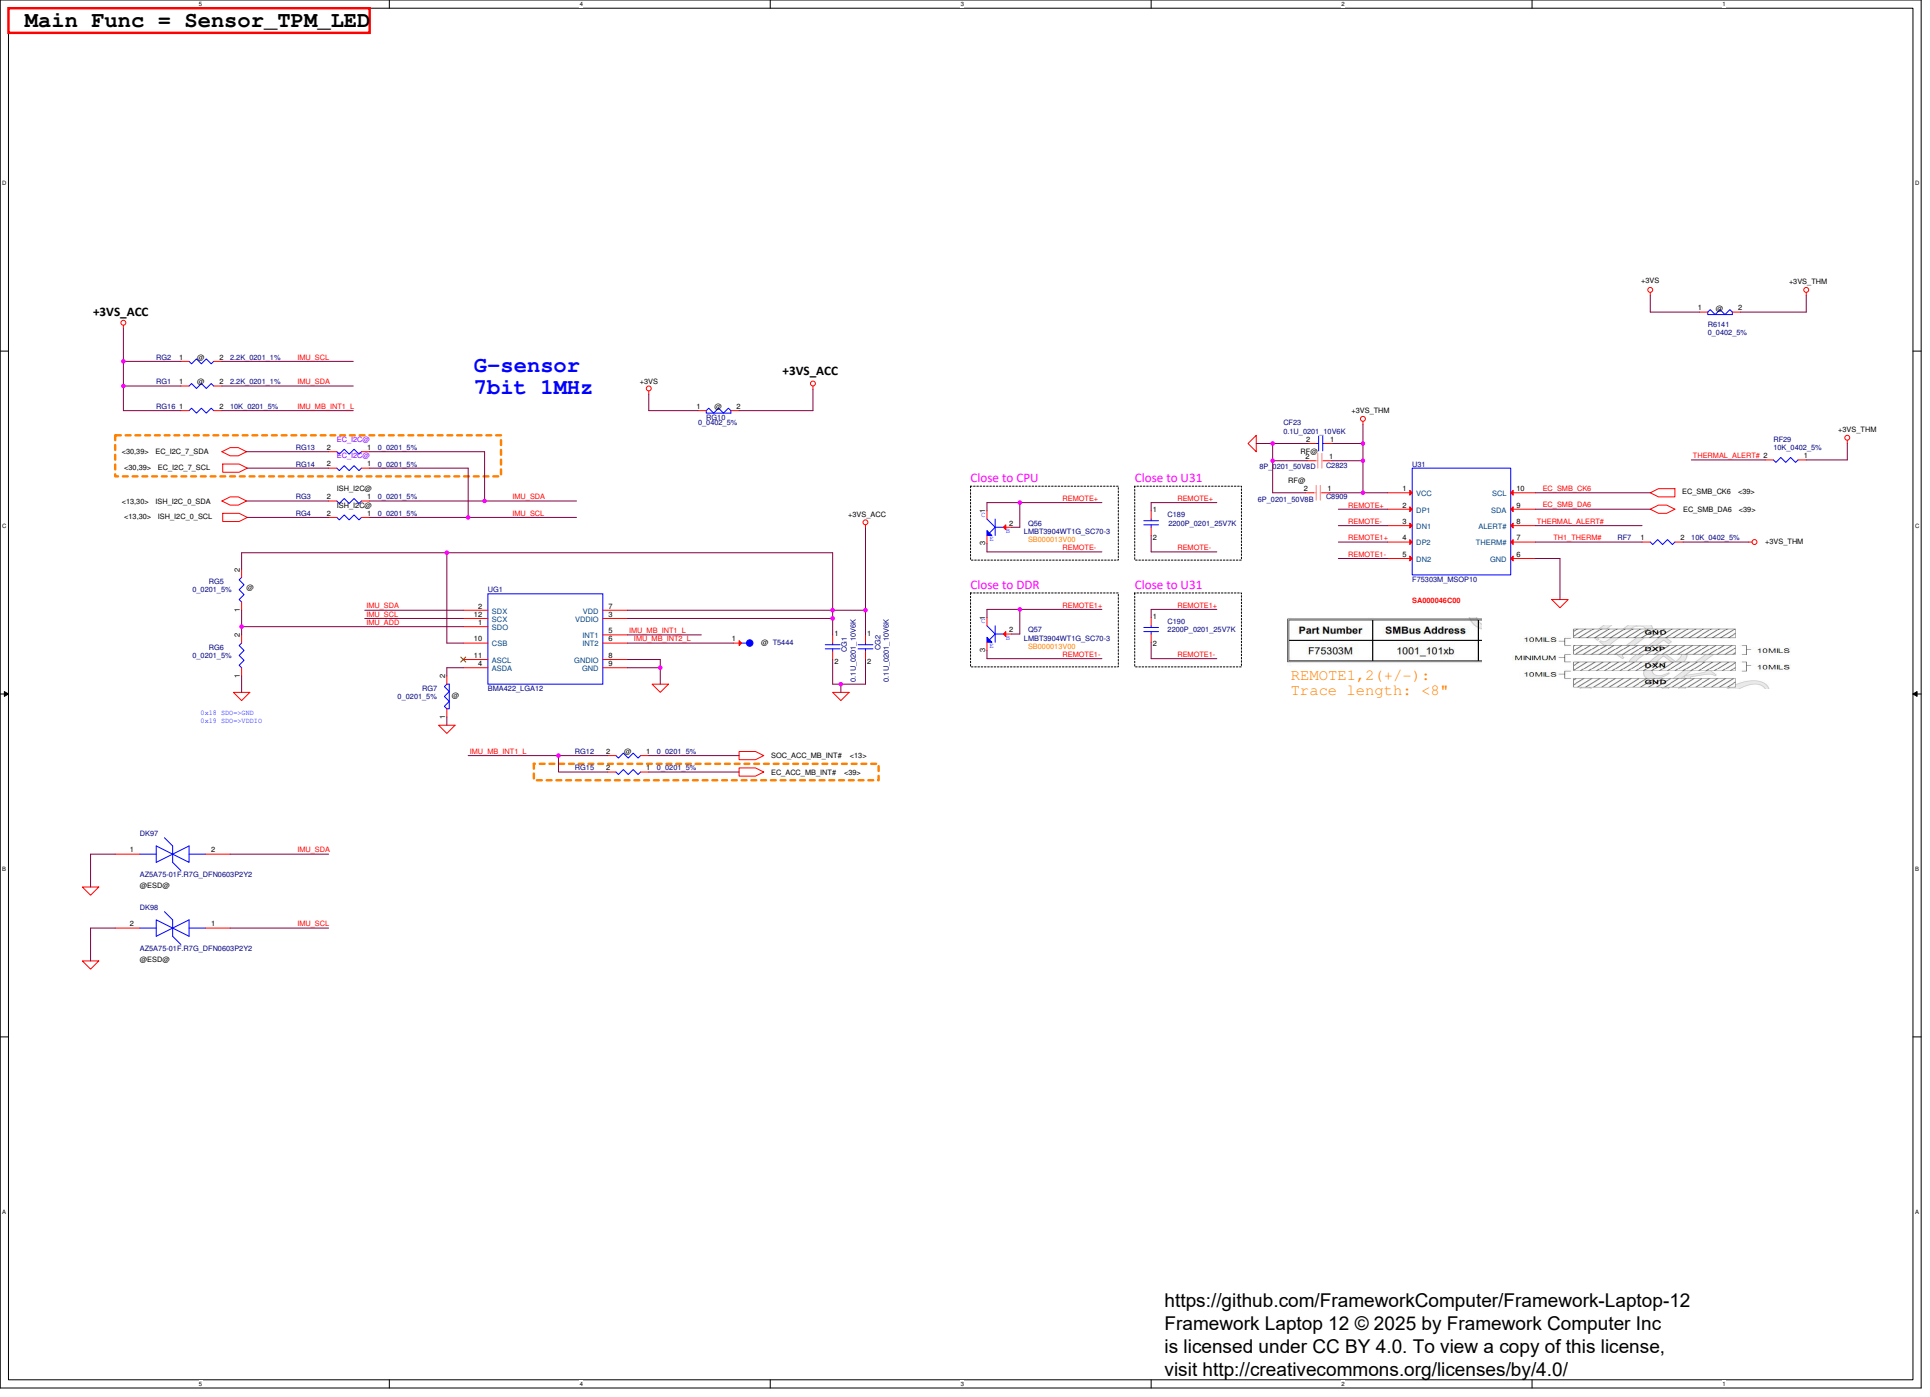
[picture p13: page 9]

# CPU Fan Control Circuit

# Power Button

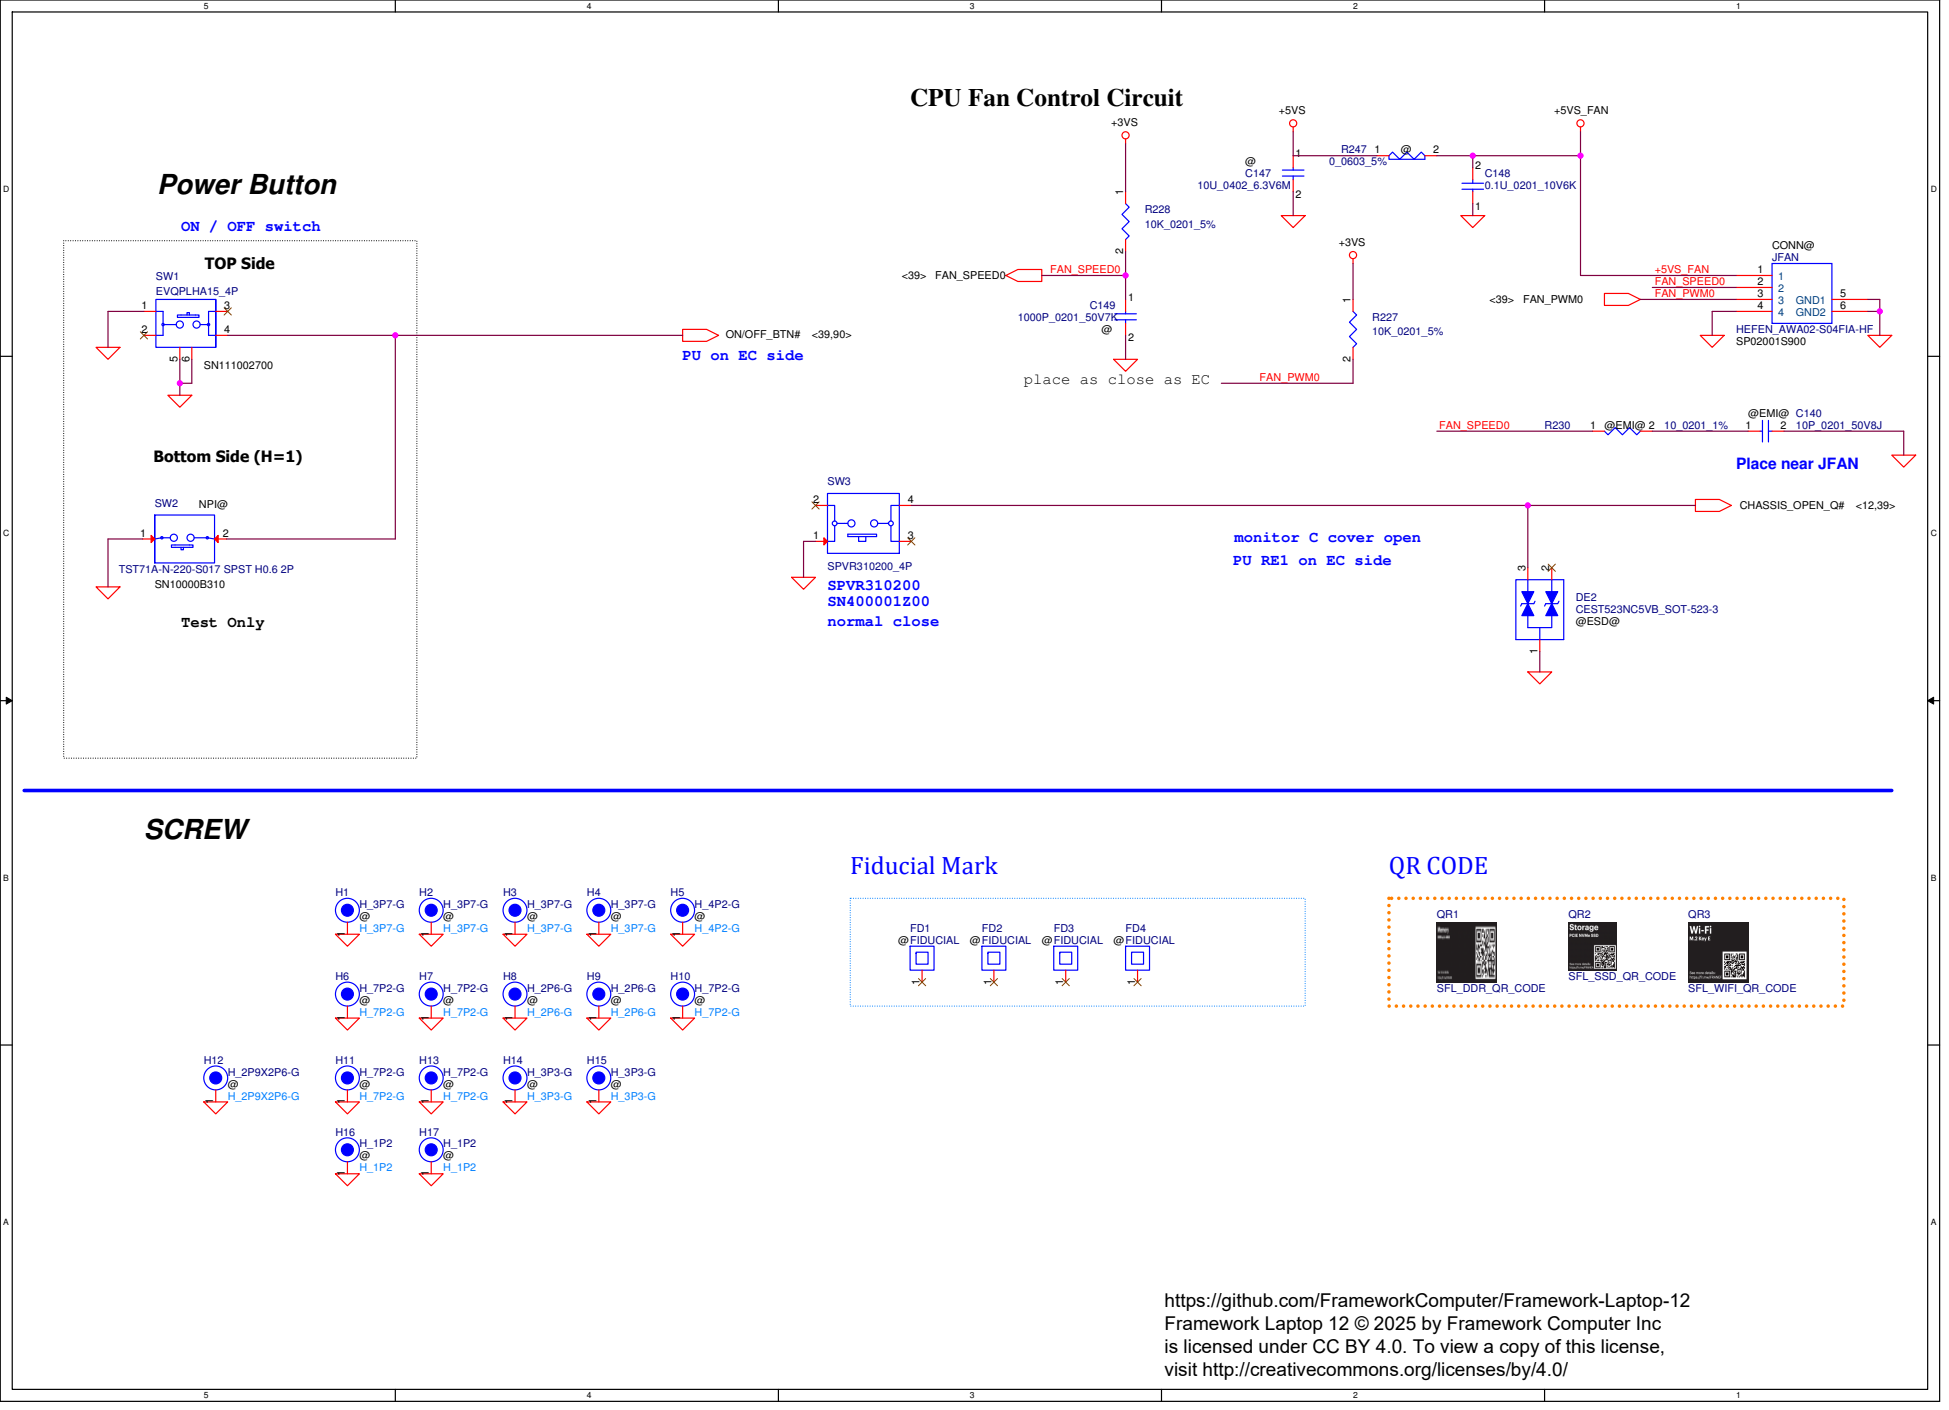
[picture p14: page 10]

PU on EC side

place as close as EC

monitor C cover open
PU RE1 on EC side
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

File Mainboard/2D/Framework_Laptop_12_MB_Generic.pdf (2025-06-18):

2

1

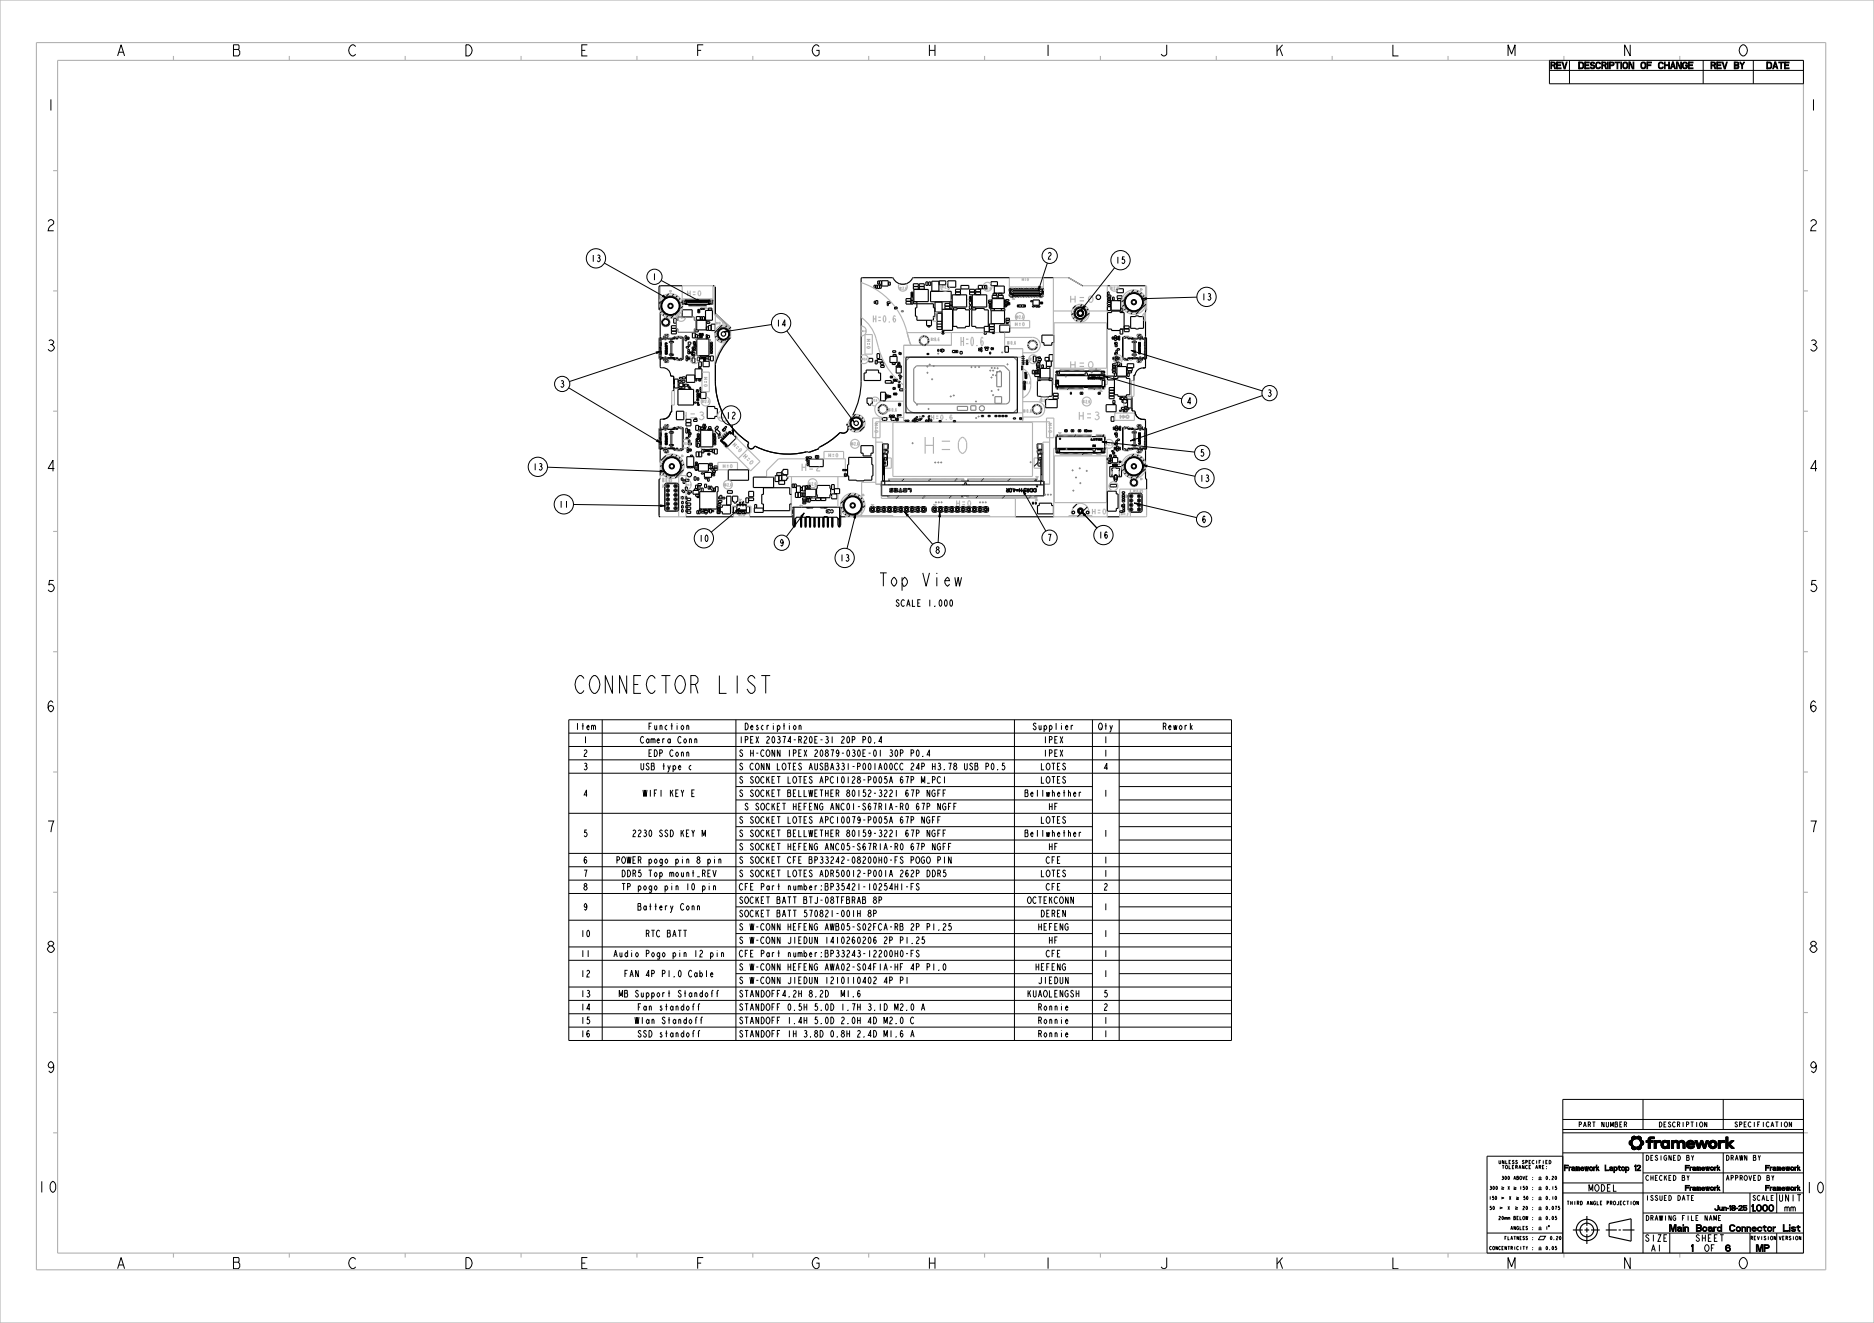
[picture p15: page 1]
PART NUMBER; DESCRIPTION; SPECIFICATION; Framework Laptop 12 MODEL; SIZE; SHEET; REVISION; VERSION; REV; DESCRIPTION OF CHANGE; REV BY; DATE; UNLESS SPECIFIED TOLERANCE ARE:; 300 ABOVE :; 20mm BELOW :; ANGLES :; FLATNESS :; CONCENTRICITY :; Top View; CONNECTOR LIST; SCALE 1.000

Item | Function | Description | Supplier | Qty | Rework
1 | Camera Conn | IPEX 20374-R20E-31 20P P0.4 | IPEX | 1
2 | EDP Conn | S H-CONN IPEX 20879-030E-01 30P P0.4 | IPEX | 1
3 | USB type c | S CONN LOTES AUSBA331-P001A00CC 24P H3.78 USB P0.5 | LOTES | 4
4 | WIFI KEY E | S SOCKET LOTES APCI0128-P005A 67P M_PCI | LOTES | 1

S SOCKET BELLWETHER 80152-3221 67P NGFF | Bellwhether
S SOCKET HEFENG ANC01-S67RIA-R0 67P NGFF | HF
S SOCKET BELLWETHER 80159-3221 67P NGFF | Bellwhether
S SOCKET HEFENG ANC05-S67RIA-R0 67P NGFF | HF

5 | 2230 SSD KEY M | S SOCKET LOTES APCI0079-P005A 67P NGFF | LOTES | 1

6 | POWER pogo pin 8 pin | S SOCKET CFE BP33242-08200H0-FS POGO PIN | CFE | 1
7 | DDR5 Top mount_REV | S SOCKET LOTES ADR50012-P001A 262P DDR5 | LOTES | 1
8 | TP pogo pin 10 pin | CFE Part number:BP35421-10254H1-FS | CFE | 2
9 | Battery Conn | SOCKET BATT BTJ-08TFBRAB 8P | OCTEKCONN | 1
10 | RTC BATT | S W-CONN HEFENG AWB05-S02FCA-RB 2P P1.25 | HEFENG | 1
11 | Audio Pogo pin 12 pin | CFE Part number:BP33243-12200H0-FS | CFE | 1
12 | FAN 4P P1.0 Cable | S W-CONN HEFENG AWA02-S04FIA-HF 4P P1.0 | HEFENG | 1
13 | MB Support Standoff | STANDOFF4.2H 8.2D M1.6 | KUAOLENGSH | 5
14 | Fan standoff | STANDOFF 0.5H 5.0D 1.7H 3.1D M2.0 A | Ronnie | 2
15 | Wlan Standoff | STANDOFF 1.4H 5.0D 2.0H 4D M2.0 C | Ronnie | 1
16 | SSD standoff | STANDOFF 1H 3.8D 0.8H 2.4D M1.6 A | Ronnie | 1

SOCKET BATT 570821-001H 8P | DEREN
S W-CONN JIEDUN 1410260206 2P P1.25 | HF

S W-CONN JIEDUN 1210110402 4P P1 | JIEDUN

DESIGNED BY Framework | DRAWN BY Framework
CHECKED BY Framework | APPROVED BY Framework

THIRD ANGLE PROJECTION | ISSUED DATE Jun-18-251.000 mm | SCALE | UNIT

DRAWING FILE NAME
Main Board Connector List

2

1

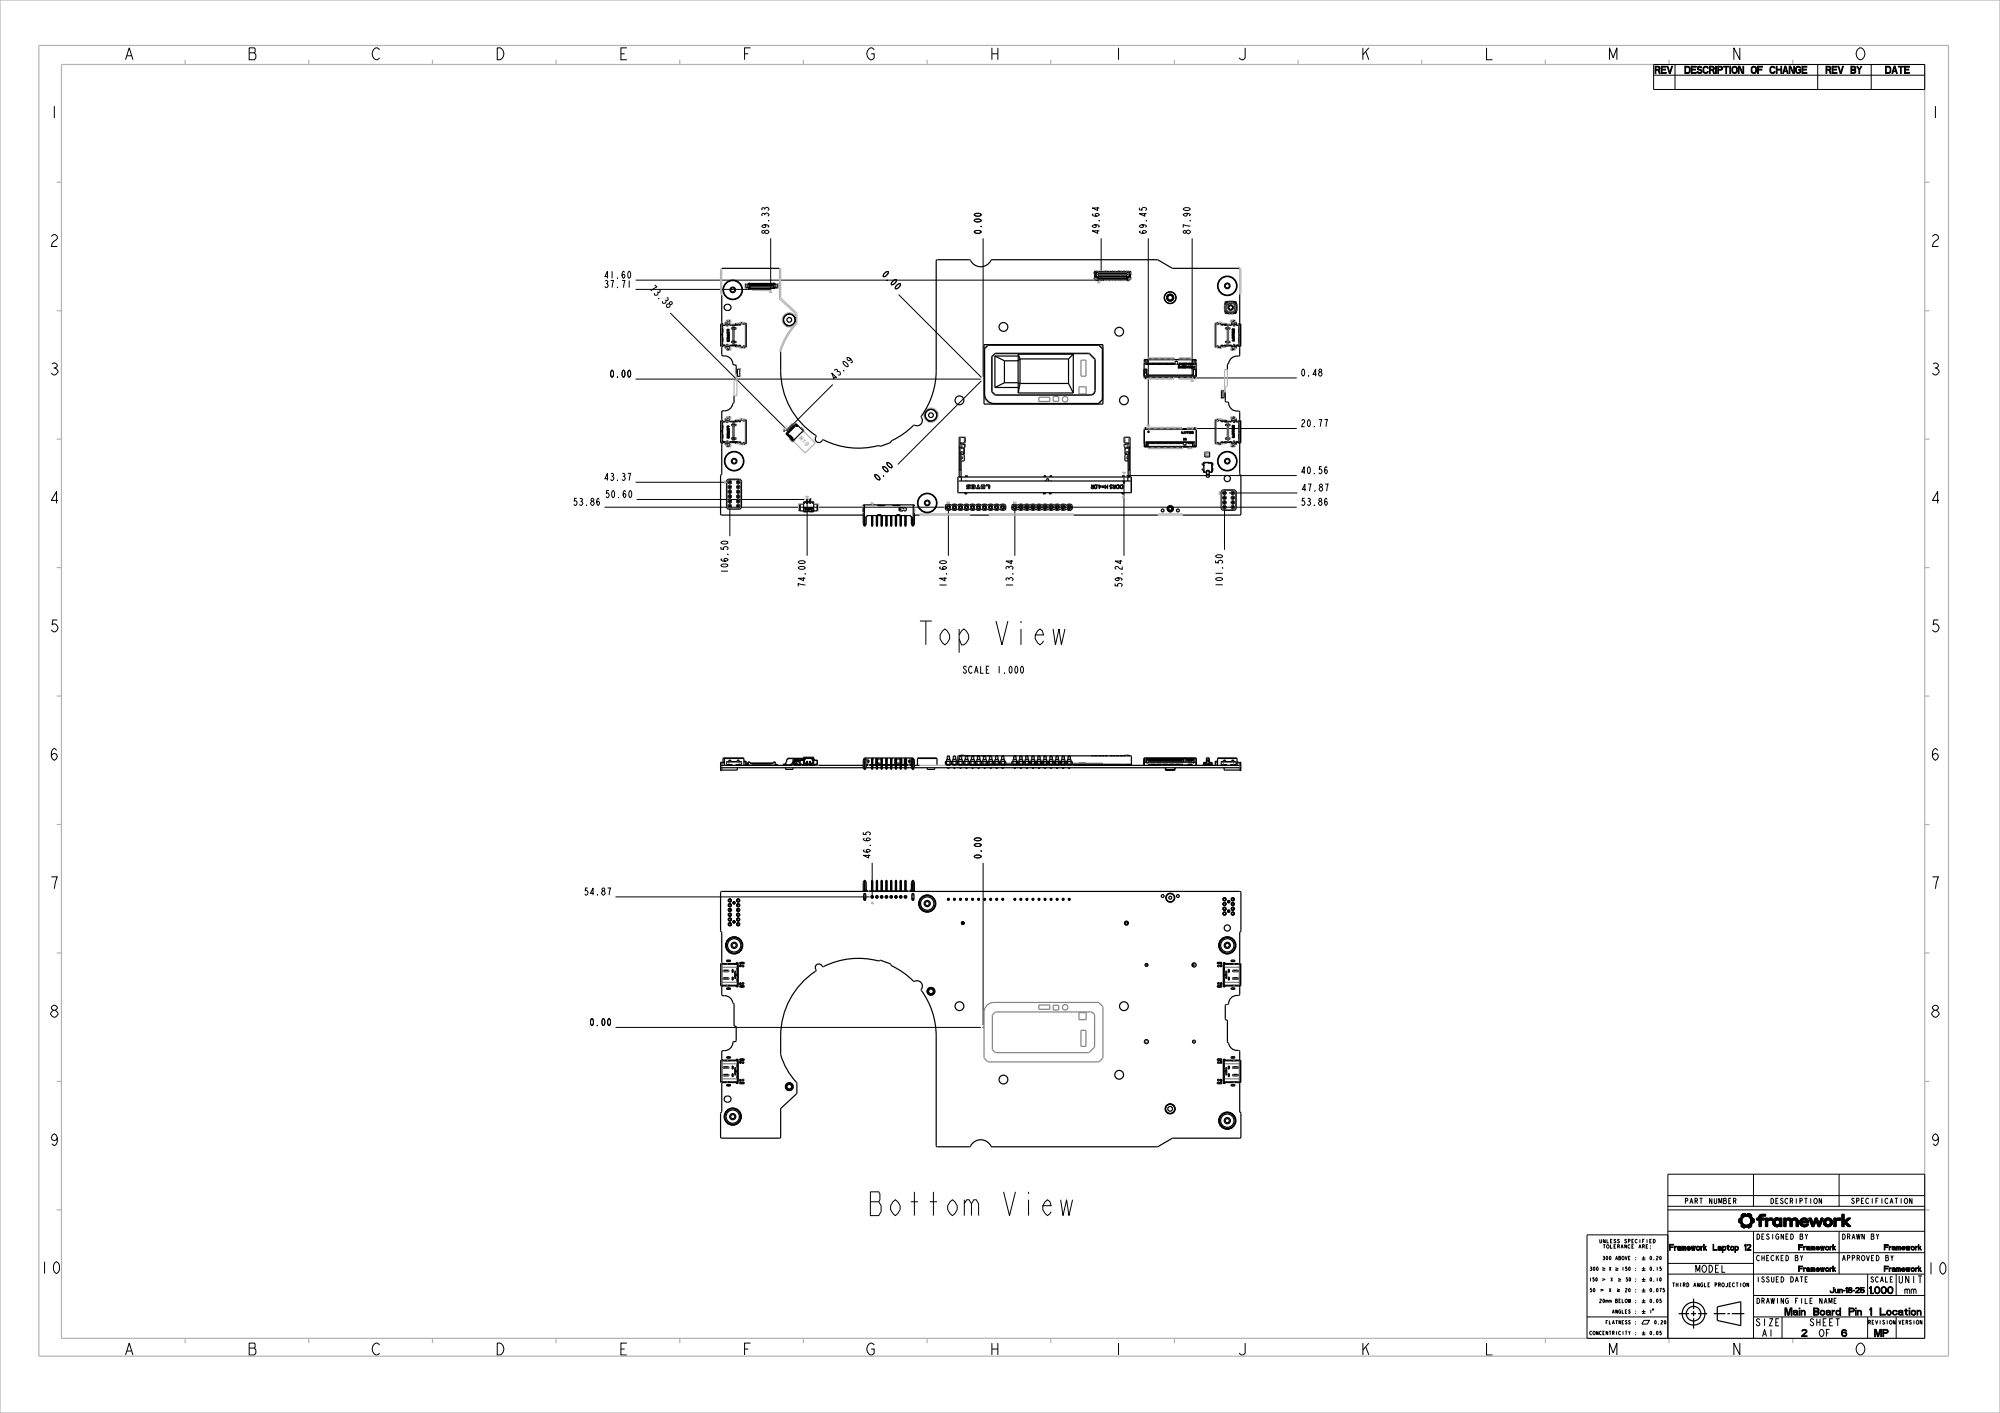
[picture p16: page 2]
PART NUMBER; DESCRIPTION; SPECIFICATION; Framework Laptop 12 MODEL; UNLESS SPECIFIED TOLERANCE ARE:; 300 ABOVE :; Top View; Bottom View; SCALE 1.000

DESIGNED BY Framework | DRAWN BY Framework
CHECKED BY Framework | APPROVED BY Framework

THIRD ANGLE PROJECTION | ISSUED DATE Jun-18-251.000 mm | SCALE | UNIT

Main Board Pin 1 Location

2

1

PART NUMBER; DESCRIPTION; SPECIFICATION; Framework Laptop 12 MODEL; UNLESS SPECIFIED TOLERANCE ARE:; 300 ABOVE :; SCALE 1.000

No test point (H=0)
(No solder balls)

Top View

Bottom View

DESIGNED BY Framework | DRAWN BY Framework
CHECKED BY Framework | APPROVED BY Framework

THIRD ANGLE PROJECTION | ISSUED DATE Jun-18-251.000 mm | SCALE | UNIT

Main Board Height Limit

B

C

PART NUMBER; DESCRIPTION; SPECIFICATION; Framework; Laptop; MODEL; Jun-18-251.000; Main; Board; Ground; Pad; UNLESS SPECIFIED TOLERANCE ARE:; 300 ABOVE :; Top View

Bottom View
GROUND PAD AREA H=0

DESIGNED BY Framework | DRAWN BY Framework
CHECKED BY Framework | APPROVED BY Framework

THIRD ANGLE PROJECTION | | ISSUED DATE | SCALE | UNIT

2

1

55.22(SSD); (SSD) 75.50; PART NUMBER; DESCRIPTION; SPECIFICATION; Framework; Laptop; MODEL; Jun-18-251.000; Main; Board; Outline; UNLESS SPECIFIED TOLERANCE ARE:; 300 ABOVE :; Bottom View; This area; can not; have stamp; hole

have stamp hole

Top View

DESIGNED BY Framework | DRAWN BY Framework
CHECKED BY Framework | APPROVED BY Framework

THIRD ANGLE PROJECTION | | ISSUED DATE | SCALE | UNIT

2

1

PART NUMBER; DESCRIPTION; SPECIFICATION; Framework; Laptop; MODEL; Jun-18-251.000; Main; Board; White; Printing Area; UNLESS SPECIFIED TOLERANCE ARE:; 300 ABOVE :; Top View; Bottom View; WHITE AREA H=0; White Area; White Line; White White

Screw White Mark
White Area

White Line

White(CPU BRCKAT)

DESIGNED BY Framework | DRAWN BY Framework
CHECKED BY Framework | APPROVED BY Framework

THIRD ANGLE PROJECTION | | ISSUED DATE | SCALE | UNIT

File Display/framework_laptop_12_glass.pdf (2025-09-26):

SCALE 1,000

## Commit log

2024-12-11 Initial Framework 12 mainboard pinout
2025-06-06 Rename Input Deck to Input Cover
    That's the name we use on Framework 12
2025-06-06 Interface schematics coming soon
2025-06-18 2D CAD of the Mainboard
    [Framework_Laptop_12_MB_Generic_P1.dxf, Framework_Laptop_12_MB_Generic_P2.dxf, Framework_Laptop_12_MB_Generic_P3.dxf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]
2025-09-09 Add interface schematics
2025-09-26 Coverglass drawings
    [framework_laptop_12_glass.dxf]
2025-10-18 Add touchpad I2C HID and silkscreen details
2025-10-27 Document display and touch pinout
    On the mainboard there's a single connector, on the touchscreen there is
    one for eDP and one for touch IC.
2025-12-17 Added surface CAD for Framework Laptop 12
2025-12-30 Add mainboard CAD file.
2025-12-30 Add Framework Laptop 12 banner photo.
2026-05-18 Powerbutton Board: Fix pin number typo
2026-08-05 Add Battery CAD
    [Framework_Laptop_12_50_Battery.stp]
